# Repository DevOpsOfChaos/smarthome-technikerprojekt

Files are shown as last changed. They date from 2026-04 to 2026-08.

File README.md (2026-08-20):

# smarthome-technikerprojekt

Smart-Home-Grundsystem – Technikerarbeit 2026

## Projektübersicht

Eigenständig entwickeltes, lokal betriebenes Smart-Home-Grundsystem mit selbst aufgebauten Mikrocontrollergeräten, ESP-NOW-Funkkommunikation und Node-RED-Dashboard.

- **Keine Cloud** – alles läuft lokal
- **Keine Herstellerbindung** – ESP32-C3, eigene Platinen, eigene Firmware
- **Vollständig nachvollziehbar** – von der Platine bis zur Bedienoberfläche

## Architektur

```
Geräte (ESP32-C3) ──ESP-NOW──▶ Master ──MQTT──▶ Server (Raspberry Pi)
                                                 ├── Mosquitto (Broker)
                                                 ├── Node-RED (Logik + Dashboard)
                                                 └── SQLite (Persistenz)
```

## Gerätetypen

| Typ | Instanzen | Funktion |
|-----|---|---|
| **net_erl** | Hall-Light, Kitchen | Relais, Umweltsensorik, Bewegung |
| **net_zrl** | Rollladen | 2-Relais-Steuerung, Kalibrierung |
| **net_sen** | Außensensor | BME280, VEML7700, Regensensor |
| **bat_sen** | Regen, Fenster | Batteriebetrieb, Deep-Sleep |

## Repository-Struktur

| Verzeichnis | Inhalt |
|---|---|
| `firmware/` | **Hauptbestandteil** – PlatformIO-Projekt mit Basistypen und konkreten Geräteinstanzen |
| `hardware/` | KiCAD-Schaltpläne, Platinenlayouts, 3D-Modelle |
| `server/` | Docker-Compose-Stack (Mosquitto, Node-RED, SQLite) |
| `docs/` | Technische Dokumentation und Referenz |
| `tests/` | Testskripte und Checklisten |
| `PROTOKOLL/` | Entwicklungs- und Testprotokolle (Nachweise) |
| `esphome/` | ESPHome-Alternativlinie (nicht Bestandteil der Technikerarbeit) |

## Zwei Firmware-Linien

### Eigene Firmware (Hauptlinie)
Die eigene C++-Firmware unter `firmware/` ist der Kern des Technikerprojekts. Sie nutzt:
- **Basistyp-Architektur** – wiederverwendbare Runtime-Klassen (`NetErlRuntime`, `NetSenRuntime`, etc.)
- **ESP-NOW** – direkte Funkkommunikation zwischen Geräten und Master
- **Master-Bridge** – Übersetzung zwischen ESP-NOW und MQTT
- **Vollständige Kontrolle** – Timing, Provisionierung, Fehlerbehandlung in eigenem Code

### ESPHome-Alternative
Unter `esphome/` liegt eine alternative MQTT-Linie für Nutzer, die ESPHome oder Home Assistant bevorzugen. Diese Geräte sprechen direkt MQTT mit demselben Serververtrag. Die ESPHome-Linie ist nicht Bestandteil der Technikerarbeit, sondern eine praktische Erweiterung für Anwender.

## Quick Start

### Server starten
```bash
cd server
docker compose up -d
```
Dashboard: http://localhost:1880/ui

### Firmware bauen
```bash
cd firmware
pio run -e net_erl_hall_light -t upload
```

## Technologien

- **MCU:** ESP32-C3 (RISC-V)
- **Kommunikation:** ESP-NOW (lokal), MQTT (Server)
- **Server:** Node-RED, Mosquitto, SQLite, Docker
- **Firmware:** PlatformIO, Arduino-Framework
- **Hardware:** KiCAD, Eigenentwurf

## Lizenz

All rights reserved. Dieses Repository ist Teil einer schulischen Prüfungsleistung.  
Nach Abschluss der Prüfung behält sich der Autor einen Wechsel auf eine freizügigere Lizenz vor.

## Autor

Manuel Ries – Heinrich-Hertz-Schule Karlsruhe – Technikerarbeit 2026

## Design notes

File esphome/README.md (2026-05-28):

# Alternative MQTT-Linie

Diese Linie ist fuer direkt angebundene MQTT-Geraete vorbereitet. Die Geraete sprechen direkt MQTT mit dem Serververtrag. Es gibt hier keinen ESP-NOW-Master und keine MQTT-Bridge.

Die harte Regel: Topics und Payload-Felder bleiben kompatibel zur bisherigen Firmware, damit Node-RED nur den MQTT-Vertrag sieht.

## Import in Home Assistant

Kopiere den kompletten Ordner in die passende Home-Assistant-Konfiguration, damit die relativen `packages/`-Includes funktionieren.

Danach kannst du die Dateien aus `devices/` importieren oder als neue YAML anlegen. Die benoetigten Secret-Werte liegen in Home Assistant in der zentralen Secret-Datei:

```yaml
wifi_ssid: <dein-wlan-name>
wifi_password: <dein-wlan-passwort>
mqtt_broker: <broker-host-oder-ip>
mqtt_username: <mqtt-benutzer>
mqtt_password: <mqtt-passwort>
ota_password: <starkes-ota-passwort>
```

Wenn dein MQTT-Broker keine Zugangsdaten nutzt, muessen die `username`/`password`-Zeilen in den Device-YAMLs entfernt oder passend ersetzt werden.

Wichtig zur Ordnerstruktur: Die Device-YAMLs nutzen `!include ../packages/...`. Wenn die Geraetedateien unter `/config/esphome/devices/` liegen, muessen die Packages unter `/config/esphome/packages/` liegen. Wenn die gleichen Geraetedateien zusaetzlich direkt unter `/config/esphome/` liegen, wie es das ESPHome-Dashboard oft anzeigt, zeigen die Includes stattdessen auf `/config/packages/`. In diesem Fall muessen die `smarthome_*`-Packages und `setup_portal.h` auch nach `/config/packages/` kopiert werden.

Die ESPHome-YAMLs aktivieren OTA zentral ueber `packages/smarthome_contract_base.yaml`. Deshalb muss die zuerst per Kabel geflashte Factory-Firmware bereits mit demselben `ota_password` gebaut worden sein, sonst kann ein spaeteres Wireless-Update nicht sauber authentifizieren.

Fuer Diagnosezwecke ist in allen ESPHome-Geraeten `logger.level: DEBUG` aktiv. Zusaetzlich stellt `packages/smarthome_contract_base.yaml` die native ESPHome-API mit `reboot_timeout: 0s` und die `debug`-Komponente bereit, damit die Logs im ESPHome-Dashboard von Home Assistant per Netzwerk sichtbar sind. Der MQTT-Vertrag bleibt trotzdem die produktive Server-Schnittstelle; die API ist nur fuer ESPHome-Dashboard, Logs und Diagnose gedacht.

Wichtig bei manuellen Dateien:

- `firmware.factory.bin` ist nur fuer den ersten Flash per Kabel ab Adresse `0x0`.
- `firmware.ota.bin` ist fuer Wireless-Updates.

Eine Factory-Datei per OTA hochzuladen ist kein normales Update. Sie enthaelt Bootloader, Partitionstabelle und App-Image zusammen und ist fuer den Flash-Offset `0x0` gebaut. Fuer OTA muss das reine App-Image verwendet werden.

## Lokale Pruefung

Die YAMLs koennen lokal ohne echte Zugangsdaten geprueft werden. Das Skript legt dafuer eine Arbeitskopie mit Dummy-Secrets an und nutzt einen isolierten PlatformIO-Cache unter einem kurzen lokalen Pfad wie `D:\.sh-esphome\`. Der kurze Pfad ist unter Windows wichtig, weil ESPHome/PlatformIO sonst beim Compile an zu langen Befehlszeilen scheitern kann.

Nur Konfiguration validieren:

```powershell
.\scripts\check_esphome.ps1
```

Ein einzelnes Geraet validieren:

```powershell
.\scripts\check_esphome.ps1 -Device net_erl_hall_module_led_ring
```

Ein einzelnes Geraet kompilieren:

```powershell
.\scripts\check_esphome.ps1 -Device net_erl_hall_module_led_ring -Compile
```

Live-Abgleich gegen die Node-RED-Datenbank auf Home Assistant:

```powershell
.\scripts\check_ha_device_contract.ps1
```

Der Check kopiert nur die SQLite-Datenbank per SSH/SCP in ein temporaeres lokales Verzeichnis und vergleicht sie mit den Device-IDs aus `esphome/devices/`. Er meldet fehlende Geraete, unvollstaendige Metadaten, Offline-/Stale-Zustaende und alte oder falsche IDs, die noch im Server liegen.

Wenn PlatformIO-Tools lokal inkonsistent sind, kann der isolierte lokale Cache hart neu aufgebaut werden:

```powershell
.\scripts\check_esphome.ps1 -CleanPlatformioCache -Compile
```

Der erste Compile kann lange dauern, weil ESPHome und PlatformIO Abhaengigkeiten herunterladen. Echte WLAN- oder MQTT-Secrets gehoeren nicht ins Repo.

Die ESP32-C3-YAMLs pinnen bewusst `toolchain: platformio` und `framework.type: arduino`. ESPHome 2026.5.0 unterstuetzt zusaetzlich einen nativen ESP-IDF-Buildpfad, dieser ist fuer diese produktive MQTT-Linie aber nicht der Zielpfad.

## ESPHome-Toolchain-Reparatur

Wenn der Build in der ESPHome-Umgebung mit fehlendem `tool-cmake`, `idf_tools.py installation failed` oder unvollstaendigen `riscv32-esp-elf`-Tools scheitert, ist zuerst die Toolchain-Installation zu reparieren, nicht die Device-YAML.

Vor dem Loeschen Speicherplatz pruefen:

```sh
df -h
df -i
du -sh /data/cache/platformio 2>/dev/null
du -sh /root/.platformio 2>/dev/null
```

Gezielter Cleanup im Addon-Container:

```sh
rm -rf /data/cache/platformio/packages/tool-cmake
rm -rf /data/cache/platformio/packages/tool-ninja
rm -rf /data/cache/platformio/packages/toolchain-riscv32-esp
rm -rf /data/cache/platformio/packages/framework-espidf
rm -rf /data/cache/platformio/cache

rm -rf /root/.platformio/tools/tool-cmake
rm -rf /root/.platformio/tools/tool-ninja
rm -rf /root/.platformio/tools/riscv32-esp-elf-gdb
rm -rf /root/.platformio/tools/toolchain-riscv32-esp-elf
```

Danach die ESPHome-Umgebung neu starten, im Device Builder die Build-Dateien des betroffenen Geraets bereinigen und erneut kompilieren. Wenn der Fehler bleibt, den kompletten PlatformIO-Cache sichern/neu aufbauen:

```sh
mv /data/cache/platformio /data/cache/platformio.broken.$(date +%Y%m%d-%H%M%S)
```

## Produktive Ersatz-YAMLs

| Datei | MQTT-Device-ID | Zweck |
|---|---:|---|
| `devices/net_erl_hall_module.yaml` | `NET-ERL-010` | Hall-Modul mit Relais, BME280, VEML7700 und PIR |
| `devices/net_erl_hall_module_led_ring.yaml` | `NET-ERL-020` | Hall-Modul LED-Ring mit Relais, Sensorik, Button und LED-Ring |
| `devices/net_sen_weather_station.yaml` | `NET-SEN-020` | Wetterstation mit BME280, VEML7700 und Regen-Digitalpin |
| `devices/net_zrl_shutter_module.yaml` | `NET-ZRL-020` | Rollladenmodul mit zwei Relais, lokalen Tastern, LEDs und Kalibrierung |
| `devices/bat_sen_window_contact.yaml` | `bat_sen_010` | Batterie-Fensterkontakt |
| `devices/bat_sen_rain_sensor.yaml` | `bat_sen_020` | Batterie-Regensensor |

Entscheidend fuer Node-RED ist der MQTT-Vertrag: Topic-Pfad und Payload-Felder.

## MQTT-Vertrag

Alle Geraete senden direkt:

- `smarthome/device/<device_id>/meta` retained
- `smarthome/device/<device_id>/availability` retained
- `smarthome/device/<device_id>/state` retained
- `smarthome/device/<device_id>/ack` nicht retained

Aktoren hoeren auf:

- `smarthome/device/<device_id>/command`

Commands brauchen `request_id`. ACKs geben dieselbe `request_id` zurueck.

## Wichtige Abgrenzung

Diese Linie nutzt:

- kein ESP-NOW
- keinen Master
- keine `master_compat`-Bridge
- keine internen Arbeitsmittel

Home Assistant baut und flasht die Geraete. Node-RED sieht nur MQTT.

## Offene Hardware-Validierung

Die YAMLs sind vertraglich und pinseitig vorbereitet. Vor produktivem Einsatz musst du trotzdem je Board testen:

- Relaisrichtung und Active-Level
- Rollo-Auf/Ab-Verriegelung und Endlagen
- Taster-Pegel beim NET-ZRL
- Batterie-ADC-Kalibrierung
- Regen-ADC-Schwellwerte
- Sensoradressen bei BME/VEML/ENS160

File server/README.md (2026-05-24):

# Server

Bereichs-README fuer `server/`.
Dieser Stand bleibt bewusst klein und kontrolliert.

Nicht diese Datei:

- Gesamtarchitektur und Entscheidungen: `../docs/README.md`, `../docs/DECISIONS.md`
- belegter Gesamtstatus: `../docs/14_test_und_nachweisstand.md`

## Rolle der Serverbasis

Der Server liefert die kleine serverseitige Grundlage plus einen engen Dashboard-Schnitt:

- Mosquitto
- Node-RED mit kleinem FlowFuse-Dashboard
- SQLite als Snapshot-Persistenz

## Scope

- MQTT-Ingest fuer die engen aktuellen Themen
- Topic-Routing in Device- und Masterpfad
- gemeinsames Laufzeitobjekt pro Geraet
- separater Masterzustand
- minimale SQLite-Persistenz fuer `devices`, `device_state_latest`, `master_status`, `automations` und `automation_conditions`
- eine zentrale Geraeteuebersicht
- eine versteckte Detailseite pro Geraet
- eine Master-Statusseite (nur Anzeige, keine Steuerung)
- eine Automatisierungsseite (CRUD: erstellen, anzeigen, bearbeiten, loeschen)
- Aktorsteuerung im engen aktuellen Rahmen

## Bewusst nicht Teil dieser Stufe

- Zeitreihen
- Diagramme
- Wetter
- volle Logs- oder MQTT-Konsole
- Commands als breite Komfortwelt
- Freie JavaScript-Automatisierungen oder Blockly-Editor
- Verschachtelte Bedingungsbaeume (nur AND-Verknuepfung, 6 Operatoren)
- SIM-spezifischer Ausbau
- grosse Konfigurationswelt

## Bereichsdoku

- `../docs/public/server/01_server_v1_ueberblick.md`
- `../docs/public/server/02_phase1_mqtt_ingest_geraeteobjekt.md`
- `../docs/public/server/03_phase1_dateirollen.md`
- `flows/README.md`
- `db/README.md`
- `nodered/README.md`

## Start

Im Ordner `server/`:

1. optional `Copy-Item .env.example .env`
2. lokale Werte in `.env` setzen
3. `docker compose up --build -d`
4. `docker compose ps`

Der echte Startpfad liegt aktuell direkt in `docker-compose.yml`:
- Node-RED startet aus dem offiziellen `nodered/node-red:3.1`-Image.
- Node-RED nutzt `MQTT_HOST` und `MQTT_PORT` aus `.env`; ohne `.env` ist der Compose-Broker `mosquitto` der Default.
- SQLite-Schema, kleine Bestandsschema-Migrationen, `flows.json` und die generierten Settings werden beim Containerstart inline vorbereitet.
- `nodered/settings.js` bleibt die Basisdatei, die Laufzeit erweitert sie beim Start um den benoetigten `functionGlobalContext`.

Wenn ein dauerhaft laufender Mosquitto im Netz genutzt wird, muss `server/.env` denselben Broker setzen, den auch die ESPHome-Secrets verwenden:

```env
MQTT_HOST=<broker-ip-oder-hostname>
MQTT_PORT=1883
```

Der wichtigste Fehlerfall ist ein Broker-Split: ESPHome publiziert an einen Netz-Broker, Node-RED hoert aber auf dem Compose-Broker, oder umgekehrt. Dann sind die YAMLs formal korrekt, aber im Dashboard kommt nichts an.

## Enger Vertragstest

Aus dem Repo-Root:

```powershell
.\tests\server\server_contract_smoke.ps1
```

Wenn der Stack bereits laeuft:

```powershell
.\tests\server\server_contract_smoke.ps1 -SkipStart
```

Der Test prueft den aktuellen Server-Vertrag fuer numerische `caps`, `button_flags`, ACK-bezogene Felder im aktuellen Snapshot und SQL-/Migrationsfehler beim Start.
Er nutzt `mosquitto_pub` im Compose-Service `mosquitto`; auf dem Host muss dieses Tool dafuer nicht lokal installiert sein.
Der Test ist ein enger Smoke-Test des Serververtrags, kein vollstaendiger End-to-End-Systemtest.

## Offizielle Serverdateien

- `docker-compose.yml`
- `.env.example`
- `sqlite/00_schema_phase1.sql`
- `nodered/settings.js`
- `nodered/flows/active/*.json`
- `nodered/lib/*.js`

## Lokal, nicht versioniert

- `.env`
- `config/.env`
- `config/mosquitto/config/` inklusive lokaler Auth-Dateien
- lokale Compose-Overrides

## Ehrliche Grenze

Wenn spaeter Zusatzfunktionen dazukommen sollen, muessen sie auf diesem kleinen Snapshot-, Anzeige- und Steuerkern aufbauen.
Der aktuelle Stand ist absichtlich nicht die Komfortebene.

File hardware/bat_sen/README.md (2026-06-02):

# BAT-SEN — Batteriebetriebener Sensor-Knoten (Basetype)

> `device_class: bat_sen` | `SH_CLASS_BAT_SEN (0x04)`

## Übersicht

BAT-SEN ist der Basetype für **batteriebetriebene Sensor-Knoten** mit Deep-Sleep. Optimiert für minimale Ruhestromaufnahme.

## KiCAD-Quellen

👉 **[kicad/](kicad/)** — Vollständiges KiCAD-Projekt

| Datei | Beschreibung |
|---|---|
| `bat_sen.kicad_pro` | Projektdatei |
| `bat_sen.kicad_sch` | Root-Schaltplan (hierarchisch) |
| `Leistungskreis.kicad_sch` | Sub-Sheet: Power-Gating, Batterie |
| `Steuerstromkreis.kicad_sch` | Sub-Sheet: ESP32 + I²C |
| `bat_sen.kicad_pcb` | PCB-Layout (2-Lagen) |
| `Pinbelegung/Pinbelegung.txt` | GPIO-Belegung |
| `Code/SamplecodeBasis.txt` | ESP-NOW Deep-Sleep Beispiel |
| `production/` | BOM, Position, Netlist |

### SVG-Schaltpläne

- [schematics/bat_sen.svg](schematics/bat_sen.svg) — Root
- [schematics/bat_sen-Leistungskreis.svg](schematics/bat_sen-Leistungskreis.svg) — Power-Gating
- [schematics/bat_sen-Steuerstromkreis.svg](schematics/bat_sen-Steuerstromkreis.svg) — ESP32

## Stromspar-Design

- **Power-Gating:** P-MOSFET (IRF9530, SOT-23) schaltet Sensoren im Deep-Sleep ab
- **Zener-Diode:** BZX55C3V3 (DO-35) — Überspannungsschutz
- **Spannungsteiler:** R2+R5 (100K+100K) an GPIO4 — Batterieüberwachung
- **Deep-Sleep:** ~0.5–0.8 mA Board-Gesamtstrom
- **Wake-Up:** Timer (RTC) oder externer Interrupt

## Pinbelegung (Basetype)

| GPIO | Funktion | Bemerkung |
|---|---|---|
| GPIO0 | I²C SDA | Optional |
| GPIO1 | I²C SCL | Optional |
| GPIO2 | Setup-Button | Lokaler Setup-/Bring-up-Taster |
| GPIO4 | V-Mess (ADC) | Batteriespannung via Spannungsteiler |
| GPIO3–10 | frei | Pinheader |
| GPIO20/21 | UART | Debug |

## Batterie-Profile

| Profil | Typ | Spannung | Kapazität |
|---|-----|---|---|
| `BAT_PROFILE_CR2032` | CR2032 | 3.0V | ~225 mAh |
| `BAT_PROFILE_2X_AA` | 2× AA | 3.0V | ~2500 mAh |
| `BAT_PROFILE_2X_AAA` | 2× AAA | 3.0V | ~1000 mAh |

## Geräte (Devices)

| Gerät | ID | Sensoren | Batterie |
|---|-----|---|---|
| 👉 [bat_sen_01](devices/bat_sen_01_window_contact/) | Fensterkontakt | Reed-Schalter | 2x AAA in Serie |
| 👉 [bat_sen_02](devices/bat_sen_02_rain_sensor/) | Regensensor | ADC-Regensensor | 2× AA |

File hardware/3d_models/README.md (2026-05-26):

# 3D-Modelle

STEP-Dateien der Platinen und Gehäuse für das Smart-Home-Grundsystem.

## Übersicht

| Datei | Gerät | Beschreibung |
|---|---|---|
| *(wird nach Import ergänzt)* | | |

Die Modelle können mit FreeCAD (kostenlos) oder Fusion 360 geöffnet werden.

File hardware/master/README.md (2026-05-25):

# Master-Bridge (Basetype)

> ESP-NOW ↔ MQTT Bridge | `device_class: master` | `SH_CLASS_MASTER (0xFE)`

## Übersicht

Der Master ist die zentrale Bridge zwischen dem ESP-NOW-Mesh-Netzwerk und dem MQTT-Server (Node-RED auf Raspberry Pi).

> **Kein eigenes PCB-Design.** Der Master verwendet das ESP32-C3 SuperMini Plus V2.0 direkt — ohne Trägerplatine.

## Hardware

| Eigenschaft | Wert |
|---|---|
| Board | TENSTAR ESP32-C3 SuperMini Plus V2.0 |
| Mikrocontroller | Espressif ESP32-C3 (RISC-V, 160 MHz) |
| Flash / SRAM | 4 MB / 400 KB |
| Versorgung | 5V DC via USB-C |
| Betriebsmodus | Dauerbetrieb (kein Sleep) |
| WLAN | 2.4 GHz, verbunden mit lokalem Netzwerk |
| MQTT-Broker | mosquitto auf Raspberry Pi |

## Aufbau

```
┌─────────────────────────────────┐
│  ESP32-C3 SuperMini Plus V2.0   │
│                                 │
│  ┌───────────────┐              │
│  │   USB-C       │── 5V Power   │
│  ├───────────────┤              │
│  │   ESP32-C3    │              │
│  │   RISC-V MCU  │              │
│  ├───────────────┤              │
│  │   PCB-Antenne │              │
│  │   + U.FL      │              │
│  ├───────────────┤              │
│  │   WS2812 LED  │── GPIO8      │
│  │   (Status)    │              │
│  └───────────────┘              │
│                                 │
│  Keine externe Beschaltung      │
│  Keine Trägerplatine            │
│  Keine Sensoren                 │
└─────────────────────────────────┘
```

## Pin-Nutzung

| GPIO | Funktion | Bemerkung |
|---|---|---|
| GPIO8 | WS2812 RGB-LED | Statusanzeige (onboard) |
| GPIO20 | UART RX | Debug (intern) |
| GPIO21 | UART TX | Debug (intern) |

> Alle anderen GPIOs sind unbelegt. Der Master hat keine Sensoren, keine Relais, keine Taster.

## ESP-NOW ↔ MQTT Datenfluss

```
  BAT-SEN ──┐
  NET-SEN ──┼── ESP-NOW ──►  Master  ── MQTT ──►  Node-RED (RPi)
  NET-ERL ──┤               (dieses              │
  NET-ZRL ──┘                Gerät)              ├─ SQLite
                                                  └─ Dashboard
```

## Firmware

- **Verzeichnis:** `firmware/src/basetypes/master_firmware/`
- **main.cpp:** ~2700 Zeilen
- **Plattform:** PlatformIO, `espressif32`, Arduino-Framework

### Kernfunktionen
- ESP-NOW Peer-Management (dynamische Registry)
- MQTT-Ingest-Pipeline (smarthome/device/+/state)
- JSON-Serialisierung aller Gerätezustände
- Hello/Heartbeat-Tracking
- Diagnose-Endpunkte

## Geräte-ID

- **Primär:** `MASTER-001`
- **Sekundär (Fallback):** `MASTER-002`

## Unterschiede zu anderen Basetypes

| Eigenschaft | Master | net_erl / net_zrl | net_sen / bat_sen |
|---|---|---|---|
| Eigenes PCB | ❌ | ✅ (modular) | ✅ (einteilig) |
| KiCAD-Projekt | ❌ | ✅ | ✅ |
| Sensoren | ❌ | optional (I²C) | ✅ |
| Aktoren | ❌ | ✅ (Relais) | ❌ |
| Sleep | ❌ | ❌ | bat_sen: ✅ |
| WLAN | ✅ (dauerhaft) | ❌ (nur ESP-NOW) | ❌ (nur ESP-NOW) |
| MQTT | ✅ | ❌ | ❌ |

## Plattform-Referenz

👉 [../shared/esp32-c3-supermini.md](../shared/esp32-c3-supermini.md) — Technische Daten des ESP32-C3 SuperMini Plus

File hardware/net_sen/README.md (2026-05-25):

# NET-SEN — Netzbetriebener Sensor-Knoten (Basetype)

> `device_class: net_sen` | `SH_CLASS_NET_SEN (0x03)`

## Übersicht

NET-SEN ist der Basetype für **dauerhaft netzbetriebene Sensor-Knoten**. Kein Sleep — immer online.

## KiCAD-Quellen

👉 **[kicad/](kicad/)** — Vollständiges KiCAD-Projekt

| Datei | Beschreibung |
|---|---|
| `net_sen.kicad_pro` | Projektdatei |
| `net_sen.kicad_sch` | Root-Schaltplan (hierarchisch) |
| `Leistungskreis.kicad_sch` | Sub-Sheet: 230V-Netzteil |
| `Steuerstromkreis.kicad_sch` | Sub-Sheet: ESP32 + I²C |
| `net_sen.kicad_pcb` | PCB-Layout (2-Lagen) |
| `Bilder/` | Layout-Ansichten (7 PNGs) |
| `production/` | BOM, Position, Netlist |

### SVG-Schaltpläne

- [schematics/net_sen.svg](schematics/net_sen.svg) — Root
- [schematics/net_sen-Leistungskreis.svg](schematics/net_sen-Leistungskreis.svg) — Netzteil
- [schematics/net_sen-Steuerstromkreis.svg](schematics/net_sen-Steuerstromkreis.svg) — ESP32

## Platinen-Design

Einteiliger Aufbau (nicht modular):

- **HLK-PM03:** 230V AC → 3.3V DC
- **Feinsicherung:** 5×20mm
- **I²C:** GPIO0/1 mit 4K7 Pullups (Lötbrücken)
- **230V-Eingang:** Phoenix MKDS 1.5/3

## Pinbelegung (Basetype)

| GPIO | Funktion |
|---|---|
| GPIO0 | I²C SDA |
| GPIO1 | I²C SCL |
| GPIO2–10 | frei (Pinheader) |
| GPIO20/21 | UART |

## Versionen

1. **Standard Version** (aktiv) — im Ordner [kicad/](kicad/)
2. **Version mit TCA9548APWR** — Mit I²C-Multiplexer (separater KiCAD-Ordner)

## Geräte (Devices)

| Gerät | ID | Sensoren |
|---|-----|---|
| 👉 [NET-SEN-002](devices/NET-SEN-002_weather_station/) | Wetterstation | BME280, VEML7700, Regensensor |

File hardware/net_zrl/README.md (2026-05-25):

# NET-ZRL — 2-Relais-Knoten / Rolladen (Basetype)

> `device_class: net_zrl` | `SH_CLASS_NET_ZRL (0x02)`

## Übersicht

NET-ZRL ist der Basetype für **netzbetriebene 2-Relais-Knoten** mit Rolladen-/Cover-Steuerung. Sicherheitsschaltung durch serielle Relais-Verdrahtung.

## KiCAD-Quellen

| Platine | Pfad | Typ |
|---|---|-----|
| 🔑 Modularer Steuerkreis | [../shared/modularer_steuerkreis/](../shared/modularer_steuerkreis/) | **Identisch mit net_erl!** |
| ⚡ Leistungskreis (230V) | [leistungskreis/](leistungskreis/) | NET-ZRL-spezifisch (2 Relais) |

### Leistungskreis (2-Relais)

👉 **[leistungskreis_2relais.md](leistungskreis_2relais.md)** — Vollständige Doku mit BOM

→ KiCAD: `Leistungskreis_korrektur.{kicad_pro,sch,pcb}` im Ordner [leistungskreis/](leistungskreis/)

→ SVG-Schaltplan: [schematics/leistungskreis.svg](schematics/leistungskreis.svg)

→ **Wichtig:** N-Kanal MOSFETs (IRLZ34N), 2× Optokoppler, Serien-Sicherheitsschaltung

### Steuerkreis

👉 **[../shared/modularer_steuerkreis.md](../shared/modularer_steuerkreis.md)** — **Derselbe** wie bei net_erl!

→ KiCAD: [../shared/modularer_steuerkreis/](../shared/modularer_steuerkreis/)

→ SVG: [../shared/schematics/steuerkreis.svg](../shared/schematics/steuerkreis.svg)

## Pinbelegung (Basetype)

| GPIO | Funktion | Bemerkung |
|---|---|---|
| GPIO0 | I²C SDA | Optional |
| GPIO1 | I²C SCL | Optional |
| GPIO5 | Trigger_PIN2 | Relais 2 / Runter (via PC817) |
| GPIO10 | Trigger_PIN1 | Relais 1 / Hoch (via PC817) |
| GPIO20 | RX | UART Debug |
| GPIO21 | TX | UART Debug |

## Geräte (Devices)

| Gerät | ID | Besonderheiten |
|---|-----|---|
| 👉 [NET-ZRL-002](devices/NET-ZRL-002_shutter_module/) | Rolladensteuerung | 2 Relais, 3 Taster, Kalibrierung |

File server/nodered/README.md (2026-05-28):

# Node-RED

Dieser Ordner enthaelt die kleine Node-RED-Laufzeit fuer den engen Server-/Dashboard-Pfad.

- `flows/active/` enthaelt die produktiven Flow-Fragmente
- `lib/` enthaelt kleine Hilfsmodule fuer Routing, Handler und SQL-Bausteine
- `settings.js` ist die Basis fuer die Node-RED-Settings
- der echte Startpfad liegt aktuell in `../docker-compose.yml`: dort werden SQLite, Bestandsschema-Migrationen, `flows.json` und die erweiterten Settings beim Containerstart inline erzeugt

Aktiv enthalten:
- MQTT-Ingest
- Geräte- und Master-Store
- kleines FlowFuse-Dashboard mit Übersicht und Detailseite
- Automatisierungsseite mit SQLite-Persistenz und minütlichem Runner

Bewusst nicht Teil dieser Stufe:
- Wetterpfad
- Diagramme
- Command-Komfort
- grosse Generatorlogik

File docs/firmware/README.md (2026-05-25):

# SmartHome Technikerprojekt — Firmware-Dokumentation

Dieses Verzeichnis enthält die vollständige technische Dokumentation aller 6 ESP32-C3-basierten SmartHome-Geräte, des ESP-NOW Binärprotokolls, der MQTT-Verträge und der Device-Typen/Capabilities.

## Dokumentationsstruktur

| Datei | Beschreibung | Größe |
|---|---|---|
| `01_espnow_protokoll_referenz.md` | ESP-NOW Binary Protocol: Header, Payloads, CRC, Event-System | 28 KB |
| `02_devicetypes_capabilities.md` | Device-Klassen, Power-Typen, Control-Modes, Profile, Capability-Bitmask | 7.5 KB |
| `03_mqtt_contract_referenz.md` | MQTT Topics, JSON-Schemata, ACK-Mechanismus, Cover-Contract | 14.5 KB |
| `devices/NET-ERL-001_hall_module.md` | Flurmodul (PIR+BME280+VEML7700+Relais) | 16.5 KB |
| `devices/NET-ERL-002_hall_module_led_ring.md` | Erweit. Flurmodul (Radar+BME680+ENS160+NeoPixel+Relais) | 19.4 KB |
| `devices/NET-ZRL-002_shutter_module.md` | Rollladenmodul (2 Relais, 3 Taster, Kalibrierung, Positionsschätzung) | ~600 Zeilen |
| `devices/NET-SEN-002_weather_station.md` | Wettersensor (BME280+VEML7700+digitaler Regen) | 12 KB |
| `devices/bat_sen_01_window_contact.md` | Batterie-Fensterkontakt (Reed, CR2032, GPIO-Wake) | 9.7 KB |
| `devices/bat_sen_02_rain_sensor.md` | Batterie-Regensensor (ADC, Hysterese, Timer-Wake) | 12.7 KB |

## Device Comparison Matrix

| Merkmal | NET-ERL-001 | NET-ERL-002 | NET-ZRL-002 | NET-SEN-002 | bat_sen_01 | bat_sen_02 |
|---|---|---|---|---|---|---|
| Klasse | NET_ERL (0x01) | NET_ERL (0x01) | NET_ZRL (0x02) | NET_SEN (0x03) | BAT_SEN (0x04) | BAT_SEN (0x04) |
| Strom | Mains | Mains | Mains | Mains | CR2032 | 2x AA |
| Leistung | relais_light | relais_light | cover | none | none | none |
| Profil | hall_light | hall_module_led_ring | cover_basic | none | none | none |
| Reporting | hybrid | hybrid | hybrid | hybrid | sleep_event | sleep_event |
| Sensoren | BME280, VEML7700, PIR | BME680, VEML7700, ENS160, LD2410 | — | BME280, VEML7700, Rain | Reed (GPIO) | ADC Rain |
| Aktoren | 1 Relais | 1 Relais + NeoPixel | 2 Relais (Cover) | — | — | — |
| Taster | — | 1 (GPIO6, akt-low) | 3 (GPIO20/4/3) | — | — | — |
| Status-LEDs | — | — | 2 (Auf=GPIO7, Ab=GPIO6, akt-high) | — | — | — |
| ESP-NOW Payload | 31B (Config) | 45B (Gas+Config) | 25B (Config) | 24–36B (ext) | 24B | 24B |
| Wake | n/a | n/a | n/a | n/a | GPIO+Timer | Timer (900s) |
| Setup-Portal | Ja | Ja | Ja | Ja | Ja | Ja |

## Design Principles

- **Base type architecture** — `NetErlRuntime`, `NetSenRuntime`, `BatSenRuntime`
- **Device-specific hooks pattern** — Hooks for `on_config`, `on_sensor`, `on_control`
- **ESP-NOW retry mechanism** — 2 retries, 50 ms interval
- **Sensor recovery** — damped error logging, automatic re-init
- **Late-Lux principle** — auto-light waits for stable lux after PIR trigger
- **Kalibrierung mit Rollback** — persistent config with rollback on write failure

## Quick Links

- ESP-NOW Protokoll: [01_espnow_protokoll_referenz.md](01_espnow_protokoll_referenz.md)
- Device-Typen: [02_devicetypes_capabilities.md](02_devicetypes_capabilities.md)
- MQTT Vertrag: [03_mqtt_contract_referenz.md](03_mqtt_contract_referenz.md)
- Alle Devices: [devices/](devices/)

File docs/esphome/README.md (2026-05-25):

# ESPHome-Geräte – Dokumentation

## Übersicht

Die ESPHome-Linie ist eine alternative Firmware-Implementierung für Smarthome-Geräte.
Im Gegensatz zur Firmware-Linie (ESP-NOW → Master → MQTT) kommunizieren ESPHome-Geräte
**direkt per MQTT** mit dem Server – ohne ESP-NOW-Master als Zwischeninstanz.

## Architektur

```
┌──────────────┐   MQTT direkt   ┌──────────┐
│ ESPHome-Gerät│◄──────────────►│  Server  │
│  (ESP32-C3)  │   JSON         │(Node-RED)│
└──────────────┘                 └──────────┘
```

**Kein Master, kein ESP-NOW.** Jedes Gerät ist ein eigenständiger MQTT-Client
mit vollständiger Topic-Verwaltung (Birth/Last-Will, Meta, State, Events, Commands).

## Geräte-Übersicht

| Gerät | ESPHome-ID | Typ | Sensoren | Besonderheiten |
|---|---|-----|---|---|
| [NET-ERL-010](devices/NET-ERL-010_hall_module.md) | `NET-ERL-010` | Netz | BME280, VEML7700, PIR | 1 Relais, Motion-Event |
| [NET-ERL-020](devices/NET-ERL-020_hall_module_led_ring.md) | `NET-ERL-020` | Netz | BME680, VEML7700, ENS160, LD2410 | 1 Relais, LED-Ring, Auto-Light |
| [NET-SEN-020](devices/NET-SEN-020_weather_station.md) | `NET-SEN-020` | Netz | BME280, VEML7700 | Regensensor (GPIO) |
| [NET-ZRL-020](devices/NET-ZRL-020_shutter_module.md) | `NET-ZRL-020` | Netz | — | 2 Relais, Cover-Kalibrierung |
| [bat_sen_010](devices/bat_sen_010_window_contact.md) | `bat_sen_010` | Batterie | Reed-Kontakt | Deep-Sleep (15 min), Fenster-Event |
| [bat_sen_020](devices/bat_sen_020_rain_sensor.md) | `bat_sen_020` | Batterie | Regensensor (ADC) | Deep-Sleep (15 min), Regen-Event |

## Gemeinsame Konzepte

### MQTT-Vertrag
Alle ESPHome-Geräte implementieren denselben MQTT-Vertrag wie die Firmware-Linie.
Siehe [Firmware MQTT-Contract](../firmware/03_mqtt_contract_referenz.md) für Details.

Die ESPHome-Linie verwendet eigene Geräte-IDs (3-stelliger Suffix, z.B. `NET-ERL-020`).
MQTT-Topics sind case-sensitiv – ESPHome-IDs nutzen Kleinbuchstaben mit Underscore
für Batteriegeräte (`bat_sen_010`).

### Events
Alle Geräte publizieren Ereignisse auf `smarthome/device/{id}/event`:
- Bewegung, Fenster, Regen, Taster, Relais-Schaltung
- 18 Event-Typen mit Trigger-Quelle und Parametern

### Sensor-Offset
Temperatur und Feuchte können über YAML-Substitutions (`temp_offset_01c`,
`hum_offset_01pct`) kalibriert werden. Offsets in Zehntelgrad/-prozent.

### Setup-Modus
Jedes Gerät kann durch langes Drücken des Setup-Tasters (5 s) in den
Setup-Modus versetzt werden. Der Setup-Modus startet einen WiFi-Access-Point
(SSID = Geräte-ID) mit Webinterface zur Konfiguration von Master-MAC und
Geräteparametern.

### Code-Struktur
Jedes ESPHome-Gerät besteht aus:
- **Device-YAML** (`esphome/devices/{name}.yaml`): Gerätespezifische Konfiguration
- **Shared Packages** (`esphome/packages/`): Wiederverwendbare Bausteine
  - `smarthome_contract_base.yaml`: MQTT-Meta, Availability, Provisioning-UI
  - `smarthome_command_ack.yaml`: Kommando-ACK-System
  - `smarthome_device_event.yaml`: Event-Publishing
  - `smarthome_cover_contract.yaml`: Rollladen-Logik (nur NET-ZRL)
  - `smarthome_command_dispatch.h`: C++ Shared-Funktionen (MAC-Validierung)

## Unterschiede zur Firmware-Linie

| Aspekt | ESPHome | Firmware |
|---|---|---|
| Kommunikation | MQTT direkt | ESP-NOW → Master → MQTT |
| Konfiguration | YAML-Substitutions | C++ DeviceConfig.h |
| Sensor-Filter | 16× Oversampling + IIR | EMA-Filter (α=0,2) |
| Events | Alle 18 Typen | 15 Typen (nur ESP-NOW) |
| Deep-Sleep | ESPHome `deep_sleep` | Manuelle `esp_deep_sleep_start()` |
| Cover | `smarthome_cover_contract.yaml` | Inline C++ State-Machine |

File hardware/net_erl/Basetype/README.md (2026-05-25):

# NET-ERL — 1-Relais-Knoten (Basetype)

> `device_class: net_erl` | `SH_CLASS_NET_ERL (0x01)`

## Übersicht

NET-ERL ist der Basetype für **netzbetriebene 1-Relais-Knoten**. Einsatz: Lampen, Steckdosen, Flurlicht-Steuerung.

## KiCAD-Quellen

| Platine | Pfad | Typ |
|---|---|-----|
| 🔑 Modularer Steuerkreis | [../shared/modularer_steuerkreis/](../shared/modularer_steuerkreis/) | Gemeinsam mit net_zrl |
| ⚡ Leistungskreis (230V) | [leistungskreis/](leistungskreis/) | NET-ERL-spezifisch |
| 🔬 Simulation | [simulation/](simulation/) | LTSpice |

### Leistungskreis

👉 **[leistungskreis_1relais.md](leistungskreis_1relais.md)** — Vollständige Doku mit BOM und Schaltungsdesign

→ KiCAD: `Leistungskreis_1Relai_korrektur.{kicad_pro,sch,pcb}` im Ordner [leistungskreis/](leistungskreis/)

→ SVG-Schaltplan: [schematics/leistungskreis.svg](schematics/leistungskreis.svg)

### Steuerkreis

Der Steuerkreis ist **identisch** mit dem von net_zrl:

👉 **[../shared/modularer_steuerkreis.md](../shared/modularer_steuerkreis.md)** — Vollständige Doku

→ KiCAD: [../shared/modularer_steuerkreis/](../shared/modularer_steuerkreis/)

→ SVG: [../shared/schematics/steuerkreis.svg](../shared/schematics/steuerkreis.svg)

## Pinbelegung (Basetype)

| GPIO | Funktion | Bemerkung |
|---|---|---|
| GPIO0 | I²C SDA | Sensoren (optional) |
| GPIO1 | I²C SCL | Sensoren (optional) |
| GPIO5 | Trigger_PIN2 | NC bei 1-Relais |
| GPIO10 | Trigger_PIN1 | Relais (via PC817) |
| GPIO20 | RX | UART Debug |
| GPIO21 | TX | UART Debug |

## Geräte (Devices)

| Gerät | ID | Sensoren |
|---|-----|---|
| 👉 [NET-ERL-001](devices/NET-ERL-001_hall_module/) | Flurmodul Basis | BME280, VEML7700, PIR |
| 👉 [NET-ERL-002](devices/NET-ERL-002_hall_module_led_ring/) | Flurmodul LED-Ring | BME680, VEML7700, ENS160, LD2410, NeoPixel |

→ Jedes Gerät hat eigene GPIO-Belegung und Sensor-Konfiguration. Siehe jeweiligen Device-Ordner.

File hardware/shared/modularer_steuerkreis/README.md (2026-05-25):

# Modularer Steuerkreis — KiCAD-Projekt

> Gemeinsame Steuerplatine für ALLE Relais-Knoten (`net_erl` und `net_zrl`)

## Dateien

| Datei | Beschreibung |
|---|---|
| `steuerkreis.kicad_pro` | KiCAD 9.0 Projektdatei |
| `steuerkreis.kicad_sch` | Schaltplan (flat schematic) |
| `steuerkreis.kicad_pcb` | PCB-Layout (2-Lagen, 1.6mm) |
| `mod_Steuerkreis_ESP32.kicad_prl` | PCB-Regeln |
| `steuerkreis.csv` | Bauteilliste |
| `steuerkreis.step` | 3D-Modell (STEP-Export) |
| `Pinbelegung/Pinbelegung.txt` | GPIO-Belegung |
| `production/` | Fertigungsdaten (BOM, Position, Netlist) |

## Verwendung

Dieser Steuerkreis wird mit zwei verschiedenen Leistungskreisen kombiniert:

- **[net_erl](../../net_erl/leistungskreis/)** — 1-Relais-Leistungskreis
- **[net_zrl](../../net_zrl/leistungskreis/)** — 2-Relais-Leistungskreis

Die Verbindung erfolgt über ein 5-poliges JST-PH-Kabel.

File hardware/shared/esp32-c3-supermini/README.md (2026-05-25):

# ESP32-C3 SuperMini THT-Adapter — KiCAD-Dateien

> Through-Hole-Adapterplatine für das TENSTAR ESP32-C3 SuperMini Plus V2.0

## Dateien

| Datei | Beschreibung |
|---|---|
| `ESP32-C3_SUPERMINI_TH.kicad_sym` | KiCAD-Schaltsymbol |
| `MODULE_ESP32-C3_SUPERMINI_TH.kicad_mod` | KiCAD-Footprint (THT) |
| `ESP32-C3_SUPERMINI_TH.step` | 3D-Modell |
| `how-to-import.htm` | Import-Anleitung |

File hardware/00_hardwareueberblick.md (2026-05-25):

# Hardware-Übersicht

> Stand: Mai 2026 | Plattform: ESP32-C3 (RISC-V) | Entwicklung: KiCAD 9.0

## Architektur

Alle Geräte basieren auf dem **TENSTAR ESP32-C3 SuperMini Plus V2.0** (ESP32-C3, RISC-V 32-Bit, 160 MHz, 4 MB Flash, 400 KB SRAM, WLAN b/g/n, BLE 5.0). Der Mikrocontroller wird über eineThrough-Hole-Adapterplatine (`ESP32-C3_SUPERMINI_TH`) auf die Trägerplatinen gesteckt.

Die Kommunikation erfolgt über **ESP-NOW** (Node → Master) und **MQTT** (Master → Server).

## Geräteklassen

| Klasse | Typ | Platinen-Design | Versorgung | Anzahl |
|---|-----|---|---|---|
| `net_erl` | 1-Relais-Knoten | Relais_1fach (modular) | 230V (HLK-5M05) | 2 Geräte |
| `net_zrl` | 2-Relais-Knoten (Rolladen) | Relais_2fach (modular) | 230V (HLK-5M05) | 1 Gerät |
| `net_sen` | Netz-Sensor | Sensor_Netzbetrieb | 230V (HLK-PM03) | 1 Gerät |
| `bat_sen` | Batterie-Sensor | Sensor_Batteriebetrieb | Akku/Batterie | 2 Geräte |
| `master` | ESP-NOW↔MQTT Bridge | — | 230V | 1 Gerät |

## Modularer Platinenaufbau (Relais-Knoten)

Alle Relais-Knoten (`net_erl`, `net_zrl`) verwenden einen **zweiteiligen, modularen Aufbau**:

1. **Modularer Steuerkreis** (`mod_Steuerkreis_ESP32`) — **identisch für alle Relais-Varianten**
   - ESP32-C3 SuperMini auf THT-Adapter
   - I²C-Pullups (4K7, über Lötbrücken schaltbar)
   - GPIO-Pinheader für Sensoren
   - 5 Testpunkte für Debugging
   - 2× M3-Befestigungslöcher

2. **Leistungskreis** — **variiert je nach Relais-Typ**
   - `net_erl`: 1× Relais (HF46F), 1× P-Kanal MOSFET (FQP27P06), 1× Optokoppler (PC817)
   - `net_zrl`: 2× Relais (HF46F), 2× N-Kanal MOSFET (IRLZ34N), 2× Optokoppler (PC817)
   - Beide: Hi-Link ACDC-Wandler (230V→5V), Feinsicherung (5×20mm), 230V-Klemmen

Die beiden Platinen werden über ein 5-poliges JST-PH-Kabel verbunden (5V, GND, GPIO10, GPIO5, 3V3).

## Pinbelegungs-Matrix (alle Geräteklassen)

| GPIO | BAT-SEN | NET-SEN | NET-ERL | NET-ZRL | Funktion |
|---|---|---|---|---|---|
| 0 | I²C SDA | I²C SDA | I²C SDA | I²C SDA | I²C-Daten |
| 1 | I²C SCL | I²C SCL | I²C SCL | I²C SCL | I²C-Takt |
| 2 | V-Mess (Batterie) | frei | NC | NC | Batterie-ADC |
| 3 | frei | frei | NC | NC | — |
| 4 | frei | frei | LED-Ring (NET-ERL-002) | NC | WS2812-Datenpin beim LED-Ring-Modul |
| 5 | frei | frei | Trigger_PIN2 | Trigger_PIN2 (Runter) | Relais 2 |
| 6 | frei | frei | frei | frei | — |
| 7 | frei | frei | frei | frei | — |
| 8 | frei | frei | frei | frei | (Onboard-LED) |
| 9 | frei | frei | NC | NC | — |
| 10 | frei | frei | Trigger_PIN1 | Trigger_PIN1 (Hoch) | Relais 1 |
| 20 | RX | RX | RX | RX | UART RX |
| 21 | TX | TX | TX | TX | UART TX |

## Stromversorgungs-Designs

| Typ | Eingang | Wandler | Ausgang | Besonderheit |
|-----|---|---|---|---|
| BAT-SEN | Akku (3.0–4.2V) | — (P-MOSFET Gate, Zener-Schutz) | 3.3V (LDO on ESP) | Deep-Sleep optimiert |
| NET-SEN | 230V AC | HLK-PM03 | 3.3V DC | Feinsicherung |
| NET-ERL (Leistung) | 230V AC | HLK-5M05 | 5V DC | Versorgt Relais-Spule + ESP |
| NET-ZRL (Leistung) | 230V AC | HLK-5M05 | 5V DC | Versorgt 2× Relais-Spule + ESP |

## Zentrale Designmuster

1. **I²C-Lötbrücken (JP1/JP2):** Auf allen Platinen können die 4K7-Pullups für I²C per Lötbrücke ein-/ausgeschaltet werden
2. **Optokoppler-Isolation (PC817):** Galvanische Trennung zwischen ESP-GPIO und Relais-MOSFET-Treibern
3. **Freilaufdioden (1N4007):** Schutz vor induktiven Spannungsspitzen der Relaisspulen
4. **Testpunkte (TP1-TP5):** Auf dem modularen Steuerkreis für Debugging
5. **Sensor-Pinheader:** Alle Platinen brechen GPIOs, GND und VCC auf Stiftleisten für externe Sensoren aus

## Verzeichnisstruktur

```
hardware/
├── 00_hardwareueberblick.md              ← diese Datei
│
├── shared/                               ← Gemeinsame Designs
│   ├── esp32-c3-supermini.md             ← ESP32-C3 Plattform-Referenz
│   ├── modularer_steuerkreis.md          ← Steuerkreis-Doku (BOM, Pins)
│   ├── komponenten.md                    ← Bauteil-Katalog
│   ├── esp32-c3-supermini/               ← KiCAD: THT-Adapter
│   ├── modularer_steuerkreis/            ← 🔑 KiCAD: Steuerkreis (für ALLE Relais)
│   └── schematics/                       ← SVG-Schaltpläne
│
├── master/                               ← Master-Bridge
│   └── README.md
│
├── net_erl/                              ← Basetype: 1-Relais
│   ├── README.md                         ← Übersicht + Pinbelegung
│   ├── leistungskreis_1relais.md         ← Leistungskreis-Doku
│   ├── leistungskreis/                   ← KiCAD: Leistungskreis
│   ├── simulation/                       ← LTSpice
│   ├── schematics/                       ← SVG-Schaltpläne
│   └── devices/                          ← Konkrete Geräte
│       ├── NET-ERL-001_hall_module/
│       └── NET-ERL-002_hall_module_led_ring/
│
├── net_zrl/                              ← Basetype: 2-Relais/Rolladen
│   ├── README.md
│   ├── leistungskreis_2relais.md
│   ├── leistungskreis/                   ← KiCAD: Leistungskreis (2-Relais)
│   ├── schematics/
│   └── devices/
│       └── NET-ZRL-002_shutter_module/
│
├── net_sen/                              ← Basetype: Netz-Sensor
│   ├── README.md
│   ├── kicad/                            ← KiCAD: Sensor_Netzbetrieb
│   ├── schematics/
│   └── devices/
│       └── NET-SEN-002_weather_station/
│
└── bat_sen/                              ← Basetype: Batterie-Sensor
    ├── README.md
    ├── kicad/                            ← KiCAD: Sensor_Batteriebetrieb
    ├── schematics/
    └── devices/
        ├── bat_sen_01_window_contact/
        └── bat_sen_02_rain_sensor/
```

> **Legende:** `← KiCAD:` = originale KiCAD-Projektdateien (`.kicad_pro`, `.kicad_sch`, `.kicad_pcb`, BOM, STEP)

## KiCAD-Quellen (Direktlinks)

| Basetype | Steuerkreis | Leistungskreis/Board |
|---|---|---|
| **net_erl** | [shared/modularer_steuerkreis/](shared/modularer_steuerkreis/) | [net_erl/leistungskreis/](net_erl/leistungskreis/) |
| **net_zrl** | [shared/modularer_steuerkreis/](shared/modularer_steuerkreis/) ← derselbe | [net_zrl/leistungskreis/](net_zrl/leistungskreis/) |
| **net_sen** | — (einteilig) | [net_sen/kicad/](net_sen/kicad/) |
| **bat_sen** | — (einteilig) | [bat_sen/kicad/](bat_sen/kicad/) |
| **master** | — (kein eigenes PCB) | — |

## Verwendete Komponenten (Übersicht)

| Komponente | Typ | Einsatz |
|---|-----|---|
| ESP32-C3 SuperMini Plus V2.0 | Mikrocontroller | Alle Geräte |
| ESP32-C3_SUPERMINI_TH | THT-Adapter | Alle Geräte |
| HLK-5M05 | ACDC-Wandler 230V→5V | NET-ERL, NET-ZRL |
| HLK-PM03 | ACDC-Wandler 230V→3.3V | NET-SEN |
| Hongfa HF46F/5-HS1 | Relais 5V/10A | NET-ERL (1×), NET-ZRL (2×) |
| PC817 | Optokoppler | NET-ERL (1×), NET-ZRL (2×) |
| FQP27P06 | P-Kanal MOSFET TO-220 | NET-ERL |
| IRLZ34N | N-Kanal MOSFET TO-220 | NET-ZRL |
| 1N4007 | Freilaufdiode | Alle Relais-Platinen |
| BME280 | Temp/Feuchte/Druck (I²C 0x76) | NET-ERL-001, NET-SEN-002 |
| BME680 | Temp/Feuchte/Druck/Gas (I²C 0x76) | NET-ERL-002 |
| VEML7700 | Lux-Sensor (I²C 0x10) | NET-ERL-001/002, NET-SEN-002 |
| ENS160 | MOX-Gas-Sensor (I²C 0x52) | NET-ERL-002 |
| LD2410 | Radar-Präsenz (UART) | NET-ERL-002 |
| NeoPixel Ring (12 LED) | WS2812 | NET-ERL-002 |
| BZX55C3V3 | Zener-Diode 3.3V | BAT-SEN |
| IRF9530 | P-Kanal MOSFET SOT-23 | BAT-SEN |

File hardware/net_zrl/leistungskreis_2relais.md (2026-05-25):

# Leistungskreis — 2-Relais (NET-ZRL)

> 230V-Seite für 2-Relais-Knoten | KiCAD: `Leistungskreis_korrektur`

## Übersicht

Der Leistungskreis ist die 230V-führende Platine des NET-ZRL-Systems. Sie enthält das Netzteil, zwei Relais in Sicherheitsschaltung und die Ansteuerungselektronik.

## KiCAD-Projekt

- **Projekt:** `leistungskreis.kicad_pro`
- **Schematic:** `leistungskreis.kicad_sch`
- **PCB:** `leistungskreis.kicad_pcb`
- **Lagen:** 2 (F.Cu + B.Cu), 1.6 mm

## Stückliste (BOM)

| Designator | Bauteil | Footprint | Wert |
|---|---|---|---|
| PS1 | Hi-Link HLK-5M05 | HLK-5Mxx | 230V AC → 5V DC |
| F1 | Feinsicherung | 5×20mm | — |
| K1, K2 | Hongfa HF46F/5-HS1 | RELAY_HF46F | 2× Relais, 5V/10A |
| Q1, Q2 | IRLZ34N | TO-220 Vertikal | N-Kanal MOSFET |
| U1, U2 | PC817 | SOP-4 (SMD) | 2× Optokoppler |
| D1, D2 | 1N4007 | SOD-123 (SMD) | 2× Freilaufdioden |
| C1 | 100µF | Elko 6.3×5.8mm | Glättung |
| C2 | 100nF | 0805 | Entkopplung |
| R1, R3 | 330Ω | 0805 | Gate-Widerstände |
| R2, R4 | 10K | 0805 | Gate-Pulldowns |
| J3 | JST PH 5-pol | B5B-PH-K | Verbindung zum Steuerkreis |
| J8 | Phoenix MKDS 3-pol | TerminalBlock | 230V-Eingang (L, N, PE) |
| J1 | Phoenix MKDS 2-pol | TerminalBlock | Motor-Ausgang |
| J5 | Phoenix MKDS 2-pol | TerminalBlock | PE-Anschluss |

## Anschlüsse

| Klemme | Typ | Belegung |
|---|-----|---|
| J8 | Phoenix MKDS 1.5/3 | L, N (230V AC Eingang) |
| J5 | Phoenix MKDS 1.5/2 | PE (Schutzerde) |
| J1 | Phoenix MKDS 1.5/2 | Motor-Ausgang (geschaltet) |
| J3 | JST PH 5-pol | 5V, GND, GPIO10, GPIO5, 3V3 (zum Steuerkreis) |

## Schaltungsdesign

### Signalfluss

```
ESP GPIO10 ──► PC817 (U1) ──► IRLZ34N (Q1) ──► HF46F (K1) ──► Motor Hoch
                    │              │                  │
              galvanische       N-Kanal           1N4007 (D1)
              Trennung          MOSFET         Freilaufdiode

ESP GPIO5  ──► PC817 (U2) ──► IRLZ34N (Q2) ──► HF46F (K2) ──► Motor Runter
                    │              │                  │
              galvanische       N-Kanal           1N4007 (D2)
              Trennung          MOSFET         Freilaufdiode
```

### Funktionsweise

1. **GPIO10 = HIGH:** U1 leitet → Q1-Gate auf 5V → Q1 schaltet durch → K1-Spule bestromt → Motor fährt HOCH
2. **GPIO5 = HIGH:** U2 leitet → Q2-Gate auf 5V → Q2 schaltet durch → K2-Spule bestromt → Motor fährt RUNTER
3. **Beide GPIOs = LOW:** Beide MOSFETs sperren → Motor steht
4. **Sicherheit:** Relaiskontakte in Serie — unmöglich, dass beide gleichzeitig schließen

### Unterschiede zum 1-Relais-Leistungskreis

| Eigenschaft | NET-ERL (1-Relais) | NET-ZRL (2-Relais) |
|---|---|---|
| Relais-Anzahl | 1× HF46F | 2× HF46F |
| MOSFET-Typ | FQP27P06 (P-Kanal) | IRLZ34N (N-Kanal) |
| MOSFET-Anzahl | 1× | 2× |
| Optokoppler | 1× PC817 (DIP-4) | 2× PC817 (SOP-4 SMD) |
| Freilaufdioden | 1× 1N4007 (DO-41) | 2× 1N4007 (SOD-123) |
| Gate-Widerstand | 330Ω + 100K Pulldown | 2× 330Ω + 2× 10K Pulldown |
| Relais-Verdrahtung | Einfach (Schließer) | Serie (Sicherheit) |
| Ausgang | 1× Schaltkontakt | 1× Motor (Hoch/Runter) |

## Abmessungen

- Platinengröße: ca. 80 × 55 mm (2-Lagen, 1.6 mm FR4)
- Montage: Verschraubt im Gehäuse

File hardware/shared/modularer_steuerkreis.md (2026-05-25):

# Modularer Steuerkreis (`mod_Steuerkreis_ESP32`)

> Gemeinsame Steuerplatine für **alle** Relais-Knoten (`net_erl` und `net_zrl`)

## KiCAD-Quellen

Die vollständigen KiCAD-Projektdateien liegen unter:

👉 **[shared/modularer_steuerkreis/](modularer_steuerkreis/)** — `.kicad_pro`, `.kicad_sch`, `.kicad_pcb`, BOM, STEP, Fertigungsdaten

## Übersicht

Der modulare Steuerkreis ist die **identische** Trägerplatine für den ESP32-C3 in allen Relais-basierten Geräten. Er wird über ein 5-poliges JST-PH-Kabel mit dem jeweiligen Leistungskreis verbunden.

## Stückliste (BOM)

| Designator | Bauteil | Footprint | Anzahl | Wert |
|---|---|---|---|---|
| J1 | 5-Pin Verbindung zum Leistungskreis | SolderWire 0.25mm² | 1 | Wire_5 |
| J3 | GPIO-Breakout 1 | PinHeader 1×05 | 1 | Co_GPIOx1 |
| J6 | Versorgungs-Breakout | PinHeader 1×06 | 1 | Conn_Vx1 |
| J7 | GPIO-Breakout 3 | PinHeader 1×03 | 1 | Co_GPIOx3 |
| JP1, JP2 | I²C-Pullup Lötbrücken | SolderJumper-2 | 2 | Bridge_I2C |
| MH, MH_2 | Befestigungslöcher | MountingHole M3 | 2 | — |
| R3, R4 | I²C-Pullup-Widerstände | 0805 | 2 | 4K7 |
| TP1–TP5 | Testpunkte | TestPoint 1.0mm | 5 | — |
| U3 | ESP32-C3 Modul | MODULE_ESP32-C3_SUPERMINI_TH | 1 | ESP32-C3 |

## Pinbelegung (Steuerkreis → Leistungskreis)

Das 5-polige JST-PH-Kabel (J1) führt:

| Pin | Signal | Ziel im Leistungskreis |
|-----|---|---|
| 1 | 5V | Versorgung vom HLK-5M05 |
| 2 | GND | Masse |
| 3 | GPIO10 (Trigger_PIN1) | Relais-1 Optokoppler |
| 4 | GPIO5 (Trigger_PIN2) | Relais-2 Optokoppler (nur net_zrl) |
| 5 | 3V3 | Optionale 3.3V-Referenz |

## Pinbelegung (GPIO-Breakouts)

| Pin | J3 (Co_GPIOx1) | J7 (Co_GPIOx3) | J6 (Conn_Vx1) |
|-----|---|---|---|
| 1 | GPIO0 (I²C SDA) | GPIO6 | 5V |
| 2 | GPIO1 (I²C SCL) | GPIO7 | 3V3 |
| 3 | GPIO2 | GPIO8 | GND |
| 4 | GPIO3 | — | GPIO4 |
| 5 | GPIO4 | — | GPIO9 |
| 6 | — | — | GPIO10 |

## SVG-Schaltplan

👉 **[schematics/steuerkreis.svg](schematics/steuerkreis.svg)**

## Kompatibilität

| Eigenschaft | net_erl | net_zrl |
|---|---|---|
| Steuerkreis-Platine | ✅ Identisch | ✅ Identisch |
| KiCAD-Quellen | [shared/modularer_steuerkreis/](modularer_steuerkreis/) | ← dieselben |
| Versorgung (5V vom Leistungskreis) | ✅ HLK-5M05 | ✅ HLK-5M05 |
| Trigger_PIN1 (GPIO10) | ✅ Relais 1 | ✅ Relais 1 (Hoch) |
| Trigger_PIN2 (GPIO5) | NC | ✅ Relais 2 (Runter) |

## Designmerkmale

- **Galvanische Trennung:** Der Steuerkreis hat KEINE direkte Verbindung zum 230V-Netz. Die Isolation erfolgt über die Optokoppler (PC817) im Leistungskreis.
- **Testpunkte:** TP1–TP5 ermöglichen Debugging ohne die Platine zu modifizieren
- **M3-Montage:** Zwei Befestigungslöcher für Gehäuseeinbau

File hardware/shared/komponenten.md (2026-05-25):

# Gemeinsame Komponenten-Referenz

> Datenblätter und technische Details der projektweit verwendeten Bauteile

## Zugehörige KiCAD-Quellen

| Komponente | KiCAD-Dateien |
|---|---|
| ESP32-C3 THT-Adapter | [esp32-c3-supermini/](esp32-c3-supermini/) |
| Modularer Steuerkreis | [modularer_steuerkreis/](modularer_steuerkreis/) |
| 1-Relais Leistungskreis | [../net_erl/leistungskreis/](../net_erl/leistungskreis/) |
| 2-Relais Leistungskreis | [../net_zrl/leistungskreis/](../net_zrl/leistungskreis/) |
| Sensor Netzbetrieb | [../net_sen/kicad/](../net_sen/kicad/) |
| Sensor Batteriebetrieb | [../bat_sen/kicad/](../bat_sen/kicad/) |

---

## Mikrocontroller & Adapter

### ESP32-C3 SuperMini Plus V2.0
- **Hersteller:** TENSTAR (Espressif ESP32-C3)
- **Datenblatt:** `esp32-c3_datasheet_en.pdf`, `esp32-c3_technical_reference_manual_en.pdf`
- Siehe [esp32-c3-supermini.md](esp32-c3-supermini.md) für Details

## Netzteile (ACDC-Wandler)

### HLK-5M05
- **Hersteller:** Hi-Link
- **Typ:** AC/DC-Wandler, 230V AC → 5V DC
- **Leistung:** 5W
- **Einsatz:** NET-ERL, NET-ZRL (Leistungskreis)
- **Datenblatt:** `1811141611_Hi-Link-HLK-5M05_C209904.pdf`

### HLK-PM03
- **Hersteller:** Hi-Link
- **Typ:** AC/DC-Wandler, 230V AC → 3.3V DC
- **Leistung:** 3W
- **Einsatz:** NET-SEN (Sensor_Netzbetrieb)
- **Datenblatt:** `2204251615_Hi-Link-HLK-PM03_C3029395.pdf`

## Relais

### Hongfa HF46F/5-HS1
- **Hersteller:** Hongfa
- **Typ:** Subminiatur-Leistungsrelais
- **Spulenspannung:** 5V DC
- **Kontaktbelastbarkeit:** 10A / 250V AC
- **Kontaktart:** 1× Schließer (1 Form A)
- **Abmessungen:** 20.5 × 10.2 × 15.3 mm
- **Einsatz:** NET-ERL (1×), NET-ZRL (2×)
- **Datenblatt:** `1811021711_Hongfa-HF46F-005-HS1T_C303944.pdf`

## Optokoppler

### PC817
- **Hersteller:** Sharp / diverse
- **Typ:** 1-Kanal Optokoppler, DIP-4 / SOP-4
- **Isolationsspannung:** 5000V RMS
- **Einsatz:** Galvanische Trennung ESP-GPIO → Relais-MOSFET
- **NET-ERL:** 1× (DIP-4)
- **NET-ZRL:** 2× (SOP-4 SMD)

## MOSFETs

### FQP27P06 (P-Kanal)
- **Typ:** P-Channel MOSFET, TO-220
- **Vds:** -60V, **Id:** -27A
- **Rds(on):** 70 mΩ
- **Einsatz:** NET-ERL Leistungskreis (Relais-Treiber)

### IRLZ34N (N-Kanal)
- **Typ:** N-Channel MOSFET, TO-220
- **Vds:** 55V, **Id:** 30A
- **Rds(on):** 35 mΩ
- **Einsatz:** NET-ZRL Leistungskreis (Relais-Treiber)

### IRF9530 (P-Kanal)
- **Typ:** P-Channel MOSFET, SOT-23 (SMD)
- **Einsatz:** BAT-SEN (Power-Gating für Deep-Sleep)

## Dioden

### 1N4007
- **Typ:** Standard-Gleichrichterdiode, 1000V/1A
- **Einsatz:** Freilaufdiode über Relaisspulen (Schutz vor induktiven Spannungsspitzen)
- **Gehäuse:** NET-ERL: DO-41 (bedrahtet), NET-ZRL: SOD-123 (SMD)

### BZX55C3V3
- **Typ:** Zener-Diode 3.3V, DO-35
- **Einsatz:** BAT-SEN (Überspannungsschutz)

## Sensoren

### BME280
- **Hersteller:** Bosch Sensortec
- **Typ:** Temperatur/Feuchte/Druck, I²C
- **Adresse:** 0x76 (SDO=GND) / 0x77 (SDO=VCC)
- **Einsatz:** NET-ERL-001, NET-SEN-002

### BME680
- **Hersteller:** Bosch Sensortec
- **Typ:** Temperatur/Feuchte/Druck/Gas (VOC), I²C
- **Adresse:** 0x76 (SDO=GND) / 0x77 (SDO=VCC)
- **Einsatz:** NET-ERL-002
- **Datenblatt:** `bst-bme680-ds001.pdf`

### VEML7700
- **Hersteller:** Vishay
- **Typ:** Lux-Sensor (0–120k Lux), I²C
- **Adresse:** 0x10
- **Einsatz:** NET-ERL-001/002, NET-SEN-002
- **Datenblatt:** `veml7700.pdf`

### ENS160
- **Hersteller:** ScioSense
- **Typ:** MOX-Gassensor (eCO₂, TVOC, AQI), I²C
- **Adresse:** 0x52 (SDO=GND) / 0x53 (SDO=VCC)
- **Einsatz:** NET-ERL-002
- **Datenblatt:** `ENS160-Datasheet.pdf`, `adafruit-ens160-mox-gas-sensor.pdf`

### AHT21
- **Hersteller:** ASAIR
- **Typ:** Temperatur/Feuchte, I²C
- **Adresse:** 0x38
- **Einsatz:** Optional auf allen I²C-fähigen Platinen
- **Datenblatt:** `Data Sheet AHT21.pdf`

### LD2410
- **Hersteller:** Hi-Link
- **Typ:** 24GHz Millimeterwellen-Radar (Präsenz/Bewegung)
- **Schnittstelle:** UART (GPIO6=RX, GPIO7=TX)
- **Einsatz:** NET-ERL-002
- **Reichweite:** 0.75–6m, konfigurierbar

### HC-SR501
- **Typ:** PIR-Bewegungssensor
- **Schnittstelle:** Digital (GPIO3)
- **Einsatz:** NET-ERL-001
- **Datenblatt:** `HC SR501 PIR Sensor Datasheet.pdf`

## Passive Bauteile (projektweit)

| Bauteil | Wert | Gehäuse | Einsatz |
|---|---|---|---|
| R3, R4 | 4K7 | 0805 | I²C-Pullups (alle Platinen) |
| R1 | 330Ω | 0805 | MOSFET-Gate-Widerstand (NET-ZRL) |
| R2, R4 | 10K | 0805 | Gate-Pulldown (NET-ZRL) |
| R1 (BAT) | 10K | 0603 | Spannungsteiler (BAT-SEN) |
| R2, R5 (BAT) | 100K | 0603 | Spannungsteiler (BAT-SEN) |
| C1 | 100µF | Elko 6.3×5.8mm | Glättung (alle Netz-Platinen) |
| C2 | 100nF | 0805 | Entkopplung (alle Netz-Platinen) |
| C1 (BAT) | 100µF | 0603 | Glättung (BAT-SEN) |
| F1 | Feinsicherung | 5×20mm | 230V-Eingang |

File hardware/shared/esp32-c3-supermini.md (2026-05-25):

# ESP32-C3 SuperMini Plus V2.0 — Plattform-Referenz

> Alle Geräte dieses Projekts verwenden das TENSTAR ESP32-C3 SuperMini Plus V2.0

## Technische Daten

| Eigenschaft | Wert |
|---|---|
| Mikrocontroller | Espressif ESP32-C3 (RISC-V, 32-Bit) |
| CPU-Takt | bis 160 MHz |
| Flash | 4 MB |
| SRAM | 400 KB |
| WLAN | 802.11 b/g/n (2.4 GHz) |
| Bluetooth | BLE 5.0 |
| USB | Native USB-CDC + JTAG |
| ADC | 12 Bit, bis 6 Kanäle nutzbar |
| PWM | auf nahezu allen GPIOs |
| Betriebsspannung | 5 V (USB/VIN) |
| Logikspannung | 3.3 V |
| Onboard-LDO | ME6211 / XC6206 / AMS1117-Clone |
| Max. Ausgangsstrom (3.3V) | ~500 mA |

## Stromaufnahme

| Modus | Strom |
|---|---|
| WiFi TX Peak | ~300 mA |
| Idle (WiFi connected) | 70–80 mA |
| Light Sleep | ~5 mA |
| Deep Sleep (Chip only) | ~40 µA |
| Deep Sleep (Board gesamt) | ~0.5–0.8 mA |

## Onboard-Peripherie

| Komponente | Pin/Detail |
|---|---|
| Power-LED | Rot (fest verdrahtet) |
| User-LED | Blau (GPIO8) |
| RGB-LED | WS2812 (GPIO8) |
| Reset-Taster | EN |
| Boot-Taster | GPIO9 |
| Antenne | PCB-Antenne + U.FL-Anschluss |

> **Hinweis:** Blaue LED und RGB-LED teilen sich GPIO8. Beide können nicht gleichzeitig genutzt werden.

## THT-Adapter (`ESP32-C3_SUPERMINI_TH`)

Für den Einsatz auf den Projekt-Platinen wird das SuperMini-Board auf eine **Through-Hole-Adapterplatine** gesteckt:

- KiCAD-Symbol: `ESP32-C3_SUPERMINI_TH.kicad_sym`
- Footprint: `MODULE_ESP32-C3_SUPERMINI_TH.kicad_mod`
- 3D-Modell: `ESP32-C3_SUPERMINI_TH.step`
- Ermöglicht einfaches Einstecken/Austauschen auf Stiftleisten (2× 10-Pin)

## Verfügbare GPIOs auf dem Adapter

| Pin | Funktion | Analog | Besonderheit |
|-----|---|---|---|
| GPIO0 | I²C SDA / frei | ✓ | ADC1_CH0 |
| GPIO1 | I²C SCL / frei | ✓ | ADC1_CH1 |
| GPIO2 | frei | ✓ | ADC1_CH2 |
| GPIO3 | frei | ✓ | ADC1_CH3 |
| GPIO4 | frei | ✓ | ADC1_CH4 |
| GPIO5 | frei | ✓ | ADC2_CH0 |
| GPIO6 | frei | ✗ | — |
| GPIO7 | frei | ✗ | — |
| GPIO8 | frei (LED) | ✗ | Onboard WS2812 |
| GPIO9 | BOOT-Taster | ✗ | Nicht als I/O nutzbar |
| GPIO10 | frei | ✗ | — |
| GPIO20 | RX / frei | ✗ | UART |
| GPIO21 | TX / frei | ✗ | UART |

> **Strapping-Pins:** GPIO2, GPIO8, GPIO9 haben Boot-Verhalten. GPIO9 ist im Normalbetrieb nicht nutzbar.

## Schnittstellen

- **UART:** 2× (RX/TX auf GPIO20/21)
- **I²C:** 1× (SDA/SCL auf GPIO0/1)
- **SPI:** Verfügbar auf GPIO4-7
- **ADC:** 12-Bit, bis 6 Kanäle (GPIO0-5)
- **PWM:** Auf nahezu allen GPIOs
- **USB-CDC:** Native USB-Serial für Programmierung & Debug
- **USB-JTAG:** On-Chip-Debugger

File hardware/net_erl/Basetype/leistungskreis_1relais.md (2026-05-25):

# Leistungskreis — 1-Relais (NET-ERL)

> 230V-Seite für 1-Relais-Knoten | KiCAD: `Leistungskreis_1Relai_korrektur`

## Übersicht

Der Leistungskreis ist die **230V-führende** Platine des NET-ERL-Systems. Sie enthält das Netzteil, das Relais und die Ansteuerungselektronik mit galvanischer Trennung.

## KiCAD-Projekt

- **Projekt:** `leistungskreis.kicad_pro`
- **Schematic:** `leistungskreis.kicad_sch`
- **PCB:** `leistungskreis.kicad_pcb`
- **Lagen:** 2 (F.Cu + B.Cu), 1.6 mm
- **3D-Export:** `leistungskreis.step`

## Stückliste (BOM)

| Designator | Bauteil | Footprint | Wert |
|---|---|---|---|
| PS1 | Hi-Link HLK-5M05 | HLK-5Mxx | 230V AC → 5V DC |
| F1 | Feinsicherung | 5×20mm | — |
| K2 | Hongfa HF46F/5-HS1 | RELAY_HF46F | 1× Relais, 5V/10A |
| Q1 | FQP27P06 | TO-220 Vertikal | P-Kanal MOSFET |
| U2 | PC817 | DIP-4 | Optokoppler |
| D1 | 1N4007 | DO-41 | Freilaufdiode |
| C1 | 100µF | Elko 6.3×5.8mm | Glättung |
| C2 | 100nF | 0805 | Entkopplung |
| R1 | 330Ω | 0805 | Gate-Widerstand |
| R2 | 100K | 0805 | Gate-Pulldown |
| J1 | JST PH 5-pol | B5B-PH-K | Verbindung zum Steuerkreis |
| J5 | Phoenix MKDS 3-pol | TerminalBlock | — |
| J8 | Phoenix MKDS 3-pol | TerminalBlock | 230V-Eingang |

## Anschlüsse

| Klemme | Typ | Belegung |
|---|-----|---|
| J8 | Phoenix MKDS 1.5/3 | L, N, PE (230V AC Eingang) |
| J5 | Phoenix MKDS 1.5/3 | Schaltkontakt (Relais-Ausgang) |
| J1 | JST PH 5-pol | 5V, GND, GPIO10, GPIO5, 3V3 (zum Steuerkreis) |

## Schaltungsdesign

### Signalfluss

```
ESP GPIO10 ──► PC817 Optokoppler ──► FQP27P06 Gate ──► HF46F Spule ──► Relaiskontakt
                    │                      │                    │
              galvanische              P-Kanal              1N4007
              Trennung                 MOSFET            Freilaufdiode
```

### Funktionsweise

1. **GPIO10 = HIGH:** Optokoppler PC817 leitet → Gate des P-MOSFET wird auf GND gezogen → MOSFET schaltet durch → Relais-Spule bestromt → Kontakt schließt
2. **GPIO10 = LOW:** Optokoppler sperrt → Gate wird über R2 (100K) auf 5V gezogen → MOSFET sperrt → Relais fällt ab
3. **Freilaufdiode D1 (1N4007):** Schützt den MOSFET vor der induktiven Spannungsspitze beim Abschalten der Relaisspule

### Besonderheiten

- **P-Kanal MOSFET (FQP27P06):** High-Side-Schaltung — das Relais liegt zwischen MOSFET-Drain und GND
- **Optokoppler (PC817):** 5000V RMS Isolation zwischen ESP-Seite (3.3V Logik) und 230V-Seite
- **Feinsicherung F1:** Schutz vor Überlast auf der 230V-Seite
- **HLK-5M05:** Liefert 5V/1A — versorgt sowohl die Relaisspule (~100mA) als auch den ESP32-C3 (~80-300mA)

## Abmessungen

- Platinengröße: ca. 70 × 50 mm (2-Lagen, 1.6 mm FR4)
- Montage: Verschraubt im Gehäuse

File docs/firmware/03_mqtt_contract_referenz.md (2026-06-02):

# MQTT-Contract-Referenz

> **Hinweis:** Dieses Dokument beschreibt den MQTT-Vertrag der **Firmware-Linie** (ESP-NOW → Master → MQTT).
> Die hier verwendeten Geräte-IDs (z.B. `NET-ERL-001`, `NET-ZRL-001`) sind Firmware-IDs.
> Für die ESPHome-Linie (MQTT direkt, IDs wie `NET-ERL-010`, `NET-ERL-020`) siehe [ESPHome-Dokumentation](../esphome/README.md).

**Stand:** Firmware v1 · **Basis:** ESPHome Packages (`smarthome_contract_base.yaml`, `smarthome_command_ack.yaml`, `smarthome_cover_contract.yaml`)

---

## Inhaltsverzeichnis

1. [Überblick](#1-überblick)
2. [Topic-Struktur](#2-topic-struktur)
3. [Base-Contract – Meta & Verfügbarkeit](#3-base-contract--meta--verfügbarkeit)
4. [ACK-Contract – Befehlsbestätigung](#4-ack-contract--befehlsbestätigung)
5. [Cover-Contract – Zustand & Steuerung](#5-cover-contract--zustand--steuerung)
6. [Globale ESPHome-Internals](#6-globale-esphome-internals)
7. [Nachrichtenfluss-Diagramme](#7-nachrichtenfluss-diagramme)
8. [Events & Trigger](#8-events--trigger)

---

## 1. Überblick

Zwei alternative Implementierungen: **ESPHome** (MQTT direkt) und **Firmware** (ESP-NOW → Master → MQTT). Die MQTT-Contracts sind ESPHome-Package-Vorlagen (`.yaml`), die auf dem **Master** (ESP32 Gateway) laufen und folgende Funktionen bereitstellen:

| Contract | Datei | Zweck |
|---|---|---|
| **Base** | `smarthome_contract_base.yaml` | Meta-Info, Verfügbarkeit, Setup-Portal, OTA |
| **ACK** | `smarthome_command_ack.yaml` | Bestätigung von ESP-NOW-Befehlen als MQTT-JSON |
| **Cover** | `smarthome_cover_contract.yaml` | Cover-Zustand (STATE) und Steuerbefehle (CMD) |

### 1.1 Datenfluss

```
┌─────────┐  ESP-NOW   ┌──────────┐  MQTT        ┌─────────────┐
│ Knoten  │◄──────────►│  Master  │◄────────────►│  Server     │
│ (Node)  │  binär     │ (ESP32)  │  JSON         │ (HomeAssist)│
└─────────┘            └──────────┘              └─────────────┘
```

---

## 2. Topic-Struktur

Alle Topics folgen dem Schema:

```
smarthome/device/{device_id}/{topic_suffix}
```

| Platzhalter | Beschreibung |
|---|---|
| `{device_id}` | Geräte-ID (z.B. `NET-ZRL-001`) – wird durch ESPHome-Template ersetzt |

### 2.1 Topic-Übersicht

| Suffix | QoS | Retain | Richtung | Contract |
|---|---|---|---|---|
| `meta` | 0 | ✅ Ja | Knoten → Server | Base |
| `availability` | 0 | ✅ Ja | Knoten → Server | Base |
| `ack` | 0 | ❌ Nein | Knoten → Server | ACK |
| `state` | 0 | ✅ Ja | Knoten → Server | Cover |
| `command` | 0 | ❌ Nein | Server → Knoten | Cover |
| `hello` | 0 | ❌ Nein | Knoten → Server | Base |
| `heartbeat` | 0 | ❌ Nein | Knoten → Server | Base |
| `event` | 0 | ❌ Nein | Knoten → Server | Cover |

---

## 3. Base-Contract – Meta & Verfügbarkeit

### 3.1 `smarthome/device/{device_id}/meta` (Retain)

Wird beim Booten und bei jeder HELLO-Nachricht aktualisiert. Enthält die vollständige Gerätebeschreibung.

```json
{
  "device_id": "NET-ZRL-001",
  "device_name": "Rollladen Wohnzimmer",
  "device_class": "net_erl",
  "power_type": 0,
  "fw_version": 1.0,
  "caps": 10243,
  "mac_address": "AA:BB:CC:DD:EE:FF",
  "meta_schema_version": 1,
  "control_mode": 5,
  "config_profile": 3,
  "reporting_mode": 1,
  "sensor_mask": [0, 0, 0, 0, 0, 0, 0, 0, 0, 0, 0],
  "input_mask": [0, 0, 0, 0, 0, 0]
}
```

| Feld | Typ | Beschreibung |
|---|---|---|
| `device_id` | string | Eindeutige Geräte-ID (z.B. `NET-ZRL-001`) |
| `device_name` | string (32) | Anzeigename aus der Gerätekonfiguration |
| `device_class` | string | Device-Class (§1 DeviceTypes). Werte: `"net_erl"`, `"net_zrl"`, `"net_sen"`, `"bat_sen"`, `"master"` |
| `power_type` | int | `0` = MAINS, `1` = BATTERY |
| `fw_version` | float | Firmware-Version (major.minor) |
| `caps` | int | 16-Bit-Capability-Bitmask (§6 DeviceTypes) |
| `mac_address` | string | MAC-Adresse als `XX:XX:XX:XX:XX:XX` |
| `meta_schema_version` | int | Meta-Schema-Version (aktuell 1) |
| `control_mode` | int | Control-Mode (§3 DeviceTypes) |
| `config_profile` | int | Config-Profil (§4 DeviceTypes) |
| `reporting_mode` | int | Reporting-Mode (§5 DeviceTypes) |
| `sensor_mask` | array[11] | 11-Byte-Sensor-Bitmaske als Integer-Array |
| `input_mask` | array[6] | 6-Byte-Input-Bitmaske als Integer-Array |

### 3.2 `smarthome/device/{device_id}/availability` (Retain)

Wird bei jeder HELLO/HEARTBEAT-Nachricht aktualisiert. Zeigt an, ob das Gerät erreichbar ist.

```json
{
  "device_id": "NET-ZRL-001",
  "availability": "online",
  "online": true,
  "power_type": 0
}
```

| Feld | Typ | Beschreibung |
|---|---|---|
| `device_id` | string | Geräte-ID |
| `availability` | string | `"online"` oder `"offline"` |
| `online` | bool | `true` = online, `false` = offline |
| `power_type` | int | `0` = MAINS, `1` = BATTERY |

**Offline-Erkennung:**
- **MAINS-Geräte:** Wenn kein STATE/HELLO innerhalb des `report_interval_s * 3` eingeht → `"offline"`
- **BATTERY-Geräte:** Wenn kein HEARTBEAT innerhalb des `wake_interval_s * 4` eingeht → `"offline"`

---

## 4. ACK-Contract – Befehlsbestätigung

### 4.1 `smarthome/device/{device_id}/ack` (nicht Retain)

Wird nach jedem ESP-NOW-ACK (oder ACK-Timeout) gesendet. Erlaubt dem Server die Nachverfolgung von Befehlen.

```json
{
  "device_id": "NET-ZRL-001",
  "request_id": 42,
  "channel": "command",
  "status": "OK",
  "status_code": 0,
  "ack_msg_type": 5,
  "ack_seq": 128,
  "source": "espnow"
}
```

| Feld | Typ | Beschreibung |
|---|---|---|
| `device_id` | string | Geräte-ID |
| `request_id` | int | Vom Server mitgesendete Request-ID (für Zuordnung) |
| `channel` | string | Kanal (immer `"command"`) |
| `status` | string | Textuelle Status-Beschreibung (`"OK"`, `"ERROR"`, `"TIMEOUT"`) |
| `status_code` | int | Numerischer Status-Code (0 = OK, siehe Fehlercodes unten) |
| `ack_msg_type` | int | Message-Typ des quittierten Pakets (`5` = CMD) |
| `ack_seq` | int | Sequenznummer (0–255, zyklisch) |
| `source` | string | Quelle (`"espnow"`, `"timeout"`, `"internal"`) |

### 4.2 Status-Codes

| Code | Bedeutung | Beschreibung |
|---|---|---|
| `0` | OK | Befehl erfolgreich verarbeitet |
| `1` | ERROR | Allgemeiner Fehler |
| `2` | REJECTED | Befehl abgelehnt (z.B. unbekannte Device-ID) |
| `3` | REJECTED_FULL | Befehl abgelehnt – ESP-NOW-Warteschlange voll |
| `-1` | TIMEOUT | Kein ACK innerhalb des Timeouts empfangen |
| `-2` | UNSUPPORTED | Befehl wird von diesem Gerät nicht unterstützt |

### 4.3 ack_seq Mechanik

- `ack_seq` wird pro Gerät hochgezählt (0 → 1 → … → 255 → 0)
- Erlaubt Duplikatserkennung auf Empfängerseite
- Wird im ESP-NOW-AckPayload übertragen und hier gespiegelt

---

## 5. Cover-Contract – Zustand & Steuerung

### 5.1 `smarthome/device/{device_id}/state` (Retain)

Wird bei jeder STATE-NAChricht eines NET-ZRL im COVER-Mode gesendet.

```json
{
  "device_id": "NET-ZRL-001",
  "relay_1": false,
  "relay_2": false,
  "cover_mode": true,
  "cover_state": "stopped",
  "cover_position": 75,
  "cover_calibrated": true,
  "fault": 0
}
```

| Feld | Typ | Beschreibung |
|---|---|---|
| `device_id` | string | Geräte-ID |
| `relay_1` | bool | Relais 1 Zustand (true = an) |
| `relay_2` | bool | Relais 2 Zustand (true = an) |
| `cover_mode` | bool | Cover aktiv (true = Cover-Modus) |
| `cover_state` | string | `"opening"`, `"closing"`, `"stopped"` |
| `cover_position` | int \| null | Position 0–100, `null` wenn nicht kalibriert |
| `cover_calibrated` | bool | Kalibrierungsstatus |
| `fault` | int | Fehlercode (0 = kein Fehler) |

**cover_position Wertebereich:**

| Wert | Bedeutung |
|---|---|
| `0` | Vollständig geschlossen / unten |
| `100` | Vollständig geöffnet / oben |
| `null` | Nicht kalibriert (Position unbekannt) |
| `1–99` | Zwischenposition |

### 5.2 `smarthome/device/{device_id}/command` (nicht Retain)

Eingehende Befehle vom Server zur Steuerung des Covers.

#### Allgemeines Format

```json
{
  "request_id": 42,
  "device_id": "NET-ZRL-001",
  "command": "set_position",
  "position": 50
}
```

| Feld | Typ | Beschreibung |
|---|---|---|
| `request_id` | int | Optionale ID für ACK-Zuordnung |
| `device_id` | string | Ziel-Geräte-ID |
| `command` | string | Befehl (siehe Tabelle) |
| `*` | * | Befehls-spezifische Parameter |

#### Unterstützte Befehle

| Befehl | Parameter | Beschreibung |
|---|---|---|
| `get_state` | — | Sofortigen STATE anfordern |
| `set_config` | `{param_id, value}` | Konfigurationsparameter setzen |
| `calibrate` | — | Cover-Kalibrierung starten |
| `clear_calibration` | — | Kalibrierung zurücksetzen |
| `open` | — | Cover vollständig öffnen (Position 100) |
| `close` | — | Cover vollständig schließen (Position 0) |
| `stop` | — | Bewegung sofort stoppen |
| `set_position` | `position: 0–100` oder `value: 0–100` | Auf bestimmte Position fahren |

#### Beispiele

```json
// Cover öffnen
{ "request_id": 1, "device_id": "NET-ZRL-001", "command": "open" }

// Auf Position 50 fahren
{ "request_id": 2, "device_id": "NET-ZRL-001", "command": "set_position", "position": 50 }
{ "request_id": 2, "device_id": "NET-ZRL-001", "command": "set_position", "value": 50 }

// Kalibrierung starten
{ "request_id": 3, "device_id": "NET-ZRL-001", "command": "calibrate" }
```

### 5.3 Fehlercodes (Cover-Contract)

| Code | Bedeutung | Beschreibung |
|---|---|---|
| `-20` | `missing_request_id` | Request-ID fehlt im Befehl |
| `-21` | `invalid_payload` | Payload ungültig oder fehlerhaft |
| `-6` | `calib_in_progress` | Kalibrierung läuft bereits / Gerät bereits kalibriert |
| `-6` | `already_calibrated` | (gleicher Code wie calib_in_progress) |
| `-5` | `not_calibrated` | Cover nicht kalibriert – Position kann nicht angefahren werden |
| `-2` | `unsupported` | Befehl von diesem Gerät nicht unterstützt |

### 5.4 Kalibrierungs-Zustandsmaschine

```
Phase 0: Idle        ──calibrate──►  Phase 1: MovingUp
   ▲                                      │
   │                                      │ (oben angekommen)
   │                                      ▼
   │                              Phase 2: WaitForDown
   │                                      │
   │                                      │ (automatisch)
   │                                      ▼
   │                              Phase 3: MeasuringDown
   │                                      │
   │                                      │ (unten angekommen)
   │                                      ▼
   │                              Phase 4: WaitForSave
   │                                      │
   │                                      │ (save)
   │                                      ▼
   └─── save complete ────►       Phase 5: Complete
```

| Phase | Wert | Beschreibung |
|---|---|---|
| `Idle` | 0 | Ausgangszustand, keine Kalibrierung aktiv |
| `MovingUp` | 1 | Rollladen fährt hoch (oberen Endpunkt suchen) |
| `WaitForDown` | 2 | Oben angekommen, warte auf automatischen Start der Abfahrt |
| `MeasuringDown` | 3 | Rollladen fährt runter (Zeitmessung, unteren Endpunkt suchen) |
| `WaitForSave` | 4 | Unten angekommen, warte auf Speicherung |
| `Complete` | 5 | Kalibrierung abgeschlossen, `cover_calibrated = true` |

**Wichtig:** Zwischenpositionen (`set_position` mit 1–99) sind nur nach erfolgreicher Kalibrierung möglich. Vor der Kalibrierung sind nur `open` (100) und `close` (0) erlaubt.

### 5.5 `smarthome/device/{device_id}/state` – NET-ERL State Payload

Wird bei jeder STATE-Nachricht eines NET-ERL gesendet. Der Payload enthält den vollen Umfang des `ExtendedRelayComfortGasConfigStateReportPayload` (45 Bytes).

```json
{
  "device_id": "NET-ERL-001",
  "relay_1": false,
  "motion": false,
  "temperature": 21.5,
  "humidity": 48.2,
  "lux": 250,
  "auto_flags": 0,
  "fault": 0,
  "report_interval_s": 10,
  "auto_on_lux_threshold": 250
}
```

| Feld | Typ | Beschreibung |
|---|---|---|
| `device_id` | string | Geräte-ID |
| `relay_1` | bool | Relais-Zustand (true = ein) |
| `motion` | bool | Präsenz erkannt (true = ja) |
| `temperature` | float | Temperatur in °C (`temp_01c / 10`) |
| `humidity` | float | Relative Luftfeuchte in % (`hum_01pct / 10`) |
| `lux` | uint16 | Beleuchtungsstärke in Lux |
| `auto_flags` | uint8 | Auto-Light-Bitmaske (siehe Tabelle unten) |
| `fault` | uint8 | Fehlercode (0 = kein Fehler) |
| `report_interval_s` | uint16 | Aktuelles Report-Intervall in Sekunden |
| `auto_on_lux_threshold` | uint16 | Aktuelle Einschaltschwelle in Lux |

### auto_flags Bitmaske

| Bit | Wert | Flag | Beschreibung |
|-----|---|---|---|
| 0 | 0x01 | AUTO_REQUEST_ON | Auto-Light-Einschaltvorgang läuft |
| 1 | 0x02 | AUTO_RELAY_OWNED | Relais wird von Automation gesteuert |
| 2 | 0x04 | BLOCKED_BY_SERVER | Server hat Auto-Light deaktiviert |
| 3 | 0x08 | BLOCKED_BY_LUX | Helligkeit zu hoch für Auto-Light |
| 4 | 0x10 | BLOCKED_BY_MISSING_LUX | Lux-Wert fehlt für Entscheidung |
| 5 | 0x20 | PRESENCE_SOURCE_AVAILABLE | Bewegungssensor vorhanden (PIR/LD2410) |
| 6 | 0x40 | LIGHT_VALUE_AVAILABLE | Luxsensor vorhanden (VEML7700) |
| 7 | 0x80 | LIGHT_GUARD_ENABLED | Auto-Light-Funktion aktiviert |

### 5.6 `smarthome/device/{device_id}/state` – NET-SEN State Payload (Wetterstation)

Wird bei jeder STATE-Nachricht eines NET-SEN gesendet.

```json
{
  "device_id": "NET-SEN-020",
  "temp_01c": 195,
  "hum_01pct": 620,
  "lux": 15000,
  "pressure_pa": 101325,
  "gas_ohm": null,
  "aqi": null,
  "tvoc_ppb": null,
  "eco2_ppm": null,
  "motion": false,
  "rain": false,
  "fault": false
}
```

| Feld | Typ | Beschreibung |
|---|---|---|
| `device_id` | string | Geräte-ID |
| `temp_01c` | int16 | Temperatur in Zehntelgrad (°C × 10) |
| `hum_01pct` | uint16 | Relative Luftfeuchte in Zehntelprozent (% × 10) |
| `lux` | uint16 | Beleuchtungsstärke in Lux |
| `pressure_pa` | uint32 | Luftdruck in Pascal |
| `gas_ohm` | uint32 \| null | Gas-Sensor-Widerstand in Ohm (optional) |
| `aqi` | uint16 \| null | Luftqualitätsindex (optional) |
| `tvoc_ppb` | uint16 \| null | TVOC-Konzentration in ppb (optional) |
| `eco2_ppm` | uint16 \| null | eCO2-Konzentration in ppm (optional) |
| `motion` | bool | Präsenz erkannt |
| `rain` | bool \| null | Regenstatus, aus `rain_detected`-Events retained in den State übernommen |
| `fault` | bool | Fehlerstatus (true = Fehler) |

### 5.7 `smarthome/device/{device_id}/state` – BAT-SEN State Payload (Fensterkontakt)

Wird bei jeder STATE-Nachricht eines BAT-SEN im Fensterkontakt-Modus gesendet.

```json
{
  "device_id": "bat_sen_010",
  "battery_pct": 85,
  "battery_mv": 2900,
  "window_open": 0,
  "rain_raw": null,
  "button_flags": 0,
  "report_interval_s": 43200,
  "fault": false
}
```

| Feld | Typ | Beschreibung |
|---|---|---|
| `device_id` | string | Geräte-ID |
| `battery_pct` | uint8 | Akkustand in Prozent |
| `battery_mv` | uint16 | Akkuspannung in Millivolt |
| `window_open` | uint8 | Fensterstatus (0 = geschlossen, >0 = geöffnet) |
| `rain_raw` | uint16 \| null | Regen-Rohwert (null wenn kein Regensensor) |
| `button_flags` | uint8 | Taster-Bitmaske |
| `report_interval_s` | uint16 | Meldeintervall in Sekunden |
| `fault` | bool | Fehlerstatus (true = Fehler) |

### 5.8 `smarthome/device/{device_id}/state` – BAT-SEN State Payload (Regensensor)

Wird bei jeder STATE-Nachricht eines BAT-SEN im Regensensor-Modus gesendet.

```json
{
  "device_id": "bat_sen_020",
  "battery_pct": 72,
  "battery_mv": 2600,
  "window_open": null,
  "rain_raw": 1845,
  "button_flags": 0,
  "report_interval_s": 900,
  "fault": false
}
```

| Feld | Typ | Beschreibung |
|---|---|---|
| `device_id` | string | Geräte-ID |
| `battery_pct` | uint8 | Akkustand in Prozent |
| `battery_mv` | uint16 | Akkuspannung in Millivolt |
| `window_open` | uint8 \| null | Fensterstatus (null wenn kein Fensterkontakt) |
| `rain_raw` | uint16 | Regen-Rohwert (0 = kein Regen) |
| `button_flags` | uint8 | Taster-Bitmaske |
| `report_interval_s` | uint16 | Meldeintervall in Sekunden |
| `fault` | bool | Fehlerstatus (true = Fehler) |

### 5.9 Sensor-Offset (Temperatur/Feuchte)

Jedes Gerät unterstützt einen konfigurierbaren Offset zur Kompensation
von Einbaufehlern (z.B. Sensor zu nah am Netzteil):

| Gerät | temp_offset_01c | hum_offset_01pct |
|---|:---:|:---:|
| NET-ERL-001 | 0 | 0 |
| NET-ERL-002 | 0 | 0 |
| NET-SEN-002 | 0 | 0 |

Offsets werden in Geräte-Nativeinheiten angegeben (Zehntelgrad, Zehntelprozent).
Negativer Wert = Korrektur nach unten. Positiver = Korrektur nach oben.
Beispiel: BME280 nahe Netzteil misst 30 °C bei 22 °C → temp_offset_01c = -80 (-8,0 °C).

Der Offset wird NACH der Sensor-Mittelung (EMA-Filter) angewendet.

### 5.10 Sensor-Mittelung (EMA-Filter)

Zur Rauschunterdrückung wird ein exponentiell gleitender Mittelwert (EMA)
auf Temperatur- und Feuchtewerte angewendet:

- α = 0,2 (20 % neuer Messwert, 80 % bisheriger Mittelwert)
- Aktiv in: NET-ERL-001 (BME280), NET-SEN-002 (BME280)
- ESPHome-Geräte: nutzen 16× Oversampling + IIR-Filter des BME280

---

## 6. Globale ESPHome-Internals

Folgende globale Variablen und Funktionen werden von den Contracts auf dem Master verwendet:

### 6.1 Globale Variablen

| Variable | Typ | Beschreibung |
|---|---|---|
| `contract_online` | `bool` | Master ist online und bereit |
| `contract_fault` | `bool` | Allgemeiner Fehlerstatus des Masters |
| `contract_last_status_code` | `int` | Letzter Status-Code |
| `contract_last_status_text` | `string` | Letzter Status-Text |
| `contract_last_request_id` | `int` | Letzte verarbeitete Request-ID |
| `stored_master_mac` | `string` | MAC-Adresse des Master-Gateways |
| `setup_portal_active` | `bool` | Setup-Portal ist aktiv (Captive Portal für Erstkonfiguration) |

### 6.2 Interne Funktionen

| Funktion | Beschreibung |
|---|---|
| **Setup-Portal** | Captive-Portal für WLAN-Konfiguration bei Erstinbetriebnahme |
| **OTA** | Over-the-Air-Update-Mechanismus (ESPHome standard) |
| **HELLO-Timeout** | Überwachung der Geräte-Erreichbarkeit, schaltet auf `"offline"` bei Ausbleiben von Nachrichten |

---

## 7. Nachrichtenfluss-Diagramme

### 7.1 Gerät anmelden (Boot)

```
Knoten              Master                MQTT-Server
  │                   │                      │
  │───HELLO──────────►│                      │
  │                   │──meta (retain)──────►│
  │                   │──availability ──────►│
  │◄──HELLO_ACK──────│                      │
  │                   │                      │
  │◄──CFG (optional)─│                      │
  │◄──CMD (optional)─│                      │
  │                   │                      │
```

### 7.2 Periodischer STATE (Cover)

```
Knoten              Master                MQTT-Server
  │                   │                      │
  │───STATE──────────►│                      │
  │                   │──state (retain)─────►│
  │◄──ACK────────────│                      │
  │                   │                      │
```

### 7.3 Befehl vom Server

```
Knoten              Master              MQTT-Server
  │                   │                      │
  │                   │◄──command───────────│
  │                   │                      │
  │◄──CMD────────────│                      │
  │                   │                      │
  │───ACK───────────►│                      │
  │                   │──ack───────────────►│
  │                   │                      │
  │───STATE─────────►│                      │
  │                   │──state (retain)─────►│
  │                   │                      │
```

### 7.4 Ereignisgesteuerter STATE

```
Knoten              Master                MQTT-Server
  │                   │                      │
  │───EVENT─────────►│                      │
  │                   │──state (retain)─────►│
  │◄──ACK────────────│                      │
  │                   │                      │
```

---

## 8. Events & Trigger

Events werden von Geräten über ESP-NOW gesendet (`msg_type = 0x04`) und vom Master in STATE-MQTT-Nachrichten übersetzt. Die Event-Typen dokumentieren, welche Zustandsänderungen ein Gerät melden kann.

### 8.1 Events

| Event | Wert | Beschreibung |
|---|---|---|
| `BUTTON_PRESS` | `0x01` | Taster gedrückt |
| `MOTION_DETECTED` | `0x02` | Bewegung erkannt |
| `WINDOW_OPENED` | `0x03` | Fenster geöffnet |
| `WINDOW_CLOSED` | `0x04` | Fenster geschlossen |
| `RAIN_DETECTED` | `0x05` | Regen erkannt |
| `RELAY_CHANGED` | `0x06` | Relais-Status geändert |
| `LIGHT_AUTO_ON` | `0x07` | Licht automatisch eingeschaltet |
| `LIGHT_AUTO_OFF` | `0x08` | Licht automatisch ausgeschaltet |
| `COVER_UP` | `0x09` | Cover fährt hoch |
| `COVER_DOWN` | `0x0A` | Cover fährt runter |
| `COVER_STOP` | `0x0B` | Cover gestoppt |
| `COVER_CALIB_START` | `0x0C` | Cover-Kalibrierung gestartet |
| `COVER_CALIB_DONE` | `0x0D` | Cover-Kalibrierung abgeschlossen |
| `NODE_BOOT` | `0x0E` | Gerät hochgefahren (nach Reset) |
| `SENSOR_FAULT` | `0x0F` | Sensorfehler aufgetreten |
| `COMM_FAULT` | `0x10` | Kommunikationsfehler |
| `BUTTON_RELEASE` | `0x11` | Taster losgelassen |
| `BUTTON_LONG_PRESS` | `0x12` | Taster lange gedrückt |

### 8.2 Trigger

| Trigger | Wert | Beschreibung |
|---|---|---|
| `MANUAL_BUTTON` | `0x01` | Manuell über Taster |
| `MASTER_CMD` | `0x02` | Vom Master gesendet |
| `AUTO` | `0x03` | Automatik (Regelung) |
| `AUTO_OFF_TIMER` | `0x04` | Automatische Abschaltung (Timer) |
| `CONFIG` | `0x05` | Konfigurationsänderung |

### 8.3 MQTT-Abbildung

Events werden nicht als eigenes MQTT-Topic publiziert, sondern lösen ein STATE-Update aus (§7.4). Das `event_type`- und `trigger`-Feld aus dem ESP-NOW `EventReportPayload` wird dabei in die entsprechende Zustandsänderung übersetzt (z.B. `cover_state`, `motion`, `relay_1`).

---

> **Änderungshistorie**  
> v1 – Initiale MQTT-Contract-Definition, Firmware Release 1.

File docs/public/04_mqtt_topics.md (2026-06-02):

# MQTT Topics & Payloads

## Übersicht

| Topic | Richtung | Retain | Beschreibung |
|---|---|:---:|---|
| `smarthome/master/{master_id}/status` | Master → Broker | ✅ | Master-Status (WLAN, MQTT, Nodes) |
| `smarthome/master/{master_id}/event` | Master → Broker | ❌ | Master-Ereignisse (boot, mqtt_connected, …) |
| `smarthome/device/{device_id}/meta` | Gerät → Broker | ✅ | Metadaten (Caps, Profile, Version) |
| `smarthome/device/{device_id}/availability` | Gerät → Broker | ✅ | Online/Offline-Status |
| `smarthome/device/{device_id}/state` | Gerät → Broker | ✅ | Live-Zustand (Sensoren, Relais, Cover) |
| `smarthome/device/{device_id}/event` | Gerät → Broker | ❌ | Ereignisse (Button, Bewegung, Fenster, …) |
| `smarthome/device/{device_id}/ack` | Master → Broker | ❌ | Kommando-Bestätigung |
| `smarthome/device/{device_id}/command` | Broker → Gerät | — | Kommandos vom Server |

---

## Geräte-IDs – Zwei getrennte Linien

Das Projekt betreibt zwei alternative Firmware-Linien mit **unterschiedlichen Geräte-IDs**:

| Gerätetyp | ESPHome-Linie (MQTT direkt) | Firmware-Linie (ESP-NOW → Master) |
|---|---|---|
| Flurmodul | `NET-ERL-010` | `NET-ERL-001` |
| Flurmodul LED-Ring | `NET-ERL-020` | `NET-ERL-002` |
| Wetterstation | `NET-SEN-020` | `NET-SEN-002` |
| Rollladen | `NET-ZRL-020` | `NET-ZRL-002` |
| Fensterkontakt | `bat_sen_010` | `bat_sen_01` |
| Regensensor | `bat_sen_020` | `bat_sen_02` |

**Wichtig:** MQTT-Topics sind case-sensitiv!
Die beiden Linien unterscheiden sich im **Suffix** (Ziffernfolge), nicht in der Schreibweise:
- ESPHome verwendet durchgehend **dreistellige** Suffixe (`010`, `020`).
- Firmware verwendet **zweistellige** Suffixe bei `bat_sen` (`01`, `02`) und
  **dreistellige** bei NET-Geräten (`001`, `002`).
- `bat_sen`-Geräte sind in **beiden** Linien klein mit Underscore geschrieben.
- NET-Geräte sind in **beiden** Linien groß mit Bindestrich geschrieben.

Alle folgenden Payload-Beispiele verwenden die **ESPHome-IDs**,
da diese Doku den MQTT-Vertrag der ESPHome-Linie beschreibt.

---

## Meta-Payload

```json
{
  "device_id": "NET-ERL-010",
  "device_name": "NET-ERL Hall Module",
  "device_class": "net_erl",
  "power_type": "mains",
  "fw_version": 1,
  "caps": 93,
  "mac_address": "AA:BB:CC:DD:EE:FF",
  "meta_schema_version": 1,
  "control_mode": "relay_light",
  "config_profile": "hall_light",
  "reporting_mode": "hybrid",
  "sensor_mask": "THLMXXXXXX",
  "input_mask": "XXXXX"
}
```

| Feld | Typ | Beschreibung |
|---|-----|---|
| `device_id` | string | Eindeutige Geräte-ID |
| `device_name` | string | Anzeigename |
| `device_class` | string | Geräteklasse: `net_erl`, `net_sen`, `net_zrl`, `bat_sen` |
| `power_type` | string | Stromversorgung: `mains` oder `battery` |
| `fw_version` | int | Firmware-Version (integer) |
| `caps` | int | Fähigkeiten-Bitmaske |
| `mac_address` | string | MAC-Adresse (Format `AA:BB:CC:DD:EE:FF`, kann Leerstring sein) |
| `meta_schema_version` | int | Schema-Version des Meta-Payloads |
| `control_mode` | string | Steuermodus (z.B. `relay_light`, `cover`, `none`) |
| `config_profile` | string | Konfigurationsprofil (z.B. `hall_light`, `cover_basic`) |
| `reporting_mode` | string | Meldeverhalten (z.B. `hybrid`, `sleep_event`) |
| `sensor_mask` | string | 10-stellige Sensormaske |
| `input_mask` | string | 5-stellige Eingabemaske |

### Caps-Bitmaske

| Bit | Konstante | Wert | Bedeutung |
|-----|---|-----:|---|
| 0 | SH_CAP_RELAY | 1 | Relais 1 |
| 1 | SH_CAP_RELAY2 | 2 | Relais 2 |
| 2 | SH_CAP_TEMP | 4 | Temperatursensor |
| 3 | SH_CAP_HUM | 8 | Feuchtesensor |
| 4 | SH_CAP_LUX | 16 | Helligkeitssensor (VEML7700) |
| 5 | SH_CAP_AQI | 32 | Luftqualität (ENS160) |
| 6 | SH_CAP_MOTION | 64 | Bewegungssensor (PIR/LD2410) |
| 7 | SH_CAP_WINDOW | 128 | Fensterkontakt |
| 8 | SH_CAP_RAIN | 256 | Regensensor |
| 9 | SH_CAP_BATTERY | 512 | Batteriebetrieb |
| 10 | SH_CAP_BUTTON | 1024 | Lokaler Taster |
| 11 | SH_CAP_MULTIBUTTON | 2048 | Mehrfachtaster |
| 12 | SH_CAP_LED_RING | 4096 | NeoPixel LED-Ring |
| 13 | SH_CAP_COVER | 8192 | Rollladensteuerung |
| 14 | SH_CAP_GAS | 16384 | Gassensor (BME680) |
| 15 | SH_CAP_PRESSURE | 32768 | Drucksensor (BME280/BME680) |

### Caps pro Gerät

| Gerät | Caps | Bitmaske |
|---|-----:|---|
| `NET-ERL-010` (Flur) | 93 | RELAY(1)+TEMP(4)+HUM(8)+LUX(16)+MOTION(64) |
| `NET-ERL-020` (LED Ring) | 54397 | RELAY(1)+TEMP(4)+HUM(8)+LUX(16)+AQI(32)+MOTION(64)+BUTTON(1024)+LED_RING(4096)+GAS(16384)+PRESSURE(32768) |
| `NET-SEN-020` (Wetter) | 33052 | TEMP(4)+HUM(8)+LUX(16)+RAIN(256)+PRESSURE(32768) |
| `NET-ZRL-020` (Rollladen) | 10243 | RELAY(1)+RELAY2(2)+MULTIBUTTON(2048)+COVER(8192) |
| `bat_sen_010` (Fenster) | 640 | BATTERY(512)+WINDOW(128) |
| `bat_sen_020` (Regen) | 768 | BATTERY(512)+RAIN(256) |

---

## Sensor-Maske

10-stellige Maske (eine Stelle pro Sensorposition). Mögliche Zeichen:
- **T** = Temperatur
- **H** = Feuchte
- **L** = Helligkeit (Lux)
- **P** = Luftdruck
- **G** = Gas
- **A** = Luftqualität (AQI)
- **M** = Bewegung
- **W** = Fenster
- **R** = Regen
- **X** = nicht belegt

---

## State-Payload (nach Geräteklasse)

### NET-ERL (Relais + Sensor)

```json
{
  "device_id": "NET-ERL-010",
  "relay_1": true,
  "temp_01c": 225,
  "hum_01pct": 480,
  "lux": 320,
  "pressure_pa": null,
  "gas_ohm": null,
  "aqi": null,
  "tvoc_ppb": null,
  "eco2_ppm": null,
  "motion": false,
  "fault": false,
  "auto_flags": 0,
  "report_interval_s": 60,
  "auto_on_lux_threshold": null
}
```

**`auto_flags` Bitmaske:**
| Bit | Flag |
|-----|---|
| 0x01 | AUTO_REQUEST_ON - Auto-Light angefordert |
| 0x02 | AUTO_RELAY_OWNED - Relais von Automation gesteuert |
| 0x04 | BLOCKED_BY_SERVER - Server hat Auto-Light deaktiviert |
| 0x08 | BLOCKED_BY_LUX - Zu hell für Auto-Light |
| 0x10 | BLOCKED_BY_MISSING_LUX - Lux-Wert fehlt für Auto-Entscheidung |
| 0x20 | PRESENCE_SOURCE_AVAILABLE - Bewegungssensor vorhanden |
| 0x40 | LIGHT_VALUE_AVAILABLE - Luxsensor vorhanden |
| 0x80 | LIGHT_GUARD_ENABLED - Auto-Light aktiv |

### NET-ZRL (Rollladen)

```json
{
  "device_id": "NET-ZRL-020",
  "relay_1": false,
  "relay_2": false,
  "cover_mode": true,
  "cover_state": "stopped",
  "cover_position": 75,
  "cover_calibrated": true,
  "fault": false
}
```

**`cover_state` Werte:**
- `"open"` - ganz oben (position=100)
- `"closed"` - ganz unten (position=0)
- `"opening"` - fährt hoch
- `"closing"` - fährt runter
- `"stopped"` - steht

### NET-SEN (Sensor)

```json
{
  "device_id": "NET-SEN-020",
  "temp_01c": 195,
  "hum_01pct": 620,
  "lux": 15000,
  "pressure_pa": null,
  "gas_ohm": null,
  "aqi": null,
  "tvoc_ppb": null,
  "eco2_ppm": null,
  "motion": false,
  "rain": false,
  "fault": false
}
```

### bat_sen (Batterie)

```json
{
  "device_id": "bat_sen_010",
  "battery_pct": 85,
  "battery_mv": 2900,
  "window_open": 0,
  "rain_raw": null,
  "button_flags": 0,
  "report_interval_s": 43200,
  "fault": false
}
```

**`window_open`:** `0` = geschlossen, `1` = offen, `null` = nicht zutreffend (z.B. Regensensor).

**`report_interval_s`:** Meldeintervall des Batteriegeräts. Der Server nutzt diesen Wert für die Anzeige von schlafenden BAT-SEN-Geräten.

**Null-Werte:** Felder die für das jeweilige Gerät nicht zutreffen sind `null` (z.B. `rain_raw` beim Fensterkontakt, `window_open` beim Regensensor).

---

## Event-Payload

```json
{
  "device_id": "NET-ERL-010",
  "event": "motion_detected",
  "event_type": 2,
  "trigger": 3,
  "param1": 1,
  "param2": 0
}
```

### Event-Typen

| event_type | event | Beschreibung |
|---:|---|---|
| 1 | `button_press` | Taster gedrückt |
| 2 | `motion_detected` | Bewegung erkannt |
| 3 | `window_opened` | Fenster geöffnet |
| 4 | `window_closed` | Fenster geschlossen |
| 5 | `rain_detected` | Regen erkannt |
| 6 | `relay_changed` | Relais geschaltet |
| 7 | `light_auto_on` | Auto-Light ein |
| 8 | `light_auto_off` | Auto-Light aus |
| 9 | `cover_up` | Rollladen hoch |
| 10 | `cover_down` | Rollladen runter |
| 11 | `cover_stop` | Rollladen Stop |
| 12 | `cover_calib_start` | Rollladen-Kalibrierung gestartet |
| 13 | `cover_calib_done` | Rollladen-Kalibrierung abgeschlossen |
| 14 | `node_boot` | Gerät gestartet |
| 15 | `sensor_fault` | Sensorfehler |
| 16 | `comm_fault` | Kommunikationsfehler |
| 17 | `button_release` | Taster losgelassen |
| 18 | `button_long_press` | Taster lang gedrückt (Setup) |

### Trigger

| trigger | Bedeutung |
|---:|---|
| 1 | `manual_button` - lokaler Taster |
| 2 | `master_cmd` - Kommando vom Master/Server |
| 3 | `auto` - automatisch (Bewegung, Fenster, Regen) |
| 4 | `auto_off_timer` - Timeout (Auto-Light aus) |

---

## Command-Payload (Broker → Gerät)

Topic: `smarthome/device/{device_id}/command`

### get_state
```json
{
  "command": "get_state",
  "request_id": "req-123"
}
```
→ Löst State-Report aus. ACK: `{"status":"sent","status_code":0}`

### set_relay
```json
{
  "command": "set_relay",
  "request_id": "req-124",
  "relay_1": true
}
```
→ Schaltet Relais. ACK: `{"status":"ok","status_code":0}`

### Cover-Kommandos
```json
{"command": "open", "request_id": "req-125"}
{"command": "close", "request_id": "req-126"}
{"command": "stop", "request_id": "req-127"}
{"command": "set_position", "request_id": "req-128", "position": 75}
```

### set_config
```json
{
  "command": "set_config",
  "request_id": "req-129",
  "values": {"report_interval_s": 30}
}
```

**Hinweis:** ESPHome-Geräte akzeptieren in `set_config` derzeit nur `master_mac`.
Weitere Konfigurationswerte (`report_interval_s`, `auto_on_lux_threshold` etc.)
werden nur über den Firmware-Master-Pfad (ESP-NOW) unterstützt.

## ACK-Payload (Master → Broker)

```json
{
  "device_id": "NET-ERL-010",
  "request_id": "req-123",
  "channel": "command",
  "status": "ok",
  "status_code": 0,
  "source": "node_ack"
}
```

**`status` Werte:**

| status | Bedeutung | Master Firmware | ESPHome | master_compat |
|---|---|:-:|:-:|:-:|
| `ok` | Erfolg | 0 | 0 | 0 |
| `sent` | Gesendet (get_state) | 0 | 0 | 0 |
| `busy` | Gerät hat noch offenen Auftrag | -2 | -2 | -2 |
| `timeout` | Keine ACK-Antwort erhalten | 3 | — | 3 |
| `unsupported` | Kommando nicht unterstützt | **-3** | **-2** | **-2** |
| `invalid_payload` | Ungültiger Payload (JSON-Fehler, fehlende Felder) | -21 | -21 | -21 |
| `send_failed` | ESP-NOW-Versand fehlgeschlagen | -4 | — | -4 |
| `not_calibrated` | Rollladen nicht kalibriert | -5 | -5 | -5 |
| `unknown_device` | Gerät nicht registriert | -6 | -6 | -6 |
| `registry_full` | Registry voll (max. 16 Nodes) | -7 | — | — |
| `no_route` | MAC-Adresse unbekannt | -8 | — | — |
| `meta_required` | HELLO-Metadaten fehlen | -9 | — | — |
| `missing_request_id` | request_id fehlt im Payload | — | -20 | -20 |

> **Hinweis zu abweichenden Codes:** Die drei Linien verwenden teils
> unterschiedliche Codes für dieselbe Bedeutung.
> - `unsupported`: Master Firmware `-3`, ESPHome/master_compat `-2`
> - `invalid_payload`: alle Linien verwenden `-21`
> - `—` = Code wird von dieser Linie nicht verwendet.

## Availability-Payload

```json
{
  "device_id": "NET-ERL-010",
  "availability": "online",
  "online": true,
  "power_type": "mains"
}
```
- `online: true` → Gerät ist per MQTT erreichbar
- `online: false` → Gerät per Last-Will als offline gemeldet
- `power_type` ist `mains` oder `battery`, sobald `HELLO`-Meta vorliegt; bei provisorischen Master-Einträgen ohne `HELLO` ist der Wert `unknown`.

---

## Sensor-Offsets

Jedes Gerät unterstützt Temperatur- und Feuchte-Offsets zur Kompensation von Einbaufehlern:

| Gerät | temp_offset_01c | hum_offset_01pct |
|---|---:|---:|
| `NET-ERL-010` (Flur) | 0 | 0 |
| `NET-ERL-020` (LED Ring) | 0 | 0 |
| `NET-SEN-020` (Wetter) | 0 | 0 |

Offsets werden in Geräte-Nativeinheiten angegeben (Zehntelgrad, Zehntelprozent).
Negativer Wert = Korrektur nach unten. Positiver Wert = Korrektur nach oben.

Beispiel: BME280 nahe Netzteil misst 30 °C bei 22 °C Raumtemperatur → `temp_offset_01c = -80` (-8,0 °C).

---

## Topic-Struktur (Zusammenfassung)

```
smarthome/
├── master/{master_id}/
│   ├── status          (retained, Master-Status)
│   └── event           (transient, Master-Ereignisse)
└── device/{device_id}/
    ├── meta            (retained, Metadaten)
    ├── availability    (retained, Online/Offline)
    ├── state           (retained, Live-Zustand)
    ├── event           (transient, Ereignisse)
    ├── ack             (transient, Kommando-Bestätigung)
    └── command         (Eingang, Kommandos vom Server)
```

---

*Stand: 2026-05-24 – nach Angleichung Firmware/ESPHome*

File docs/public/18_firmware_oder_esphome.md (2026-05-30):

# Eigene Firmware oder ESPHome?

## Kurzfassung

Dieses Projekt bietet zwei Wege, um ESP32-Geräte an den Server anzubinden.

Die **eigene Firmware** ist die Architektur-Hauptlinie des Technikerprojekts. Sie nutzt ESP-NOW zwischen Gerät und Master. Der Master übersetzt zwischen ESP-NOW und MQTT. Das ist technisch kontrollierter, besser erklärbar und näher an der eigentlichen Projektarchitektur.

Die **ESPHome-Alternative** ist für Nutzer gedacht, die lieber mit ESPHome, Home Assistant und YAML arbeiten. Diese Geräte sprechen direkt MQTT mit dem Server. Der Master wird dabei nicht genutzt. Der Vorteil ist ein schnellerer Einstieg und eine bekannte Werkzeugkette.

Beide Linien sollen denselben Serververtrag bedienen. Der Server interessiert sich vor allem dafür, dass die MQTT-Topics und Payload-Felder stimmen.

## Gemeinsamer Serververtrag

Der Server erwartet pro Gerät klar strukturierte MQTT-Nachrichten:

- `smarthome/device/<device_id>/meta`
- `smarthome/device/<device_id>/availability`
- `smarthome/device/<device_id>/state`
- `smarthome/device/<device_id>/event`
- `smarthome/device/<device_id>/ack`
- `smarthome/device/<device_id>/command`

Für die Anzeige ist `state` die Hauptwahrheit. `meta` beschreibt das Gerät, `availability` zeigt die Erreichbarkeit, `ack` bestätigt Befehle und `event` ergänzt Zustandsänderungen.

## Weg 1: Eigene Firmware

Die eigene Firmware liegt unter `firmware/`.

Sie ist sinnvoll, wenn du:
- den ESP-NOW-Funkpfad selbst kontrollieren willst
- den Master als klare Brücke zwischen Geräteebene und Server erklären möchtest
- Verhalten, Timing, Provisionierung und Fehlerbehandlung selbst in C++ steuern willst
- die Technikerarbeit stärker als eigenes eingebettetes System zeigen willst
- Gerätefunktionen bewusst in Basistyp und konkrete Geräteschicht trennen möchtest

Aktuelle Basistypen und Geräte:

| Bereich | Zweck |
|---|---|
| `master_firmware` | Brücke zwischen ESP-NOW und MQTT |
| `net_erl` | netzbetriebener Relais-/Lichttyp |
| `net_zrl` | netzbetriebener Rollladentyp mit zwei Relais |
| `net_sen` | netzbetriebener Sensortyp |
| `bat_sen` | batteriebetriebener Sensortyp mit Sleep-Konzept |
| `net_erl_hall_module` | Hall-Modul mit Relais, BME280, VEML7700 und PIR |
| `net_erl_hall_module_led_ring` | Hall-Modul mit Relais, Sensorik, Button und LED-Ring |
| `net_sen_weather_station` | Wetterstation mit BME280, VEML7700 und Regen-Digitalpfad |
| `net_zrl_shutter_module` | Rollladenmodul mit zwei Relais, lokalen Tastern und Kalibrierung |
| `bat_sen_window_contact` | Batterie-Fensterkontakt |
| `bat_sen_rain_sensor` | Batterie-Regensensor |

Der Preis dieser Linie: mehr eigener Code, mehr Verantwortung beim Testen und mehr Aufwand pro Gerät. Die Stärke liegt genau darin, dass das Verhalten wirklich im eigenen System liegt und nicht in einer fertigen ESPHome-Abstraktion verschwindet.

## Weg 2: ESPHome-Alternative

Die ESPHome-Alternative liegt unter `esphome/`.

Sie ist sinnvoll, wenn du:
- ESPHome oder Home Assistant bereits nutzt
- Geräte schnell über YAML bauen und flashen willst
- direktes WLAN/MQTT statt ESP-NOW akzeptierst
- den Master nicht brauchst
- den Serververtrag des Projekts trotzdem verwenden möchtest

Vorbereitete ESPHome-Geräte:

| Datei | MQTT-Device-ID | Zweck |
|---|---:|---|
| `devices/net_erl_hall_module.yaml` | `NET-ERL-010` | Hall-Modul mit Relais, BME280, VEML7700 und PIR |
| `devices/net_erl_hall_module_led_ring.yaml` | `NET-ERL-020` | Hall-Modul mit Relais, Sensorik, Button und LED-Ring |
| `devices/net_sen_weather_station.yaml` | `NET-SEN-020` | Wetterstation mit BME280, VEML7700 und Regen-Digitalpin |
| `devices/net_zrl_shutter_module.yaml` | `NET-ZRL-020` | Rollladenmodul mit zwei Relais, lokalen Tastern, LEDs und Kalibrierung |
| `devices/bat_sen_window_contact.yaml` | `bat_sen_010` | Batterie-Fensterkontakt |
| `devices/bat_sen_rain_sensor.yaml` | `bat_sen_020` | Batterie-Regensensor |

Der Preis dieser Linie: kein ESP-NOW, kein Masterpfad, weniger eigene Kontrolle über die unteren Abläufe. Dafür ist der Einstieg pragmatischer und für ESPHome-Nutzer deutlich näher an ihrer gewohnten Entwicklungsumgebung.

## Entscheidungshilfe

| Frage | Eher eigene Firmware | Eher ESPHome |
|---|---|---|
| Soll ESP-NOW Teil des Projekts bleiben? | Ja | Nein |
| Soll der Master als klare Brücke gezeigt werden? | Ja | Nein |
| Ist schnelle YAML-Konfiguration wichtiger als eigener Gerätecode? | Nein | Ja |
| Soll Home Assistant/ESPHome die Build- und Flash-Werkzeuge liefern? | Nicht zentral | Ja |
| Ist maximale Kontrolle über Timing, Provisionierung und ACK-Logik wichtig? | Ja | Teilweise |
| Soll der Server möglichst denselben Vertrag sehen? | Ja | Ja |

## Praktische Empfehlung

Für die Technikerarbeit ist die eigene Firmware-Linie die stärkere Hauptargumentation: Sie zeigt Architektur, Embedded-Logik, Funkstrecke, Masterrolle, Serververtrag und Nachweisführung aus einem Guss.

Für Nutzer, die das System praktisch nachbauen oder in eine vorhandene ESPHome-Umgebung einordnen möchten, ist die ESPHome-Linie der leichtere Einstieg. Sie sollte aber nicht als Beweis für die ESP-NOW-/Master-Architektur verkauft werden. Das wäre fachlich unsauber.

## Was vor produktivem Einsatz zu prüfen ist

Unabhängig von der Linie müssen reale Geräte geprüft werden:

- Pinbelegung pro Board
- Relaisrichtung und Active-Level
- Verriegelung bei Rollladen-Auf/Ab
- Endlagen und Kalibrierung
- Sensoradressen und Messwerte
- Batterie-ADC und Schwellwerte
- MQTT-Topics und Payload-Felder
- Dashboard-Anzeige und ACK-Verhalten

Das Projekt ist bewusst so dokumentiert, dass Fortschritt belegt werden kann. Behauptete Gerätepfade ohne Testnachweis sind kein belastbarer Stand.

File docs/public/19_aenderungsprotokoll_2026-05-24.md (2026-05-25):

# Aenderungsprotokoll 2026-05-24

Dieses Protokoll dokumentiert die technischen Anpassungen am Server-, ESPHome- und Firmware-Pfad.

## MQTT-Broker und Node-RED

- Node-RED nutzt den MQTT-Broker nicht mehr hart codiert, sondern `MQTT_HOST` und `MQTT_PORT`.
- Der lokale Compose-Broker bleibt als Standard fuer Standalone-Betrieb und Tests erhalten.
- Fuer Installationen mit dauerhaftem Mosquitto im Netz muss `MQTT_HOST` auf diesen Broker zeigen.
- Die oeffentliche Dokumentation beschreibt nur den Netz-Broker und nennt keine internen Serverdetails.

## MQTT-Steuerbefehle

- Node-RED publiziert Steuerbefehle jetzt als JSON-Text, nicht als JavaScript-Objekt.
- Das betrifft manuelle Relaisbefehle, manuelle Rolladenbefehle und faellige Rolladen-Automatikbefehle.
- Der gemeinsame MQTT-Vertrag bleibt:
  - Topic `smarthome/device/<device_id>/command`
  - Feld `request_id`
  - Feld `command`
  - fuer Relais `relay_1`
  - fuer Rolladen `position` bei `set_position`

## ESPHome OTA

- OTA ist zentral im ESPHome-Basis-Package aktiviert.
- Die produktive Secret-Datei braucht dafuer `ota_password`.
- Die zuerst per Kabel geflashte Factory-Firmware muss bereits mit diesem OTA-Block gebaut sein.
- Batteriebetriebene ESPHome-Geraete markieren ihren kurzen Bootlauf als erfolgreich, damit Deep Sleep nicht als fehlgeschlagener Boot gewertet wird.

## ESP32-C3 Strapping-Pins

- Der Rolladen-Up-Taster wurde von `GPIO2` auf `GPIO20` gelegt.
- Hintergrund: `GPIO2` ist beim ESP32-C3 ein Strapping-Pin und kann beim Reset den Bootmodus beeinflussen.
- Geaendert wurden beide Codegruppen:
  - ESPHome: `devices/net_zrl_shutter_module.yaml`
  - eigene Firmware: `net_zrl_shutter_module` und der `net_zrl`-Fallback
- `GPIO0` und `GPIO1` bleiben fuer I2C reserviert.
- `GPIO8` wurde beim LED-Ring-Modul als Datenpin verworfen, weil es ein ESP32-C3-Strapping-Pin ist. Der LED-Ring liegt stattdessen auf `GPIO4`.

## Geprueft

- Alle ESPHome-YAMLs validieren erfolgreich.
- Ein repraesentatives ESPHome-Geraet kompiliert erfolgreich mit OTA.
- Das erzeugte OTA-Image passt in den OTA-Slot.
- Node-RED-Flow-JSON ist syntaktisch gueltig.
- Die Node-RED-Function-Nodes fuer Steuerung und Rolladen-Automatik sind syntaktisch gueltig.
- Der MQTT-Befehlsvertrag passt zur ESPHome-Linie und zur Master-/Firmware-Linie.

## Offene Hardware-Pruefung

- Nach dem naechsten OTA-Test sollte die serielle Konsole beim ersten Neustart mitlaufen.
- Wenn weiterhin ein Bootloop auftritt, sind die ersten Bootmeldungen nach Reset entscheidend.
- Besonders zu pruefen sind Pegel auf ESP32-C3-Strapping-Pins waehrend Reset und Boot.

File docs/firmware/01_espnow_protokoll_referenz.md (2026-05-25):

# ESP-NOW SmartHome Protokoll-Referenz

**Stand:** Firmware v1 · **Protokoll-Version:** 1 · **Magic Byte:** `0xA5`

---

## Inhaltsverzeichnis

1. [Überblick](#1-überblick)
2. [Paketaufbau (Layer 2)](#2-paketaufbau-layer-2)
3. [Header-Flags](#3-header-flags)
4. [Message-Typen](#4-message-typen)
5. [Payload-Strukturen](#5-payload-strukturen)
6. [Events & Trigger](#6-events--trigger)
7. [Command-Typen](#7-command-typen)
8. [Config-Parameter](#8-config-parameter)
9. [Cover-Commands](#9-cover-commands)
10. [Relay-Comfort-Flags](#10-relay-comfort-flags)
11. [ACK-Status-Codes](#11-ack-status-codes)
12. [Fehlercodes](#12-fehlercodes)
13. [Hilfsfunktionen](#13-hilfsfunktionen)
14. [Globale Konstanten](#14-globale-konstanten)

---

## 1. Überblick

Das SmartHome-Protokoll nutzt **ESP-NOW** als Transportlayer. Es ist ein binäres, verbindungsloses Protokoll mit optionaler ACK-Anforderung und CRC16-Sicherung.

| Eigenschaft | Wert |
|---|---|
| Magic Byte | `0xA5` |
| Protokoll-Version | `1` |
| Max. ESP-NOW Nutzlast | 250 Bytes |
| Header-Größe | 10 Bytes |
| Max. Payload-Größe | 240 Bytes |
| CRC | CRC16-CCITT (Poly `0x1021`) |
| Byte-Order | Little-Endian |

---

## 2. Paketaufbau (Layer 2)

Jedes ESP-NOW-Paket besteht aus einem **festen 10-Byte-Header** gefolgt von einem **variablen Payload** (0–240 Bytes).

### 2.1 MsgHeader (10 Bytes)

```
Offset  Größe  Feld            Beschreibung
──────────────────────────────────────────────────────
 0       1     magic           Magic Byte 0xA5
 1       1     proto_ver       Protokoll-Version (1)
  2       1     msg_type        Message-Typ (0x01–0x07, 0x09)
 3       1     seq             Sequenznummer (0–255)
 4       1     flags           Bit-Flags (siehe §3)
 5       1     _reserved       Reserviert (0)
 6       2     payload_len     Länge des Payload (Little-Endian)
 8       2     crc16           CRC16 über Header + Payload
──────────────────────────────────────────────────────
Total:   10 Bytes
```

```c
typedef struct __attribute__((packed)) {
    uint8_t  magic;
    uint8_t  proto_ver;
    uint8_t  msg_type;
    uint8_t  seq;
    uint8_t  flags;
    uint8_t  _reserved;
    uint16_t payload_len;
    uint16_t crc16;
} MsgHeader;
```

### 2.2 Sequenznummern-System

Jedes Gerät führt einen eigenen 8-Bit-Sequenzzähler (`naechste_seq`, 0–255).
Bei jedem neuen ESP-NOW-Paket wird die aktuelle Sequenznummer verwendet und
der Zähler inkrementiert. Bei 255 erfolgt ein Überlauf zurück auf 0.

**Verwendung:**
- **ACK-Zuordnung**: Der Empfänger (Master) korreliert eingehende ACKs über
  die Sequenznummer mit dem ausstehenden Befehl (Pending-Slot).
- **Retry**: Bei Wiederholungen wird dieselbe Sequenznummer verwendet, damit
  der Empfänger Duplikate erkennen kann.
- **Duplikaterkennung**: Der Master ignoriert Pakete mit bereits bekannter
  Sequenznummer (kein Replay).

**Implementierung (sendePaketMitRetry):**
1. Aktuelle Sequenznummer sichern (`savedSeq = naechste_seq`)
2. Erstversand: sendPacket() → inkrementiert `naechste_seq` intern
3. Bei Misserfolg: `naechste_seq = savedSeq` (gleiche Seq für Retry)
4. Maximal NET_ERL_ESPNOW_RETRY_COUNT Wiederholungen

### 2.3 CRC16-Berechnung

Der CRC wird **über Header (ohne crc16-Feld) + Payload** gebildet:

```
CRC-Daten = magic[0] + proto_ver[1] + msg_type[2] + seq[3] + flags[4] + _reserved[5]
          + payload_len[6-7] + payload[0..payload_len-1]
```

**Algorithmus:** CRC16-CCITT mit Polynom `0x1021`, Startwert `0xFFFF`.

---

## 3. Header-Flags

| Flag | Wert | Beschreibung |
|---|---|---|
| `SH_FLAG_ACK_REQUEST` | `0x01` | Empfänger muss mit ACK antworten |
| `SH_FLAG_RETRANSMIT` | `0x02` | Paket ist eine Wiederholung |
| `SH_FLAG_ENCRYPTED` | `0x04` | Payload ist verschlüsselt |

Mehrere Flags können per OR kombiniert werden.

---
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

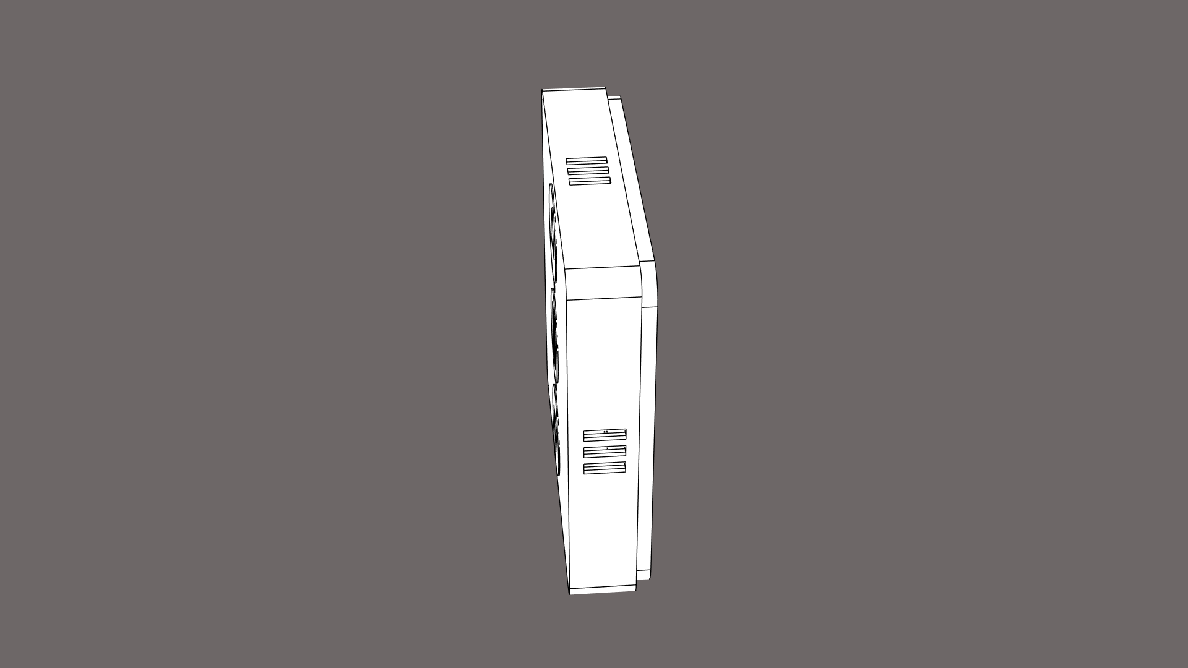
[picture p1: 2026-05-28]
hardware/3d_models/net_zrl/pictures/gif_product/frame_076.png

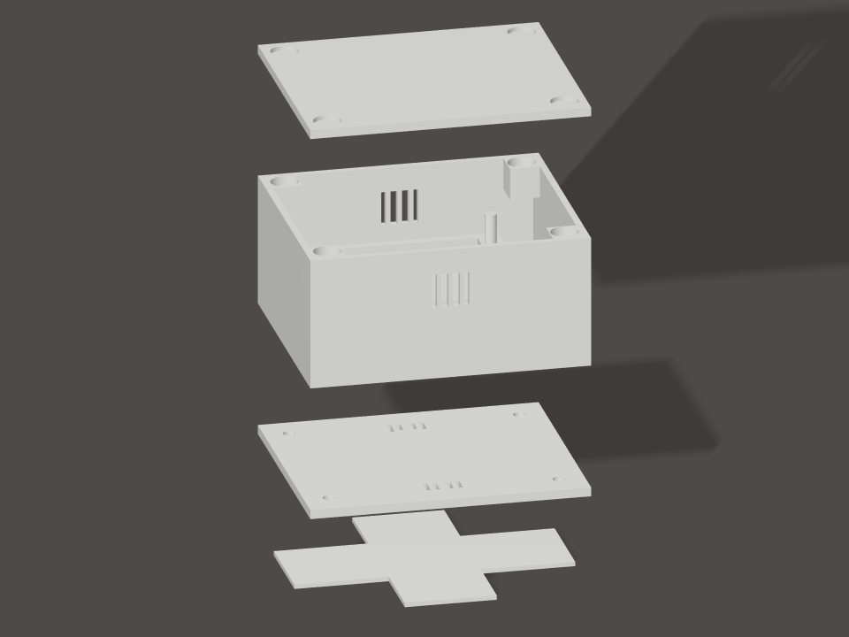
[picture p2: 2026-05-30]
hardware/3d_models/bat_sen/pictures/_frames/gif1/f0022.png

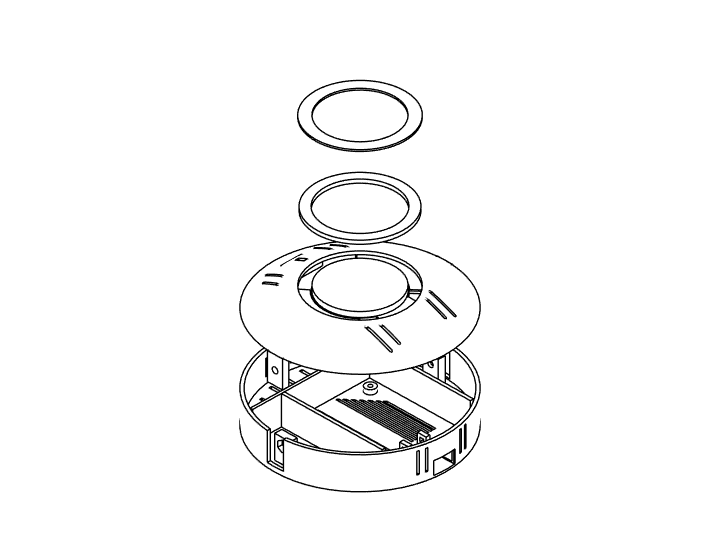
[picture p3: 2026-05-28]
hardware/3d_models/net_erl/pictures/with_led_ring/gif/3/explode_005.png

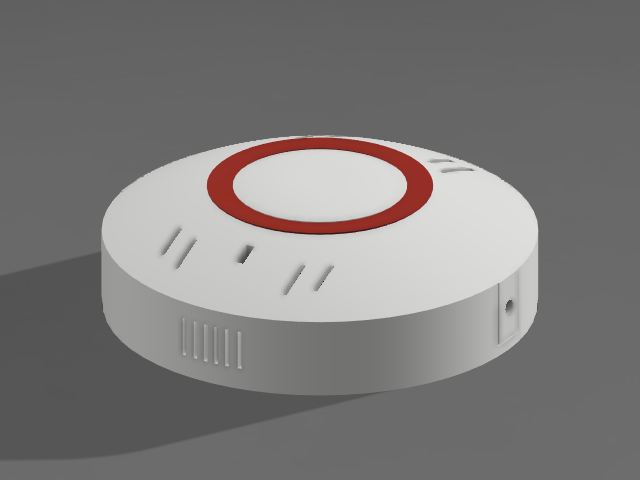
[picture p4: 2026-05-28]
hardware/3d_models/net_erl/pictures/with_led_ring/gif/1/frame_035.png

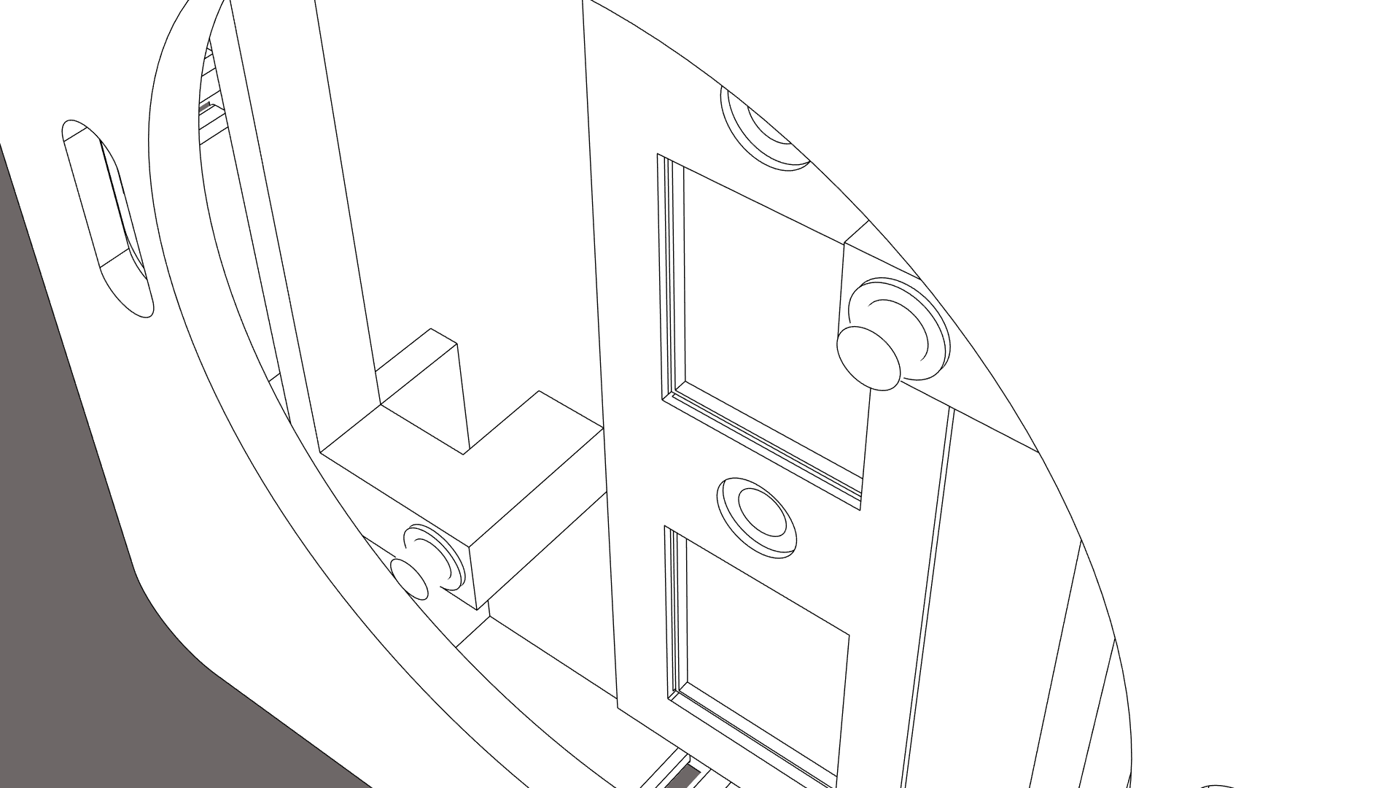
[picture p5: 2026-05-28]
hardware/3d_models/net_zrl/pictures/gif_360/frame_042.png

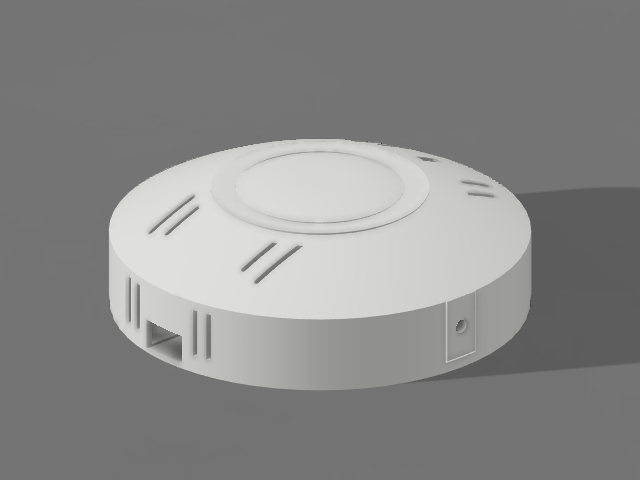
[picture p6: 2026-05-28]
hardware/3d_models/net_erl/pictures/with_led_ring/gif/1/frame_008.png

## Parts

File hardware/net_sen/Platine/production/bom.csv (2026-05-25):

Designator | Footprint | Quantity | Value | LCSC Part #
C1 | CP_Elec_6.3x5.8 | 1 | 100uF
C2 | 0805 | 1 | 100nF
ESP32-C3_SUPERMINI_TH | MODULE_ESP32-C3_SUPERMINI_TH | 1 | ESP32-C3_SUPERMINI_TH
F1 | Fuseholder_Clip-5x20mm_Bel_FC-203-22_Lateral_P17.80x5.00mm_D1.17mm_Horizontal | 1 | Fuse
J1 | PinHeader_1x06_P2.54mm_Vertical | 1 | Co_x6_GND
J2 | PinHeader_1x06_P2.54mm_Vertical | 1 | Co_x6_3V3
J3 | PinHeader_1x05_P2.54mm_Vertical | 1 | Co_GPIOx1
J4 | PinHeader_1x05_P2.54mm_Vertical | 1 | Co_GPIOx2
J5 | TerminalBlock_Phoenix_MKDS-1,5-3_1x03_P5.00mm_Horizontal | 1 | Input_x3
J6 | PinHeader_1x01_P2.54mm_Vertical | 1 | Co_x1_5V0
J7 | PinHeader_1x03_P2.54mm_Vertical | 1 | Co_GPIOx3
JP1, JP2 | SolderJumper-2_P1.3mm_Open_Pad1.0x1.5mm | 2 | Bridge_I2C
PS1 | Converter_ACDC_Hi-Link_HLK-PMxx | 1 | HLK-PM03
R3, R4 | 0805 | 2 | 4K7

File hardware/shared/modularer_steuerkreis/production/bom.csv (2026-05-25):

Designator | Footprint | Quantity | Value | LCSC Part #
J1 | SolderWire-0.25sqmm_1x05_P4.2mm_D0.65mm_OD1.7mm | 1 | Wire_5
J3 | PinHeader_1x05_P2.54mm_Vertical | 1 | Co_GPIOx1
J6 | PinHeader_1x06_P2.54mm_Vertical | 1 | Conn_Vx1
J7 | PinHeader_1x03_P2.54mm_Vertical | 1 | Co_GPIOx3
JP1, JP2 | SolderJumper-2_P1.3mm_Open_Pad1.0x1.5mm | 2 | Bridge_I2C
MH_2, MH | Mounting_Hole_M3 | 2 | Mounting_Hole_M3
R3, R4 | 0805 | 2 | 4K7
TP1, TP2, TP3, TP4, TP5 | TestPoint_Pad_D1.0mm | 5 | TestPoint
U3 | MODULE_ESP32-C3_SUPERMINI_TH | 1 | ESP32-C3_SUPERMINI_TH

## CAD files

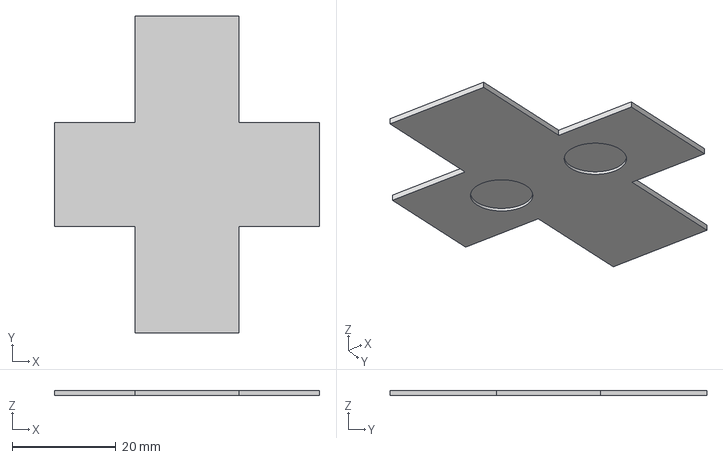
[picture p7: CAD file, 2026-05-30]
hardware/3d_models/bat_sen/V2/Wandhalterung_V2.3mf
51.0 x 61.0 x 1.00 mm

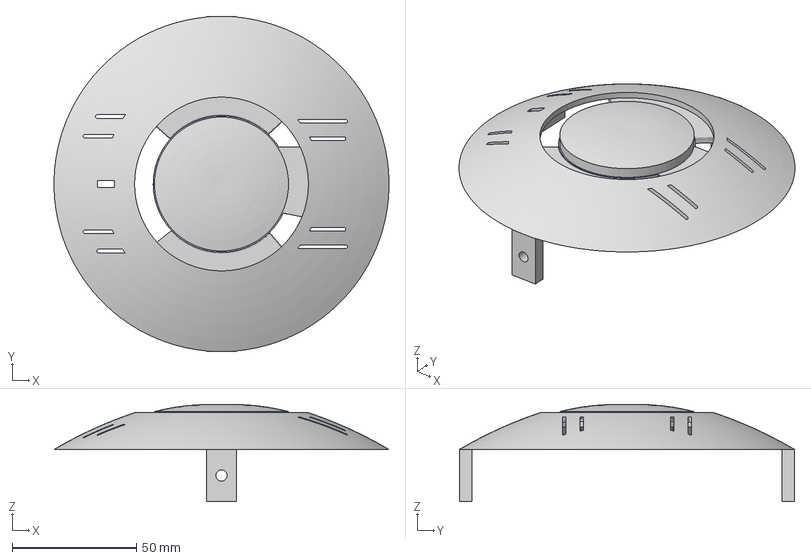
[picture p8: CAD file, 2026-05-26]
hardware/3d_models/net_erl/Deckel_LED_Ring.3mf
134.9 x 135.0 x 39.1 mm

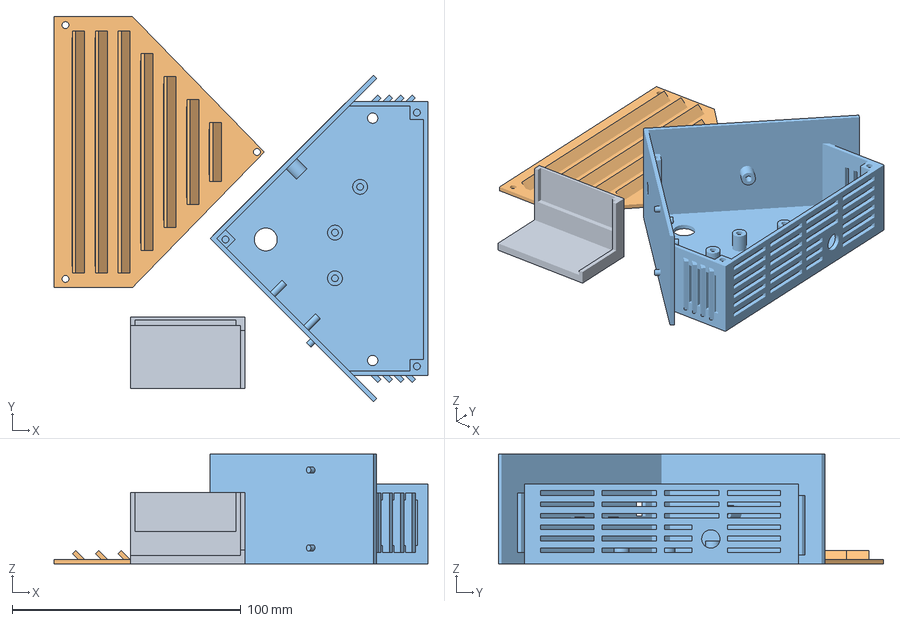
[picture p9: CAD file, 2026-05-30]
hardware/3d_models/net_sen/Arduino+Weather+Center.3mf
163.6 x 168.5 x 48.0 mm
Arduino Weather Center Roof Guard.stl
Arduino Weather Center Front.stl
Arduino Weather Center Main Unit.stl

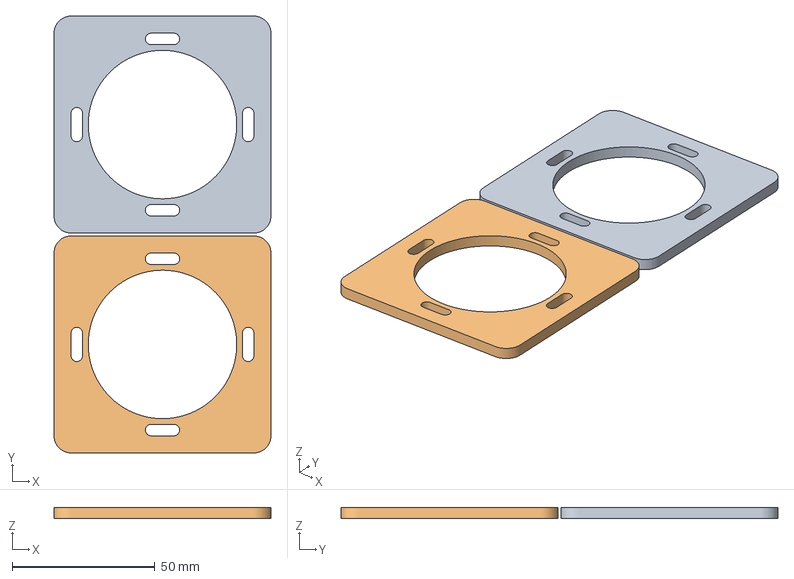
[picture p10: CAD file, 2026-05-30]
hardware/3d_models/net_zrl/Abstandshalter.3mf
76.0 x 153.0 x 4.00 mm
Abstandshalter x 2

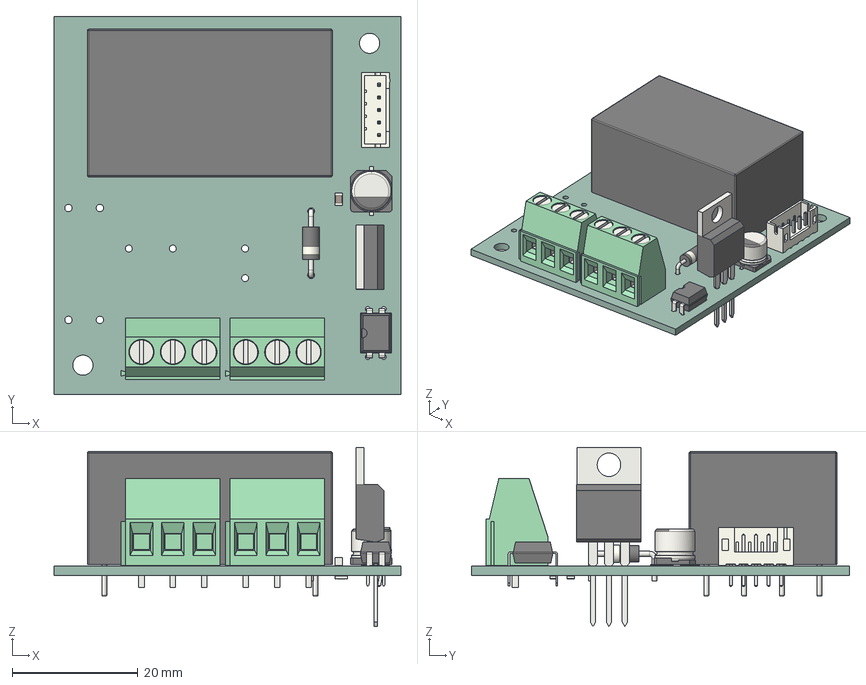
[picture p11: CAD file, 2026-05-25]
hardware/net_erl/Basetype/leistungskreis/leistungskreis.step
55.2 x 60.2 x 28.5 mm
JST_PH_B5B-PH-K_1x05_P2.00mm_Vertical
TO-220-3_Vertical
TerminalBlock_Phoenix_MKDS-1,5-3_1x03_P5.00mm_Horizontal x 2
C_0805_2012Metric
DIP-4_W7.62mm
D_DO-41_SOD81_P10.16mm_Horizontal
CP_Elec_6.3x5.8
Converter_ACDC_Hi-Link_HLK-5Mxx
R_0805_2012Metric x 2
Leistungskreis_1Relai_korrektur_PCB

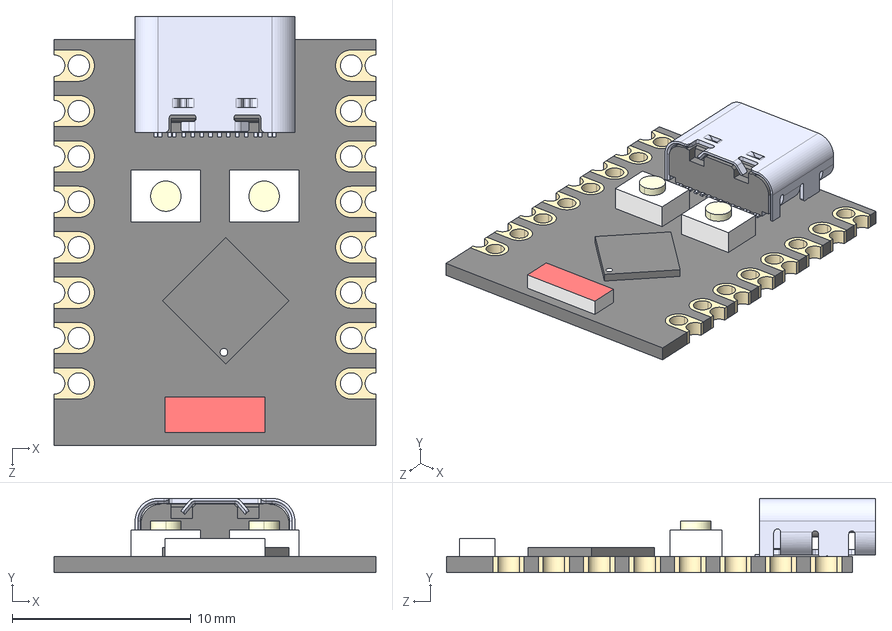
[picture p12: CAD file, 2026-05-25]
hardware/shared/esp32-c3-supermini/ESP32-C3_SUPERMINI_TH.step
18.0 x 4.16 x 24.0 mm
Board c3mini
USB C
components (other)^ESP32-C3 SuperMini

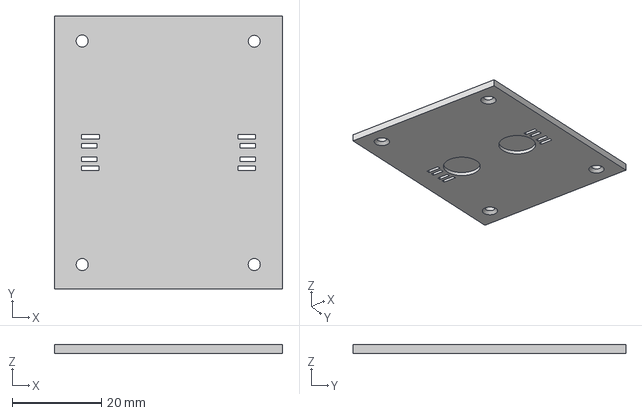
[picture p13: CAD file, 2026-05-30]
hardware/3d_models/bat_sen/V2/Abdeckung_unten_V2.3mf
51.0 x 61.0 x 2.00 mm

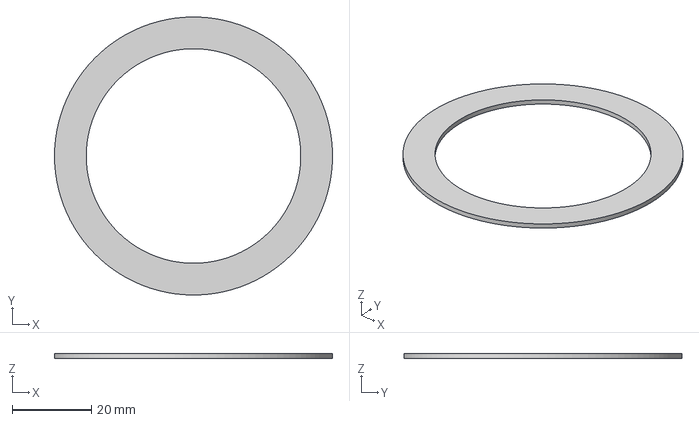
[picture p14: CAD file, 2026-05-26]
hardware/3d_models/net_erl/Diffusor_PTEG.3mf
70.0 x 70.0 x 1.20 mm

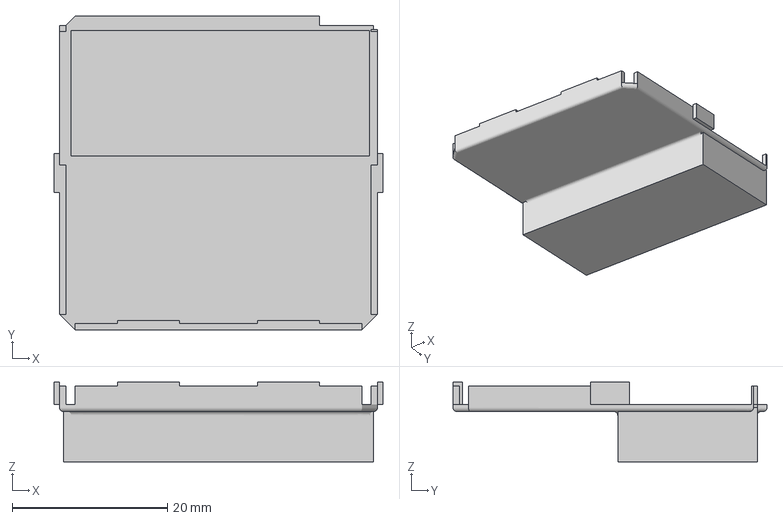
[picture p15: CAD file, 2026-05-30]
hardware/3d_models/net_zrl/PCB_Protection.3mf
42.4 x 40.5 x 10.3 mm

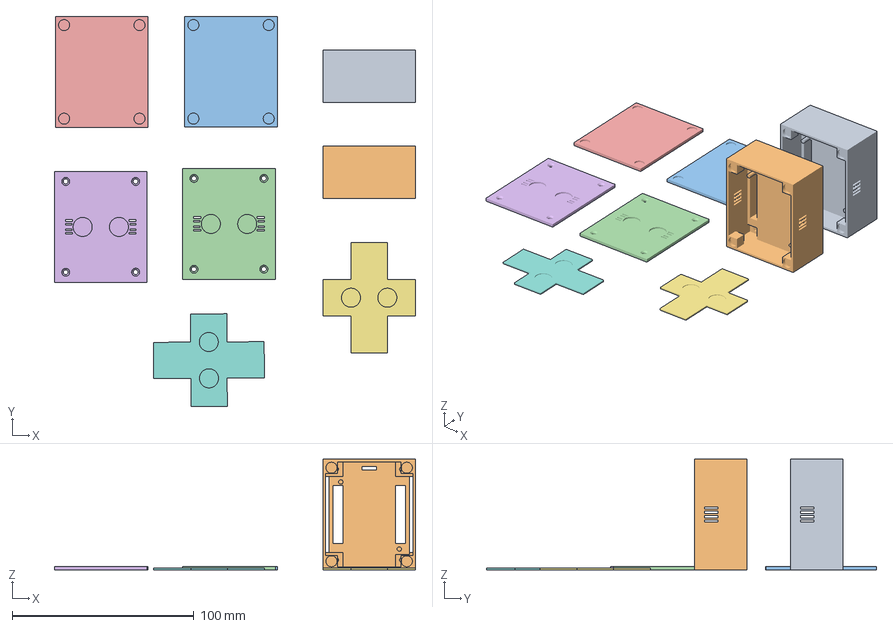
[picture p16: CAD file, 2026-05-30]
hardware/3d_models/bat_sen/V2/Abdeckung_oben_V2.3mf
198.7 x 214.8 x 61.0 mm
Hauptkörper x 2
Abdeckung_oben x 2
Abdeckung_unten x 2
Wandhalterung x 2

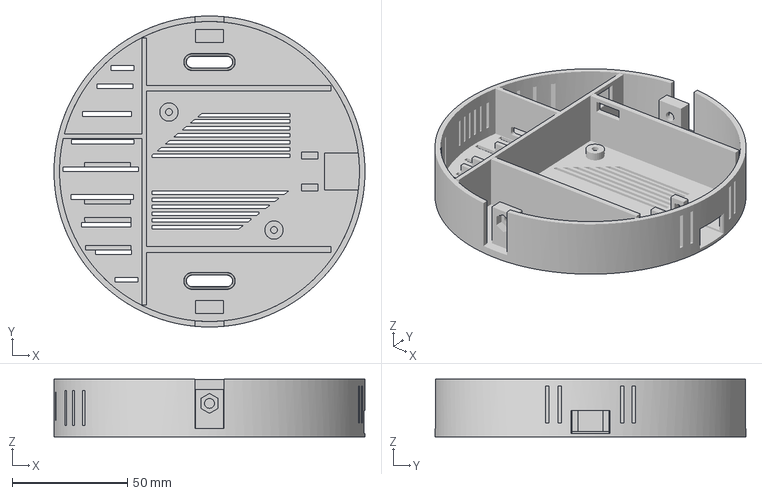
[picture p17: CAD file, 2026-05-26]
hardware/3d_models/net_erl/Basis.3mf
135.0 x 135.0 x 25.0 mm

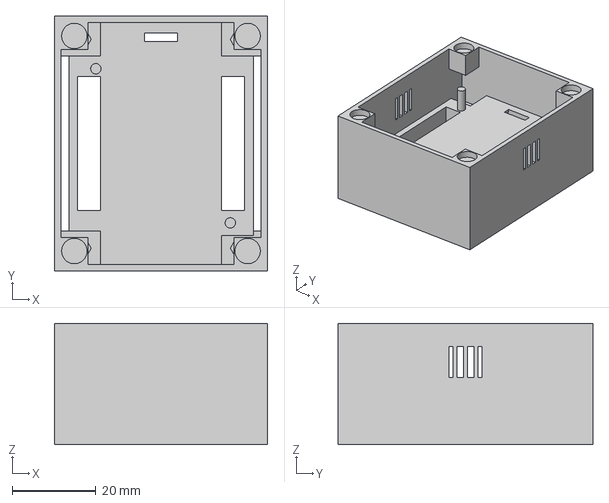
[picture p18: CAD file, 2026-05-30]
hardware/3d_models/bat_sen/V2/Hauptkörper_V2.3mf
51.0 x 61.0 x 29.0 mm

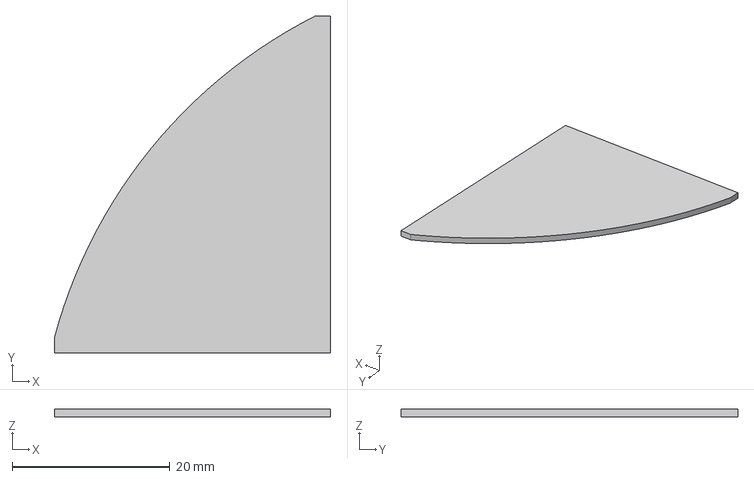
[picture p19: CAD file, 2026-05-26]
hardware/3d_models/net_erl/Abdeckung.3mf
35.0 x 42.8 x 1.00 mm

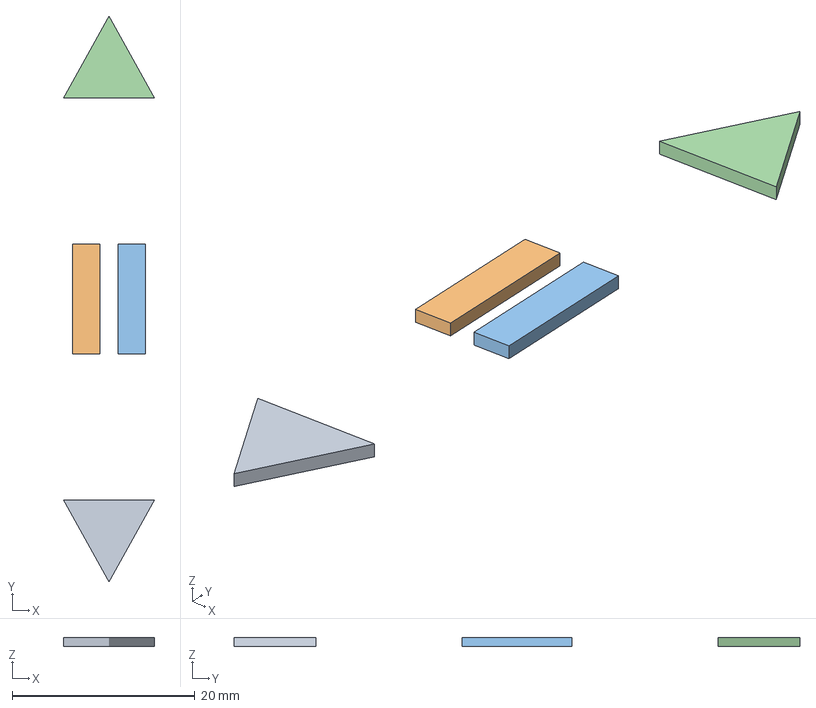
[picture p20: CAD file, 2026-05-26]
hardware/3d_models/net_zrl/zeichen.3mf
10.0 x 62.0 x 1.00 mm
Button_down2
Button_middle1
Button_middle2
Button_up2

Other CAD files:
hardware/3d_models/net_erl/Trennwand.3mf
hardware/3d_models/net_zrl/BODY_FRONT_CONTROL_BASE_V2.3mf
hardware/3d_models/net_erl/Deckel_PIR.3mf
hardware/3d_models/net_zrl/WALL_ADAPTER_COPY_V2.3mf
hardware/3d_models/bat_sen/V1/Alle_Teile.3mf
hardware/3d_models/net_zrl/PCB_Protection_old.3mf
hardware/3d_models/net_zrl/buttons.3mf

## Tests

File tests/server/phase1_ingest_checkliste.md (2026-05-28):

# Phase 1 Ingest Checkliste

## Ziel

Diese Checkliste prueft nur den Phase-1-Kern:

- MQTT-Ingest
- gemeinsames Geraeteobjekt
- separater Masterpfad
- zentrale SQLite-Writes
- partielle Updates ohne Feldzerstoerung
- minimalen `cover`-State ohne neue Command-Welt
- eine einzige fachliche Wahrheitsbasis in `server/nodered/lib/`

## Vorbereitung

1. aus dem Repo-Root arbeiten
2. fuer manuelle MQTT-Publishes in Windows PowerShell einmal den Container-Publish-Helfer setzen:

```powershell
function Publish-ServerMqtt {
    param(
        [string]$Topic,
        [string]$Payload,
        [switch]$Retain
    )

    $payloadBase64 = [Convert]::ToBase64String([System.Text.Encoding]::UTF8.GetBytes($Payload))
    $retainFlag = if ($Retain) { "1" } else { "" }
    $publishScript = 'if [ -n "$MQTT_RETAIN" ]; then printf "%s" "$MQTT_PAYLOAD_B64" | base64 -d | mosquitto_pub -h localhost -t "$MQTT_TOPIC" -r -s; else printf "%s" "$MQTT_PAYLOAD_B64" | base64 -d | mosquitto_pub -h localhost -t "$MQTT_TOPIC" -s; fi'

    docker compose -f server/docker-compose.yml exec -T `
        -e "MQTT_TOPIC=$Topic" `
        -e "MQTT_PAYLOAD_B64=$payloadBase64" `
        -e "MQTT_RETAIN=$retainFlag" `
        mosquitto sh -lc $publishScript
}
```

3. `docker compose -f server/docker-compose.yml up -d`
4. Node-RED unter `http://localhost:1880` oeffnen
5. Debug-Ansicht beobachten
6. warten, bis der SQLite-Node ohne Install-/Build-Fehler gestartet ist

## Enger Server-Vertrag-Smoke-Test unter PowerShell

Dieser Smoke-Test prueft gezielt den aktuellen Server-Vertrag fuer numerische `caps`, `button_flags`, ACK-`source` und SQL-/Migrationsfehler beim Stack-Start. Er braucht keine lokal installierten Mosquitto-Tools auf dem Host, weil die MQTT-Publishes ueber den laufenden Compose-Service `mosquitto` laufen.

Aus dem Repo-Root:

```powershell
.\tests\server\server_contract_smoke.ps1
```

Wenn der Stack bereits laeuft:

```powershell
.\tests\server\server_contract_smoke.ps1 -SkipStart
```

## Entdopplung vorab pruefen

Vor den MQTT-Tests kurz kontrollieren:

```powershell
rg -n "global.get\\(\"topicRouter\"\\)|global.get\\(\"topicHandlers\"\\)|global.get\\(\"deviceStore\"\\)|global.get\\(\"sqliteWrites\"\\)" server/nodered/flows/active
```

Erwartung:

- `10_mqtt_ingest.json` nutzt `topicRouter`
- `00_boot.json` nutzt `deviceStore`
- `20_device_store.json` und `90_master_diag.json` nutzen `topicHandlers`
- `30_sqlite_persist.json` enthaelt nur den SQLite-Ausfuehrungspfad

Zusatzcheck:

```powershell
rg -n "aliasMap|stateFields|configFields|coerceBoolean\\(|createDevice\\(|INSERT INTO devices|INSERT INTO device_state_latest" server/nodered/flows/active
```

Erwartung:

- keine Treffer in den aktiven Flow-Dateien
- Fachlogik liegt nur noch unter `server/nodered/lib/`

## SQLite-Datei pruefen

Nach dem Start muss die Datenbankdatei vorhanden sein:

```powershell
Test-Path .\server\sqlite\smarthome_phase1.db
```

## Testgerät anlegen

### Meta senden

```powershell
Publish-ServerMqtt -Topic "smarthome/device/net_erl_hall_module/meta" -Retain -Payload '{"device_id":"net_erl_hall_module","device_name":"Hall-Modul","device_class":"net_erl","power_type":"mains","caps":81,"fw_version":"0.1.0","meta_schema_version":1,"control_mode":"relay_light","config_profile":"hall_light","reporting_mode":"hybrid","sensor_mask":"TPL_______","input_mask":"B____"}'
```

Erwartung:

- Geraet wird auto-angelegt
- `identity.device_id` und `identity.device_name` sind gesetzt
- `meta.caps` enthaelt aus der numerischen Bitmaske mindestens `switchable`, `lux`, `motion`, `online_state`, `fault_state`, `ack_tracking`
- `devices` enthaelt oder aktualisiert eine Zeile fuer `net_erl_hall_module`

## Availability prüfen

```powershell
Publish-ServerMqtt -Topic "smarthome/device/net_erl_hall_module/availability" -Retain -Payload '{"device_id":"net_erl_hall_module","availability":"online","online":true}'
```

Erwartung:

- `availability.online = true`
- `availability.availability = online`
- `availability.last_seen_at` wird aktualisiert
- `device_state_latest.online = 1`

## State prüfen

### Erster State

```powershell
Publish-ServerMqtt -Topic "smarthome/device/net_erl_hall_module/state" -Retain -Payload '{"device_id":"net_erl_hall_module","relay_1":true,"motion":true,"lux":120,"fault":false,"report_interval_s":60}'
```

Erwartung:

- `state.relay_1 = true`
- `state.motion = true`
- `state.lux = 120`
- `config.report_interval_s = 60`
- `availability.online` bleibt oder wird `true`
- `device_state_latest` wird fuer dasselbe Geraet aktualisiert

## Minimalen Cover-Pfad pruefen

### Cover-Meta senden

```powershell
Publish-ServerMqtt -Topic "smarthome/device/net_zrl_demo/meta" -Retain -Payload '{"device_id":"net_zrl_demo","device_name":"Rolladen Demo","device_class":"net_zrl","power_type":"mains","caps":8195,"fw_version":"0.1.0","meta_schema_version":1,"control_mode":"cover","config_profile":"cover_basic","reporting_mode":"hybrid","sensor_mask":"__________","input_mask":"B____"}'
```

Erwartung:

- Geraet wird auto-angelegt
- `meta.device_class = NET-ZRL`
- `meta.caps` enthaelt mindestens `cover`, `online_state`, `fault_state`, `ack_tracking`

### Cover-State senden

```powershell
Publish-ServerMqtt -Topic "smarthome/device/net_zrl_demo/state" -Retain -Payload '{"device_id":"net_zrl_demo","cover_state":"closing","cover_position":35,"cover_calibrated":true}'
```

Erwartung:

- `state.cover_state = closing`
- `state.cover_position = 35`
- `state.cover_calibrated = true`
- `availability.online` bleibt oder wird `true`
- `device_state_latest.cover_state = closing`
- `device_state_latest.cover_position = 35`
- `device_state_latest.cover_calibrated = 1`

### Partiellen Cover-State pruefen

```powershell
Publish-ServerMqtt -Topic "smarthome/device/net_zrl_demo/state" -Retain -Payload '{"device_id":"net_zrl_demo","cover_state":"stopped"}'
```

Erwartung:

- `state.cover_state` wird auf `stopped` gesetzt
- `state.cover_position` bleibt `35`
- `state.cover_calibrated` bleibt `true`
- fehlende Cover-Felder loeschen nichts

### Partieller State

```powershell
Publish-ServerMqtt -Topic "smarthome/device/net_erl_hall_module/state" -Retain -Payload '{"device_id":"net_erl_hall_module","motion":false}'
```

Erwartung:

- `state.motion` wird auf `false` gesetzt
- `state.relay_1` bleibt `true`
- `state.lux` bleibt `120`
- fehlende Felder loeschen nichts
- SQLite loescht die vorherigen `device_state_latest`-Werte ebenfalls nicht

## Event prüfen

```powershell
Publish-ServerMqtt -Topic "smarthome/device/net_erl_hall_module/event" -Payload '{"device_id":"net_erl_hall_module","event":"motion_detected","event_type":2,"trigger":1,"param1":0,"param2":0}'
```

Erwartung:

- `last_event.event_type = 2`
- `last_event.event_label = motion_detected`
- `last_event.event_trigger = 1`
- normaler `state` bleibt unveraendert
- `device_event_log` bekommt einen neuen Eintrag
- `device_state_latest.last_event_*` wird mitgezogen

## ACK prüfen

```powershell
Publish-ServerMqtt -Topic "smarthome/device/net_erl_hall_module/ack" -Payload '{"device_id":"net_erl_hall_module","request_id":"req-1","channel":"command","status":"ok","status_code":0,"ack_msg_type":5,"ack_seq":17,"source":"node_ack"}'
```

Erwartung:

- `last_ack.request_id = req-1`
- `last_ack.channel = command`
- `last_ack.status = ok`
- `last_ack.source = node_ack`
- normaler `state` bleibt unveraendert
- `device_ack_log` bekommt einen neuen Eintrag
- `device_state_latest.last_ack_*` wird mitgezogen

## Minimalen Command-/ACK-Pfad pruefen

Fuer den echten Master-/Hardware-Roundtrip den vorhandenen realen Node `net_erl_01` verwenden.
Der Platzhalter `net_erl_hall_module` taugt fuer den serverseitigen Ingest-Aufbau, aber nicht als belastbarer Hardware-Nachweis.

In einem zweiten Terminal vor dem HTTP-Aufruf den offiziellen Command-Capture starten:

```powershell
docker compose -f server/docker-compose.yml exec -T mosquitto mosquitto_sub -h localhost -t smarthome/device/net_erl_01/command -C 1 -v
```

Dann den engen Server-Einstieg aufrufen:

```powershell
curl.exe -s -X POST http://localhost:1880/api/phase1/net-erl/relay-1 -H "Content-Type: application/json" -d "{\"device_id\":\"net_erl_01\",\"relay_1\":true}"
```

Erwartung:

- HTTP antwortet mit `202`
- die Antwort enthaelt `device_id`, `request_id`, `command = set_relay`, `relay_1 = true`
- MQTT zeigt genau einen Publish auf `smarthome/device/net_erl_01/command`
- der publizierte Payload enthaelt dieselbe `request_id`

Mit derselben `request_id` den ACK-Rueckweg pruefen:

```powershell
Publish-ServerMqtt -Topic "smarthome/device/net_erl_01/ack" -Payload '{"device_id":"net_erl_01","request_id":"<request_id_aus_http>","channel":"command","status":"ok","status_code":"0","ack_msg_type":"5","ack_seq":"1"}'
```

Optional den sichtbaren Zielzustand nachziehen:

```powershell
Publish-ServerMqtt -Topic "smarthome/device/net_erl_01/state" -Retain -Payload '{"device_id":"net_erl_01","relay_1":true}'
```

Erwartung:

- `device_ack_log` bekommt einen neuen Eintrag mit derselben `request_id`
- `device_state_latest.last_ack_request_id` entspricht der HTTP-Antwort
- `device_state_latest.last_ack_channel = command`
- `device_state_latest.relay_1 = true`, wenn der optionale State-Nachtrag gefahren wurde

## Minimalen Cover-Command-Pfad pruefen

Fuer den Cover-Command-Pfad einen bekannten Cover-Node verwenden, zum Beispiel `NET-ZRL-001`.

In einem zweiten Terminal vor dem HTTP-Aufruf den offiziellen Command-Capture starten:

```powershell
docker compose -f server/docker-compose.yml exec -T mosquitto mosquitto_sub -h localhost -t smarthome/device/NET-ZRL-001/command -C 1 -v
```

Dann den engen Cover-Einstieg aufrufen:

```powershell
curl.exe -s -X POST http://localhost:1880/api/phase1/cover/command -H "Content-Type: application/json" -d "{\"device_id\":\"NET-ZRL-001\",\"command\":\"open\"}"
```

Erwartung:

- HTTP antwortet mit `202`
- die Antwort enthaelt `device_id`, `request_id`, `command = open`
- MQTT zeigt genau einen Publish auf `smarthome/device/NET-ZRL-001/command`
- der publizierte Payload enthaelt dieselbe `request_id`

Fuer Prozentanfahrt:

```powershell
curl.exe -s -X POST http://localhost:1880/api/phase1/cover/command -H "Content-Type: application/json" -d "{\"device_id\":\"NET-ZRL-001\",\"command\":\"set_position\",\"position\":42}"
```

Erwartung:

- HTTP antwortet mit `202`, wenn der letzte bekannte State `cover_calibrated = true` ist
- HTTP antwortet mit `409`, wenn der letzte bekannte State `cover_calibrated = false` ist
- MQTT enthaelt bei Erfolg `{\"command\":\"set_position\",\"position\":42,...}`

## Master separat prüfen

### Masterstatus

```powershell
Publish-ServerMqtt -Topic "smarthome/master/master_1/status" -Retain -Payload '{"master_id":"master_1","online":true,"wifi":true,"mqtt":true,"espnow":true,"fw":"0.1.0"}'
```

### Masterevent

```powershell
Publish-ServerMqtt -Topic "smarthome/master/master_1/event" -Payload '{"master_id":"master_1","event":"mqtt_connected","message":"broker online","fw":"0.1.0"}'
```

Erwartung:

- Masterdaten landen nicht im normalen `devices`-Objekt
- `master_1` fuehrt einen separaten Statusblock
- `master_1` fuehrt einen separaten letzten Eventblock
- `master_status` enthaelt den letzten Status
- `master_event_log` bekommt einen neuen Eintrag

## SQLite-Inhalt stichprobenartig pruefen

Ein kurzer Spot-Check im `nodered`-Container reicht:

```powershell
$SqliteSpotCheck = @'
const sqlite3 = require('/data/node_modules/sqlite3');
const db = new sqlite3.Database('/config/sqlite/smarthome_phase1.db');
const queries = [
  "select device_id, device_name from devices order by device_id",
  "select device_id, online, relay_1, motion, lux, cover_state, cover_position, cover_calibrated, button_flags, last_ack_source from device_state_latest order by device_id",
  "select device_id, event_type, event_label, event_trigger from device_event_log order by id desc limit 3",
  "select device_id, request_id, status, source from device_ack_log order by id desc limit 3",
  "select master_id, online, wifi, mqtt, espnow from master_status order by master_id",
  "select master_id, event, message from master_event_log order by id desc limit 3"
];
function all(sql) {
  return new Promise((resolve, reject) => {
    db.all(sql, (error, rows) => error ? reject(error) : resolve(rows || []));
  });
}
(async () => {
  for (const sql of queries) {
    console.log("\nSQL>", sql);
    console.log(JSON.stringify(await all(sql), null, 2));
  }
})().finally(() => db.close());
'@
docker compose -f server/docker-compose.yml exec -T nodered node -e $SqliteSpotCheck
```

## Abschluss

Erfolgreich ist Phase 1 nur dann, wenn alle Punkte gleichzeitig stimmen:

- Geraete werden robust auto-angelegt
- `meta`, `availability`, `state`, `event` und `ack` landen in den richtigen Bloecken
- partielle State-Updates zerstoeren keine vorhandenen Werte
- der Master bleibt komplett getrennt
- die SQLite-Writes kommen aus derselben zentralen Handlerkette
- die aktiven Flows enthalten keine zweite fachliche Logikbasis mehr

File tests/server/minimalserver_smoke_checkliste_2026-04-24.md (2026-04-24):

# Minimalserver Smoke-Checkliste

## Ziel

Diese Checkliste dient zur lokalen Prüfung des aktuellen Minimalserver-Stands nach dem Rückbau auf Snapshot-Persistenz ohne InfluxDB, Zeitreihen und Verlaufslogik.

Der Test soll bestätigen, dass der reduzierte Server weiterhin die Kernfunktionen sauber erfüllt.

## Kernfragen

Der Lauf gilt nur dann als erfolgreich, wenn der Server weiterhin:

- sauber startet
- Geräte sauber anzeigt
- aktuelle Sensordaten sauber anzeigt
- Online-/Offline-Status sauber anzeigt
- Batterieanzeige sauber darstellt
- Aktoren schaltbar macht
- Rolladenfunktionen abhängig vom Kalibrierstatus korrekt behandelt
- den aktuellen Snapshot in SQLite sauber fortschreibt
- keine InfluxDB mehr benötigt

---

## 1. Stack-Start prüfen

### Schritte
1. In den Ordner `server/` wechseln
2. `docker compose up -d` ausführen
3. `docker compose ps` prüfen

### Soll
- Mosquitto läuft
- Node-RED läuft
- kein InfluxDB-Dienst mehr vorhanden
- keine offensichtlichen Compose- oder Startfehler

---

## 2. Node-RED-Start prüfen

### Schritte
1. Node-RED im Browser öffnen
2. auf erkennbare Startfehler achten
3. falls nötig Logs prüfen

### Soll
- Node-RED startet sauber
- aktive Flows sind geladen
- keine offensichtlichen Fehler durch entfernte Historien- oder Influx-Pfade

---

## 3. Server-Contract-Smoke-Test ausführen

### Schritte
1. Aus dem Repo-Root den vorhandenen Smoke-Test starten
2. falls der Stack bereits läuft, die passende Skip-Start-Variante nutzen

### Soll
- Test läuft ohne harte Fehler durch
- keine SQL-/Migrationsfehler
- kein Verweis auf Influx-Abhängigkeit
- Snapshot-/Vertragslogik bleibt intakt

---

## 4. Geräteübersicht prüfen

### Schritte
1. Dashboard-Übersicht öffnen
2. bekannte Geräte kontrollieren

### Soll
- Geräte erscheinen weiterhin
- Anzeigenamen sind vorhanden
- Online-/Offline-Zustand wirkt plausibel
- letzte Aktualisierung wirkt plausibel
- Sensorkacheln / Zustände wirken nicht leer oder beschädigt

---

## 5. Gerätedetailseite prüfen

### Schritte
1. mindestens ein Sensorgerät öffnen
2. mindestens ein Aktorgerät öffnen
3. wenn vorhanden, Rolladengerät öffnen

### Soll
- Detailseite lädt sauber
- relevante aktuelle Werte werden angezeigt
- Batterieanzeige ist sichtbar, falls Batteriegerät
- keine offensichtlichen UI-Reste aus alter Verlaufslogik

---

## 6. Snapshot in SQLite prüfen

### Schritte
1. SQLite-Datei prüfen
2. kontrollieren, ob aktuelle Zustände fortgeschrieben werden
3. prüfen, ob nur der aktuelle Snapshot relevant ist

### Soll
- `devices`, `device_state_latest`, `master_status` wirken plausibel
- keine Erwartung mehr an InfluxDB oder Zeitreihenhaltung
- aktuelle Werte und Zeitbezüge werden sauber aktualisiert

---

## 7. Aktorsteuerung prüfen

### Schritte
1. Relaisfunktion testweise schalten
2. ACK-/Statusrücklauf prüfen
3. UI-Verhalten prüfen

### Soll
- Command wird angenommen
- ACK/Status kommt sauber zurück
- UI zeigt den aktuellen Zustand plausibel
- keine offensichtliche Abhängigkeit von alter Verlaufsspeicherung

---

## 8. Rolladenlogik prüfen

### Schritte
1. Rolladengerät öffnen
2. Kalibrierstatus beachten
3. Bedienbarkeit gegen den Gerätezustand prüfen

### Soll
- unkalibrierte Geräte erlauben keine unpassenden Positionsfunktionen
- kalibrierte Geräte verhalten sich passend zum aktuellen Zustand
- keine unlogische Freigabe nur wegen alter UI-Reste

---

## 9. Neustartfestigkeit grob prüfen

### Schritte
1. Stack neu starten
2. Dashboard erneut prüfen

### Soll
- Geräte bleiben bekannt
- Anzeigenamen bleiben erhalten
- letzter Snapshot bleibt plausibel erhalten
- keine Influx-bezogene Wiederanlaufabhängigkeit

---

## Bewertung

Der Smoke-Test ist erfolgreich, wenn der reduzierte Server als Snapshot-, Anzeige- und Steuerkern stabil arbeitet, ohne für Kernfunktionen noch auf Historien- oder Influx-Pfade angewiesen zu sein.

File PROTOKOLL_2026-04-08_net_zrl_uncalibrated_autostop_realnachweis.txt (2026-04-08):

PROTOKOLL 2026-04-08 - NET-ZRL unkalibrierter Auto-Stopp Realnachweis

Datum: 2026-04-08
Ziel: den noch offenen echten Nachweis sauber erbringen, dass normale Fahrten des realen `NET-ZRL` im unkalibrierten Zustand nicht endlos laufen, sondern nach der wirksamen `default_estimated_travel_time_ms` selbststaendig stoppen

1. Ausgangslage
- Arbeitsrepo: aktueller Stand von `smarthome-technikerprojekt`
- reales Geraet:
  - `NET-ZRL` auf `COM6`
- der Firmware-Fix fuer unkalibrierten Auto-Stopp war bereits implementiert, gebaut und zuvor auf `COM6` geflasht
- offener Punkt war nur noch der echte reale Nachweis am Geraet

2. Relevante Soll-Logik im Code
Betroffen:
- `firmware/src/basetypes/net_zrl/main.cpp`

Relevante Stellen:
- `starteNormaleFahrtNachOben(...)`
- `starteNormaleFahrtNachUnten(...)`
- `verarbeiteBewegungsTimeouts()`

Fachlich wirksame Logik:
- wenn `runtime.isCalibrated == true`, wird die normale Fahrt ueber `travelTimeUpMs` bzw. `travelTimeDownMs` begrenzt
- wenn `runtime.isCalibrated == false`, wird die normale Fahrt ueber `runtime.defaultEstimatedTravelTimeMs` begrenzt
- bei Erreichen der Deadline wird `stoppeFahrt("fahrzeit erreicht")` ausgefuehrt

3. Vorgehen fuer den Realnachweis
Der Nachweis wurde ueber den echten seriellen Zugriff auf `COM6` mit hostseitig gestempeltem Log gefahren.

Warum so:
- der unkalibrierte Zustand laesst sich direkt am realen Geraet belegen
- Start und Ende der Fahrt sind ueber echte Geraetelogs sichtbar
- der Auto-Stopp wird direkt durch den echten Firmwarepfad belegt

Wichtig:
- fuer den Nachweis wurde die wirksame `default_estimated_travel_time_ms` im Setup-Modus temporaer von `100000` ms auf `5000` ms gesetzt
- das war kein Feature-Eingriff, sondern eine Testkonfiguration, damit der Realnachweis in kurzer Zeit sauber beobachtbar ist
- nach dem Nachweis wurde der Wert wieder auf `100000` ms zurueckgesetzt

4. Teil A - realen Ausgangszustand gesichert

4.1 Vor dem Test
Serieller Status vor der Testfahrt:
- `state=stopped`
- `is_calibrated=false`
- `travel_time_up_ms=0`
- `travel_time_down_ms=0`
- `default_estimated_travel_time_ms=100000`

Beleg aus dem echten Seriellog:
- `2026-04-08 20:23:52.328 state=stopped ... is_calibrated=false ... travel_time_up_ms=0 travel_time_down_ms=0 default_estimated_travel_time_ms=100000 ...`

Bewertung:
- das reale Geraet war vor dem Test nachweisbar unkalibriert
- die urspruenglich wirksame Default-Fahrzeit war real mit `100000` ms sichtbar

4.2 Testkonfiguration fuer beobachtbaren Realnachweis
Im Setup-Modus real ausgefuehrt:
- `setup reset_calibration`
- `setup set default_ms 5000`

Danach erneut real belegt:
- `is_calibrated=false`
- `travel_time_up_ms=0`
- `travel_time_down_ms=0`
- `default_estimated_travel_time_ms=5000`

Beleg aus dem echten Seriellog:
- `2026-04-08 20:24:00.040 state=stopped ... is_calibrated=false ... travel_time_up_ms=0 travel_time_down_ms=0 default_estimated_travel_time_ms=5000 ...`

Bewertung:
- der unkalibrierte Zustand blieb erhalten
- die fuer den Test wirksame Default-Fahrzeit war real auf `5000` ms gesetzt und im Geraetelog sichtbar

5. Teil B - echter Auto-Stopp-Nachweis

5.1 Richtung `up`
Realer Start:
- serieller Befehl: `up`
- Geraetelog: `2026-04-08 20:24:01.453 [INFO] Relais fuer up aktiv (serieller up)`

Realer Auto-Stopp:
- Geraetelog: `2026-04-08 20:24:06.299 [INFO] Relais neutral (fahrzeit erreicht)`

Realer Zustand danach:
- `2026-04-08 20:24:10.673 state=stopped ... is_calibrated=false ... default_estimated_travel_time_ms=5000 ...`

Bewertung:
- die normale Fahrt wurde real gestartet
- das Geraet blieb unkalibriert
- die Fahrt lief nicht endlos
- der Auto-Stopp griff selbststaendig nach der wirksamen Default-Fahrzeit von ca. 5 s

5.2 Richtung `down`
Realer Start:
- serieller Befehl: `down`
- Geraetelog: `2026-04-08 20:24:30.684 [INFO] Relais fuer down aktiv (serieller down)`

Realer Auto-Stopp:
- Geraetelog: `2026-04-08 20:24:35.536 [INFO] Relais neutral (fahrzeit erreicht)`

Realer Zustand danach:
- `2026-04-08 20:24:39.866 state=stopped ... is_calibrated=false ... default_estimated_travel_time_ms=5000 ...`

Bewertung:
- auch die Gegenrichtung wurde real gestartet
- auch hier blieb das Geraet unkalibriert
- auch hier lief die Fahrt nicht endlos
- auch hier griff der Auto-Stopp selbststaendig nach der wirksamen Default-Fahrzeit von ca. 5 s

6. Teil C - Fehlerregel
- in diesem Lauf trat kein Bruch mehr auf
- ein weiterer Fix war nicht noetig
- Build und Reflash waren fuer diesen Lauf nicht erneut noetig, weil der reale Test mit der bereits geflashten Fix-Firmware positiv war

7. Rueckbau der Testkonfiguration
Nach dem Nachweis real ausgefuehrt:
- `setup set default_ms 100000`

Danach real belegt:
- `2026-04-08 20:25:03.085 state=stopped ... is_calibrated=false ... travel_time_up_ms=0 travel_time_down_ms=0 default_estimated_travel_time_ms=100000 ...`

Bewertung:
- das reale Geraet wurde nach dem Test wieder auf die urspruengliche Default-Fahrzeit zurueckgesetzt
- der unkalibrierte Zustand blieb bewusst bestehen

8. Ergebnis
Der offene reale Nachweis ist jetzt erbracht.

Real belegt ist:
- `NET-ZRL` war waehrend des Tests unkalibriert
- normale Fahrten `up` und `down` wurden real gestartet
- die Fahrt lief in keiner Richtung endlos
- der Auto-Stopp griff in beiden Richtungen selbststaendig mit `fahrzeit erreicht`
- damit ist fachlich belegt, dass der Fix fuer den unkalibrierten Auto-Stopp auf dem realen Geraet wirksam ist

9. Dateien in diesem Lauf
- neu:
  - `PROTOKOLL_2026-04-08_net_zrl_uncalibrated_autostop_realnachweis.txt`

10. Commit-Status
- in diesem Protokollschritt noch kein Commit

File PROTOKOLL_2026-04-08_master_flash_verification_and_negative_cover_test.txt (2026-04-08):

PROTOKOLL 2026-04-08 – Master-Flashstand verifizieren und negativer Cover-Test

Datum: 2026-04-08
Bezug: echter Nachlauf nach dem Cover-Realtest mit Fokus auf Master-Flashstand und negativem set_position-Fall
Ziel: den realen Master-Flashstand belastbar verifizieren und den offenen Negativfall fuer Cover sauber ueber den offiziellen Serverpfad belegen

1. Ausgangslage
- Arbeitsrepo: aktueller `main`-Stand von `smarthome-technikerprojekt`
- reale Hardware vorhanden:
  - `master` auf `COM3`
  - `net_zrl` auf `COM6`
- Server-Stack aktiv:
  - Node-RED auf `http://localhost:1880`
  - Mosquitto auf `localhost:1883`

2. Reale Feststellung vor dem Reflash
- der laufende Master publizierte live auf `smarthome/master/MASTER-001/status`:
  - `fw="0.2.2"`
- gleichzeitig trugen mehrere Quelldateien im Master bereits interne Stand-Markierungen `0.4.0`

3. Wichtiger Befund zur Ursache
Der Widerspruch war nicht primaer ein Flashproblem, sondern ein Versionsquellenproblem im Repo:
- `firmware/src/basetypes/master/main.cpp` trug weiterhin `0.4.0` als Dateistand
- die zentrale Versionsquelle `firmware/include/ProjectVersion.h` stand aber noch auf:
  - `PROJECT_VERSION = "0.2.2"`
  - `PROJECT_VERSION_DATE = "2026-03-10"`

Damit war die bisherige Annahme "realer Master laeuft nicht auf aktuellem Stand" zu ungenau.
Der reale Master konnte durchaus frisch geflasht sein und trotzdem wegen der zentralen Projektversion weiter `0.2.2` publizieren.

4. Korrektur im Repo
Gezielt geaendert wurde:
- `firmware/include/ProjectVersion.h`

Korrektur:
- `PROJECT_VERSION` von `0.2.2` auf `0.4.0`
- `PROJECT_VERSION_DATE` von `2026-03-10` auf `2026-04-08`

Keine weiteren Architektur- oder Featureaenderungen in diesem Teil.

5. Rebuild und echter Reflash des Masters
Erfolgreich ausgefuehrt:
- `pio run -e master`
- `pio run -e master -t upload --upload-port COM3`

Ergebnis:
- Build erfolgreich
- Upload auf das reale Master-Board auf `COM3` erfolgreich
- USB-MAC des realen Masters waehrend des Flashs:
  - `20:6e:f1:6d:92:c0`

6. Reale Live-Verifikation nach dem Reflash
Nach dem Reflash und Reconnect publizierte der Master live:
- Topic: `smarthome/master/MASTER-001/status`
- Payload:
  - `{"master_id":"MASTER-001","online":true,"wifi":true,"mqtt":true,"espnow":true,"fw":"0.4.0"}`

Bewertung:
- der reale Master laeuft jetzt nachweisbar mit dem korrigiert gekennzeichneten aktuellen Source-Stand
- ein erneuter Flash war in diesem Lauf sinnvoll und wurde real ausgefuehrt

7. Vorbereitung des negativen Cover-Tests
Danach wurde auf den Live-State des realen `NET-ZRL-001` geprueft.

Realer State vor dem Test:
- Topic: `smarthome/device/NET-ZRL-001/state`
- Payload:
  - `{"device_id":"NET-ZRL-001","relay_1":false,"relay_2":false,"cover_mode":true,"cover_state":"stopped","cover_calibrated":false,"fault":false}`

Wichtig:
- `cover_calibrated=false` war live sichtbar
- `cover_position` wurde im unkalibrierten Zustand nicht publiziert

8. Negativer Realtest: set_position bei cover_calibrated=false
Offizieller Server-Einstieg:
- `POST /api/phase1/cover/command`

Gesendeter Request:
- `{"device_id":"NET-ZRL-001","command":"set_position","position":30}`

8.1 HTTP-Antwort
Der Server antwortete real mit:
- HTTP `409 Conflict`
- Body:
  - `{"error":"not_calibrated","message":"set_position requires a calibrated cover"}`

Bewertung:
- der offizielle Serverpfad blockiert den unkalibrierten Prozentbefehl bereits korrekt auf oberer Ebene

8.2 MQTT-Command
Parallel wurde auf `smarthome/device/NET-ZRL-001/command` mit Capture gewartet.

Ergebnis:
- kein MQTT-Command publiziert
- der Command-Capture lief in den Timeout

Bewertung:
- der ungueltige `set_position`-Befehl wurde nicht an den Master und nicht an den Node durchgereicht

8.3 ACK / Ablehnung
Parallel wurde auf `smarthome/device/NET-ZRL-001/ack` gewartet.

Ergebnis:
- kein ACK publiziert
- der ACK-Capture lief in den Timeout

Bewertung:
- die Ablehnung erfolgt in diesem Pfad serverseitig vor der MQTT-Weitergabe
- entsprechend entsteht kein geraeteseitiger ACK-Rueckweg

8.4 State-Verhalten
Nach dem Negativtest blieb der reale Geraetezustand fachlich unveraendert:
- `cover_state` blieb `stopped`
- `cover_calibrated` blieb `false`
- es wurde keine unpassende Fahrt ausgeloest

9. Ergebnis
Teil A:
- der reale Master-Flash wurde in diesem Lauf erneut ausgefuehrt
- die Live-Version ist jetzt korrekt als `0.4.0` verifiziert
- die eigentliche Fehlerursache war ein inkonsistentes zentrales Versionslabel im Repo

Teil B:
- der negative Realfall `set_position` bei `cover_calibrated=false` ist sauber belegt
- HTTP blockiert korrekt mit `409 not_calibrated`
- kein MQTT-Command
- kein ACK
- kein unpassender Statewechsel
- kein Fahrbefehl wurde durchgelassen

10. Dateien in diesem Lauf
- geaendert:
  - `firmware/include/ProjectVersion.h`
- neu angelegt:
  - `PROTOKOLL_2026-04-08_master_flash_verification_and_negative_cover_test.txt`

11. Commit-Status
- in diesem Teil des Laufs noch kein Commit erfolgt
- Commit soll spaeter gesammelt mit den weiteren direkt anschliessenden Arbeiten erfolgen

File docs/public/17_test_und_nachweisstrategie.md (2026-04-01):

# Test- und Nachweisstrategie

## Ziel

Das System soll nicht nur funktional aufgebaut, sondern auch nachvollziehbar getestet und dokumentiert werden.

## Testbereiche

### Hardware
- Spannungsversorgung prüfen
- Ein- und Ausgänge prüfen
- Bestückung und Verdrahtung kontrollieren

### Kommunikation
- ESP-NOW zwischen Geräten und Master prüfen
- MQTT zwischen Master und Server prüfen
- Befehle vom Dashboard zu Aktoren prüfen

### Funktion
- Sensorwerte plausibel auslesen
- lokale Gerätefunktionen prüfen
- Aktorik gezielt ansteuern

### Stabilität
- mehrstündiger Dauerbetrieb
- Prüfung auf Wiederverbindung bei Kommunikationsverlust
- Prüfung definierter Fehlerfälle

## Nachweise

Für die offizielle Projektlinie werden Testergebnisse, Beobachtungen und wichtige Änderungen im Protokoll und in der Dokumentation festgehalten.

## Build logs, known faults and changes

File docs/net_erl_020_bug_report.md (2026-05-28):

---

## Anforderungskatalog (vom Betreiber)

### Zeitkritikalitaet
- **Relais (Lampe):** einziges zeitkritisches Element. LD2410-Radar-Out muss so oft
  gelesen werden, dass das Relais **innerhalb 1 Sekunde** nach Bewegung schaltet.
- **Sensorwerte:** unkritisch, 1x pro Minute ausreichend.
- **MQTT-Publish:** 1x pro Minute ausreichend.
- **CPU-Last:** Chip darf und soll entlastet werden (Single-Core ESP32-C3).

### Sensor-Datenqualitaet
- **Mittelwertbildung:** gleitender Mittelwert/Median aus 3 Messungen pro Sensor.
- **Kaltstart:** bei nur 1-2 Messungen wird der verfuegbare Wert gesendet (kein Blockieren).
- **Ziel:** Messwerte sollen ueber Zeit "immer besser werden" (Rauschen reduziert).

### Lampenlogik
- Geraet haengt an der Decke.
- Schaltet bei Bewegung, **wenn es im Raum nicht zu hell ist**.
- **Solange die Lampe AN ist, darf kein Lux-Wert gemessen werden**, da sonst das
  Lampenlicht den echten Raum-Lichtwert verfaelscht.
- Auto-Off-Nachlauf: 15 s nach letzter Bewegung.

### LED-Ring
- Aktiv bei Bewegungserkennung, **auch wenn Lampe nicht schaltet** (weil zu hell).
- Zeigt AQI / Temperatur / Feuchte als Komfortfunktion.
- 45 s Anzeigedauer (15 s pro Phase), dann aus.

### I2C-Bus-Strategie
- Bus ist instabil (2kO Pull-ups, 3 Sensoren).
- Messungen muessen **zeitlich verteilt** werden, um Bus-Last zu minimieren.
- Kein gleichzeitiges Pollen von BME680 + VEML7700 + ENS160 im selben Zyklus.
- ENS160-Kompensation nur schreiben wenn BME680 frische Werte hat.
- **Post-OTA I2C-Lockup:** akzeptierter Workaround (Power-Cycle).

### Bekannte Bugs (geloest)
1. Boot-Crash (AddressableLightEffect auf ESP32-C3/2026.5.1)
2. LED-Ring Phasen-Modulo fehlte
3. ENS160 Kompensation fehlte
4. Auto-On ohne Lux-Wert (5s Timeout)
5. 20-Minuten-Fault (ENS160-Warmup-Burst -> BUG-001)

### Offene Optimierungen
- Sensor-Mittelwertbildung (3-Wert gleitend)
- I2C-Messungen staffeln (Staggering)
- Lux-Messung aussetzen waehrend Lampe AN
- Poll-Intervalle reduzieren (60s statt 10s fuer Sensoren)
- MQTT-Publish-Rate auf 60s reduzieren
- LD2410-Poll auf 50ms halten (fuer <1s Reaktion)

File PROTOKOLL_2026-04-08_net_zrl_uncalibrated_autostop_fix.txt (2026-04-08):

PROTOKOLL 2026-04-08 – NET-ZRL Fix fuer unkalibrierten Auto-Stopp

Datum: 2026-04-08
Bezug: Fehleranalyse nach Beobachtung einer endlosen Fahrt im unkalibrierten Zustand
Ziel: die lokale Fahrlogik des `NET-ZRL` so korrigieren, dass normale Fahrten auch ohne Kalibrierung nach der konfigurierten Default-Fahrzeit automatisch stoppen

1. Beobachteter Fehler
- im unkalibrierten Zustand wurde getestet, ob der Rolladen die konfigurierte `default_estimated_travel_time_ms` als Sicherheitsgrenze nutzt
- reales Verhalten:
  - der Rolladen stoppte nicht
  - die Fahrt lief endlos weiter

2. Ursache im Code
Die Ursache lag nicht im Master und nicht im neutralen Serverpfad, sondern direkt in der lokalen `NET-ZRL`-Firmware.

Betroffen:
- `firmware/src/basetypes/net_zrl/main.cpp`

Relevante Logik:
- `starteNormaleFahrtNachOben(...)`
- `starteNormaleFahrtNachUnten(...)`

Fehlerhafte alte Linie:
- `autoStopMs` wurde nur gesetzt, wenn `runtime.isCalibrated == true`
- im unkalibrierten Zustand blieb `autoStopMs = 0`
- dadurch blieb `runtime.movementDeadlineAtMs = 0`
- `verarbeiteBewegungsTimeouts()` hatte damit keine wirksame Deadline und stoppte die Fahrt nicht

3. Korrektur
Die normale Fahrlogik wurde so erweitert:
- wenn kalibriert:
  - weiter wie bisher auf Basis von `travelTimeUpMs` bzw. `travelTimeDownMs`
- wenn nicht kalibriert:
  - Nutzung von `defaultEstimatedTravelTimeMs` als Auto-Stopp-Deadline

Konkret:
- `starteNormaleFahrtNachOben(...)` nutzt jetzt bei unkalibriertem Zustand `runtime.defaultEstimatedTravelTimeMs`
- `starteNormaleFahrtNachUnten(...)` nutzt jetzt bei unkalibriertem Zustand `runtime.defaultEstimatedTravelTimeMs`

4. Technische Bewertung
Das ist die fachlich richtige Stelle fuer den Fix:
- die Verantwortung liegt in der lokalen Geraetefirmware
- der neutrale Cover-Vertrag bleibt unveraendert
- `set_position` bleibt weiterhin nur bei Kalibrierung erlaubt
- einfache Fahrten `open` / `close` bekommen aber wieder eine echte Sicherheitsgrenze

5. Build und Flash
Erfolgreich ausgefuehrt:
- `pio run -e net_zrl`
- `pio run -e net_zrl -t upload --upload-port COM6`

Flash-Ergebnis:
- Upload auf das reale `NET-ZRL`-Board an `COM6` erfolgreich
- erkannte MAC waehrend des Flashs:
  - `8c:d0:b2:a8:80:bb`

6. Dateien
- geaendert:
  - `firmware/src/basetypes/net_zrl/main.cpp`
- neu:
  - `PROTOKOLL_2026-04-08_net_zrl_uncalibrated_autostop_fix.txt`

7. Commit-Status
- in diesem Schritt noch kein Commit
- Commit erfolgt gesammelt mit den direkt zusammenhaengenden Aenderungen dieses Laufs

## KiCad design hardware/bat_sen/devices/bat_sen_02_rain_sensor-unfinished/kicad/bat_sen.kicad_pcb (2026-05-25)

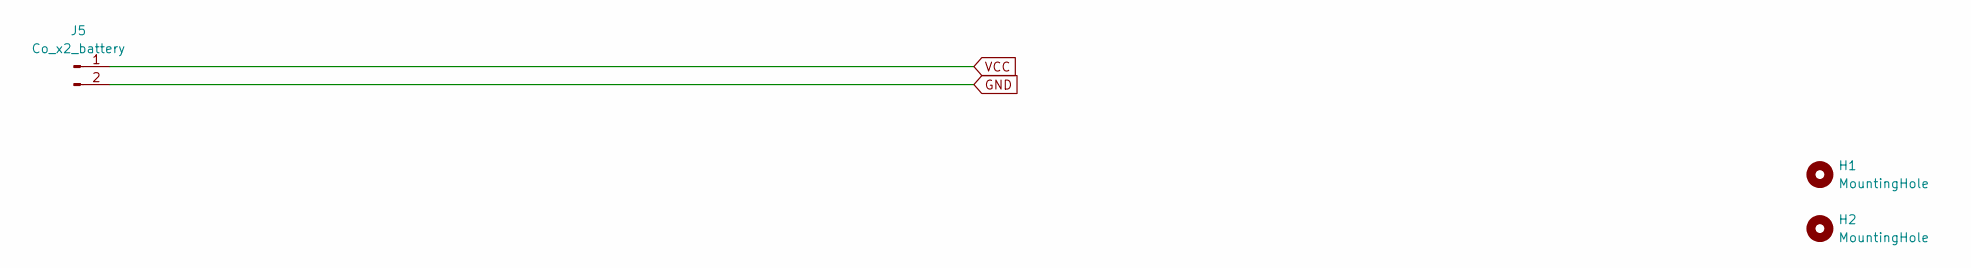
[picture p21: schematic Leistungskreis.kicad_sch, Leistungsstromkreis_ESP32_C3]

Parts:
H1, H2: MountingHole; MountingHole_3.2mm_M3_Pad
J5: Co_x2_battery; JST_PH_B2B-PH-K_1x02_P2.00mm_Vertical

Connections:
GND: J5.2; also elsewhere on the board
VCC: J5.1; also elsewhere on the board

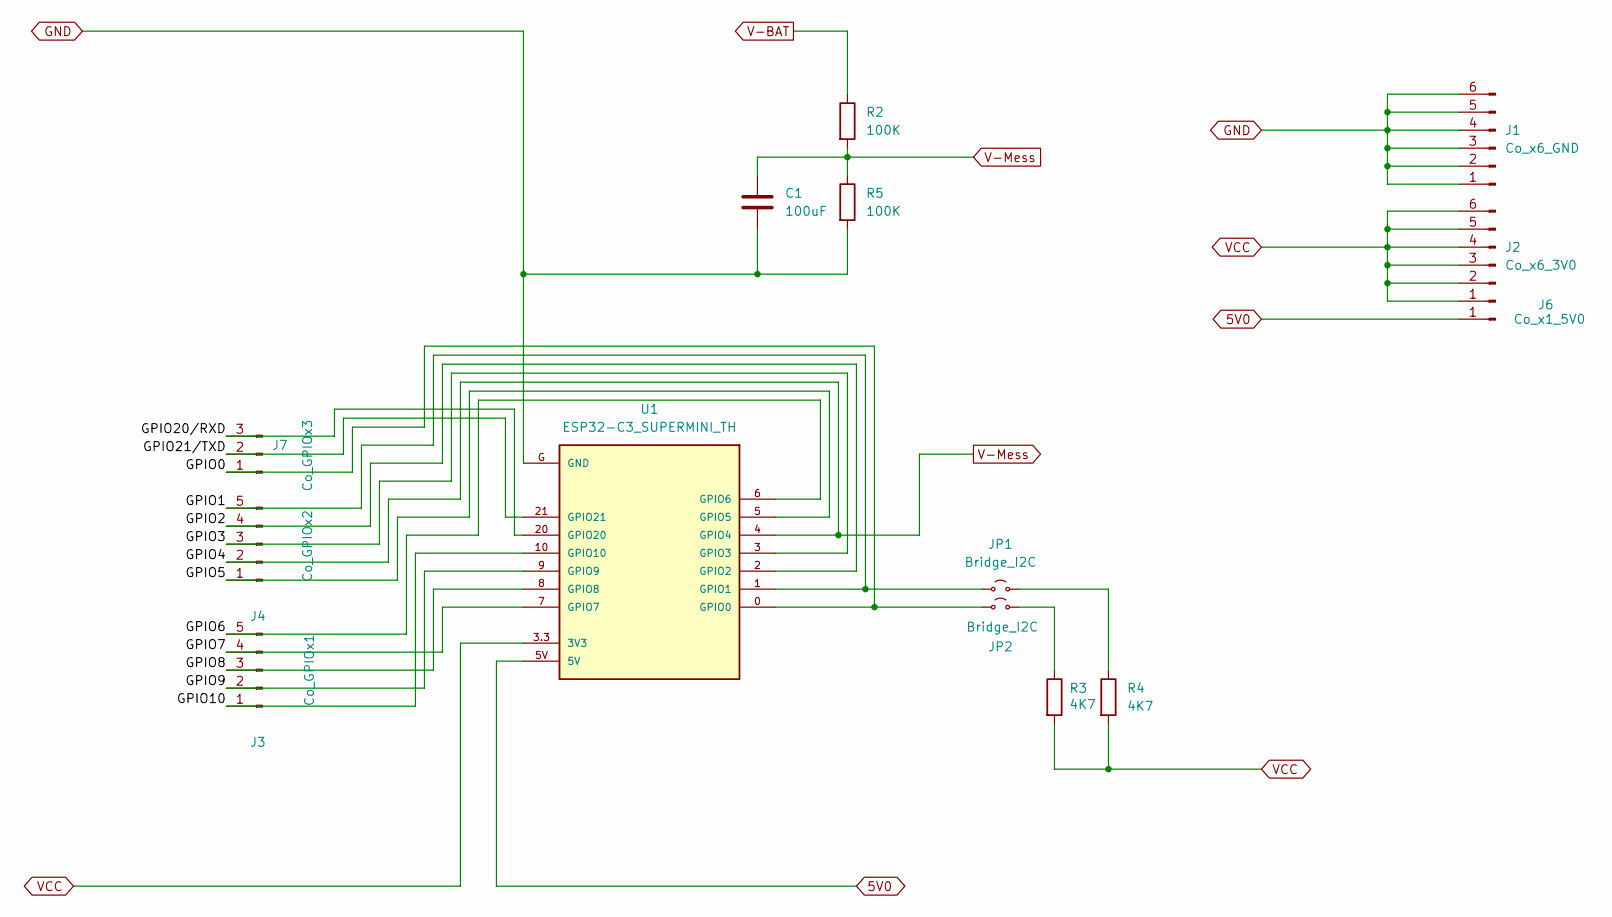
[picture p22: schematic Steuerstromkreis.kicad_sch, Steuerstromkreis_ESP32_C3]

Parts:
C1: 100uF; C_0603_1608Metric_Pad1.08x0.95mm_HandSolder
J1: Co_x6_GND; PinHeader_1x06_P2.54mm_Vertical
J2: Co_x6_3V0; PinHeader_1x06_P2.54mm_Vertical
J3: Co_GPIOx1; PinHeader_1x05_P2.54mm_Vertical
J4: Co_GPIOx2; PinHeader_1x05_P2.54mm_Vertical
J6: Co_x1_5V0; PinHeader_1x01_P2.54mm_Vertical
J7: Co_GPIOx3; PinHeader_1x03_P2.54mm_Vertical
JP1, JP2: Bridge_I2C; SolderJumper-2_P1.3mm_Open_Pad1.0x1.5mm
R2, R5: 100K; R_0603_1608Metric_Pad0.98x0.95mm_HandSolder
R3, R4: 4K7; R_0805_2012Metric_Pad1.20x1.40mm_HandSolder
U1: ESP32-C3_SUPERMINI_TH; MODULE_ESP32-C3_SUPERMINI_TH

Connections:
5V0: J6.1, U1.5V
/Steuerstromkreis/GPIO0: J7.1, JP2.1 (A), U1.0 (GPIO0)
/Steuerstromkreis/GPIO1: J4.5, JP1.1 (A), U1.1 (GPIO1)
/Steuerstromkreis/GPIO2: J4.4, U1.2 (GPIO2)
/Steuerstromkreis/GPIO3: J4.3, U1.3 (GPIO3)
/Steuerstromkreis/GPIO5: J4.1, U1.5 (GPIO5)
/Steuerstromkreis/GPIO6: J3.5, U1.6 (GPIO6)
/Steuerstromkreis/GPIO7: J3.4, U1.7 (GPIO7)
/Steuerstromkreis/GPIO8: J3.3, U1.8 (GPIO8)
/Steuerstromkreis/GPIO9: J3.2, U1.9 (GPIO9)
/Steuerstromkreis/GPIO10: J3.1, U1.10 (GPIO10)
/Steuerstromkreis/GPIO20/RXD: J7.3, U1.20 (GPIO20)
/Steuerstromkreis/GPIO21/TXD: J7.2, U1.21 (GPIO21)
GND: C1.1, J1.1, J1.2, J1.3, J1.4, J1.5, J1.6, R5.2, U1.G (GND); also elsewhere on the board
unnamed: JP1.2 (B), R4.1
unnamed: JP2.2 (B), R3.1
V-BAT: R2.1
V-Mess: C1.2, J4.2, R2.2, R5.1, U1.4 (GPIO4)
VCC: J2.1, J2.2, J2.3, J2.4, J2.5, J2.6, R3.2, R4.2, U1.3.3 (3V3); also elsewhere on the board

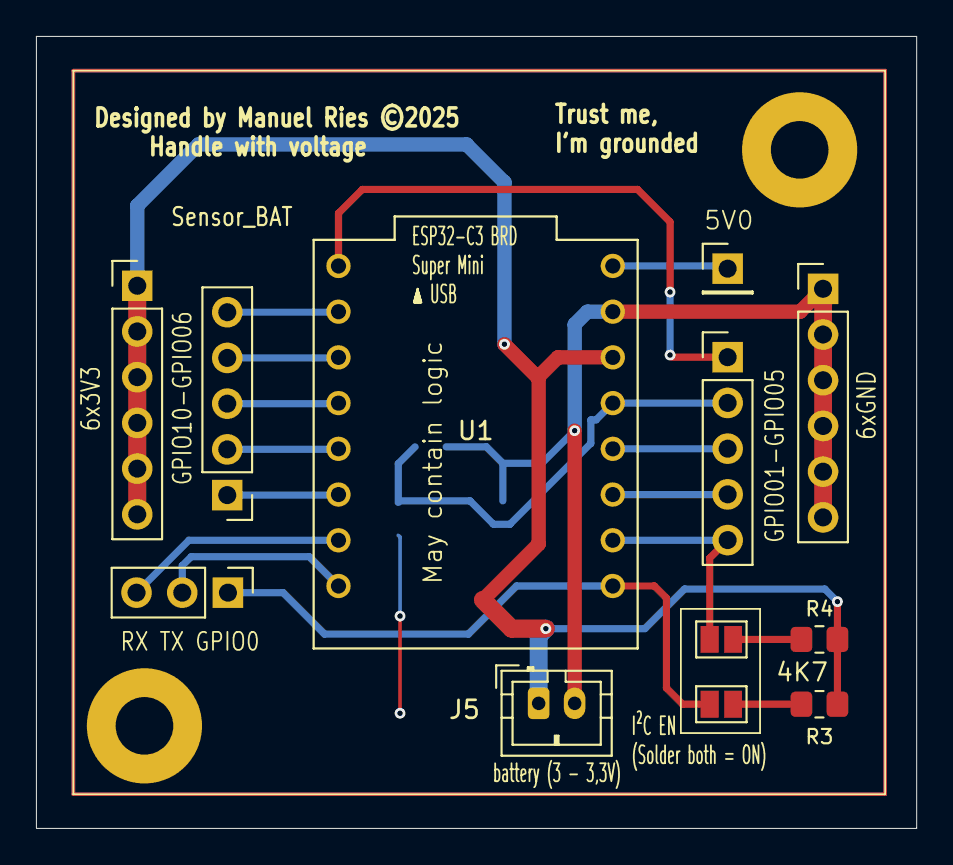
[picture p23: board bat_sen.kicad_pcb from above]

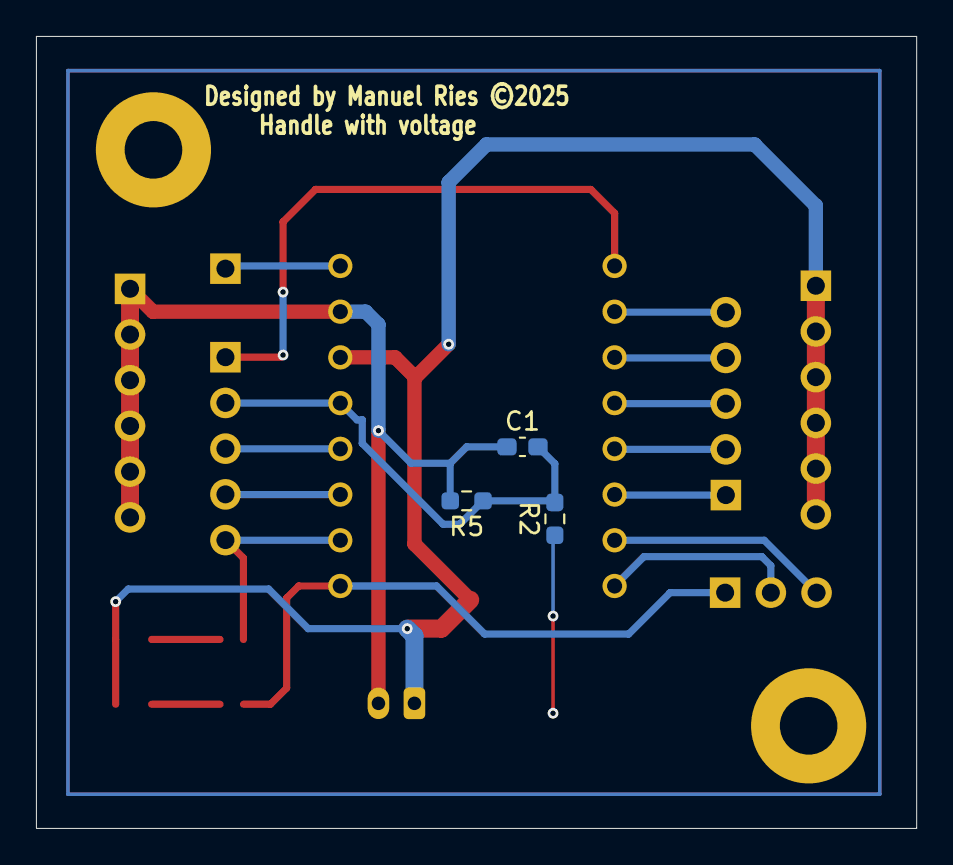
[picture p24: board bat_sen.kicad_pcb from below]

Board: 2 copper layers, 48.9 x 44.0 mm, 17 parts (3 on the bottom side), 18 nets.

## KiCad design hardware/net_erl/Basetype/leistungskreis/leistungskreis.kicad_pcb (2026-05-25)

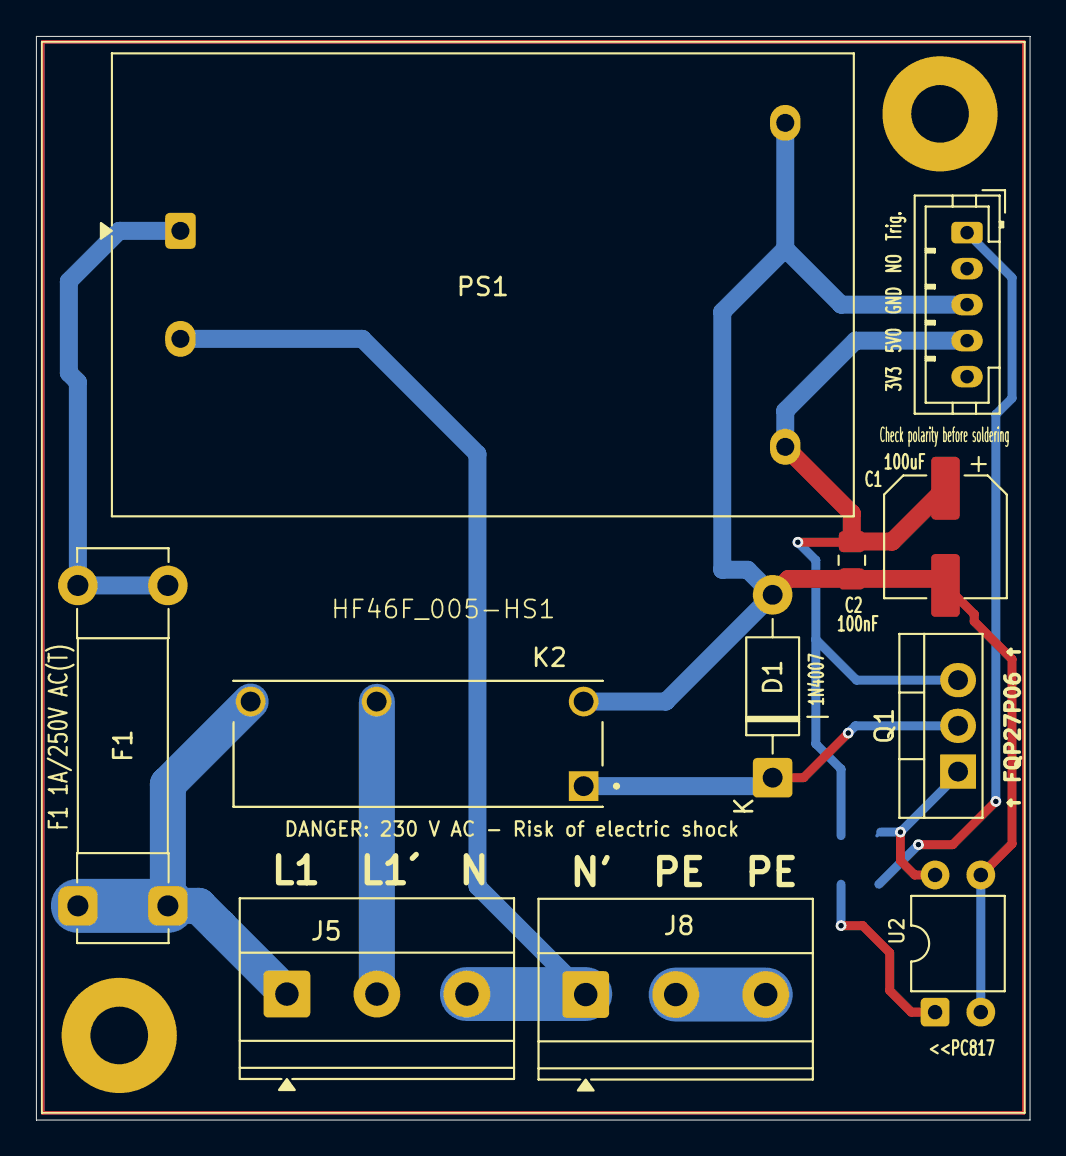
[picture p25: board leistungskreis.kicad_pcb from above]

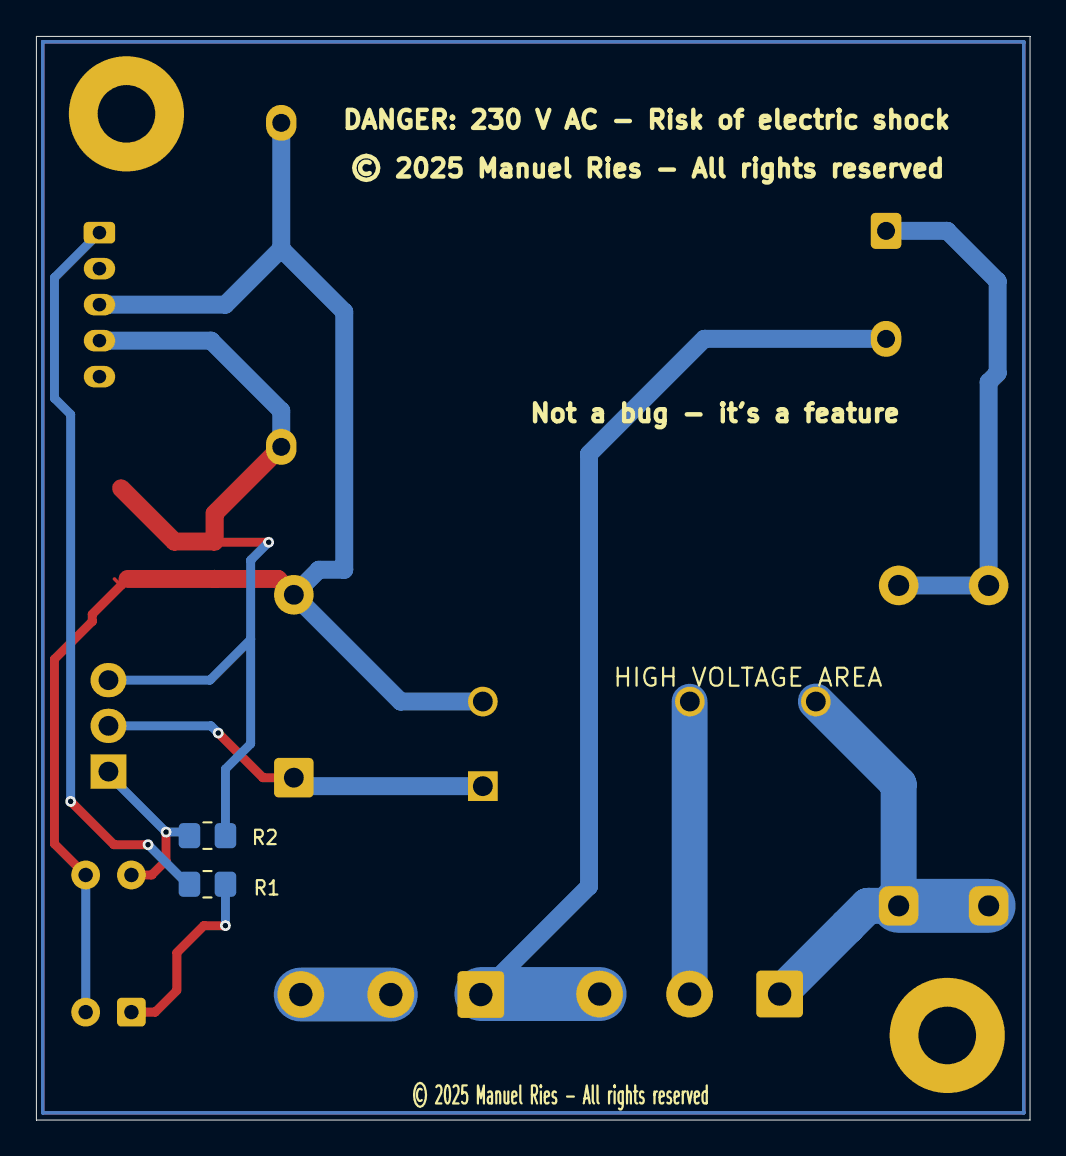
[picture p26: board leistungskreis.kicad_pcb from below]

Board: 2 copper layers, 55.2 x 60.2 mm, 15 parts (2 on the bottom side), 11 nets.

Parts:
C1: 100uF; CP_Elec_6.3x5.8
C2: 100nF; C_0805_2012Metric_Pad1.18x1.45mm_HandSolder
D1: 1N4007; D_DO-41_SOD81_P10.16mm_Horizontal
F1: Fuse; Fuseholder_Clip-5x20mm_Bel_FC-203-22_Lateral_P17.80x5.00mm_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
H1, H2: MountingHole; MountingHole_3.2mm_M3_Pad
J1: Co_5xV; JST_PH_B5B-PH-K_1x05_P2.00mm_Vertical
J5: Co_x3; TerminalBlock_Phoenix_MKDS-1,5-3_1x03_P5.00mm_Horizontal
J8: Co_x31; TerminalBlock_Phoenix_MKDS-1,5-3_1x03_P5.00mm_Horizontal
K2: HF46F_005-HS1; RELAY_HF46F_005-HS1
PS1: HLK-5M05; Converter_ACDC_Hi-Link_HLK-5Mxx
Q1: FQP27P06; TO-220-3_Vertical
R1: R330; R_0805_2012Metric_Pad1.20x1.40mm_HandSolder
R2: R100K; R_0805_2012Metric_Pad1.20x1.40mm_HandSolder
U2: PC817; DIP-4_W7.62mm

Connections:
5V0: C1.1, C2.1, J1.4, PS1.4 (+Vout), Q1.3 (S), R2.1
GND: C1.2, C2.2, D1.2 (A), J1.3, K2.2, PS1.3 (-Vout), U2.2, U2.3
GPIO10_Trigger_PIN1: J1.1, R1.1
L1 230VAC: F1.1, J5.1, K2.4
N: J5.3, J8.1, PS1.2 (AC/N)
unnamed: D1.1 (K), K2.1, Q1.2 (D)
unnamed: J5.2, K2.3
unnamed: F1.2, PS1.1 (AC/L)
unnamed: Q1.1 (G), R2.2, U2.4
unnamed: R1.2, U2.1
PE: J8.2, J8.3

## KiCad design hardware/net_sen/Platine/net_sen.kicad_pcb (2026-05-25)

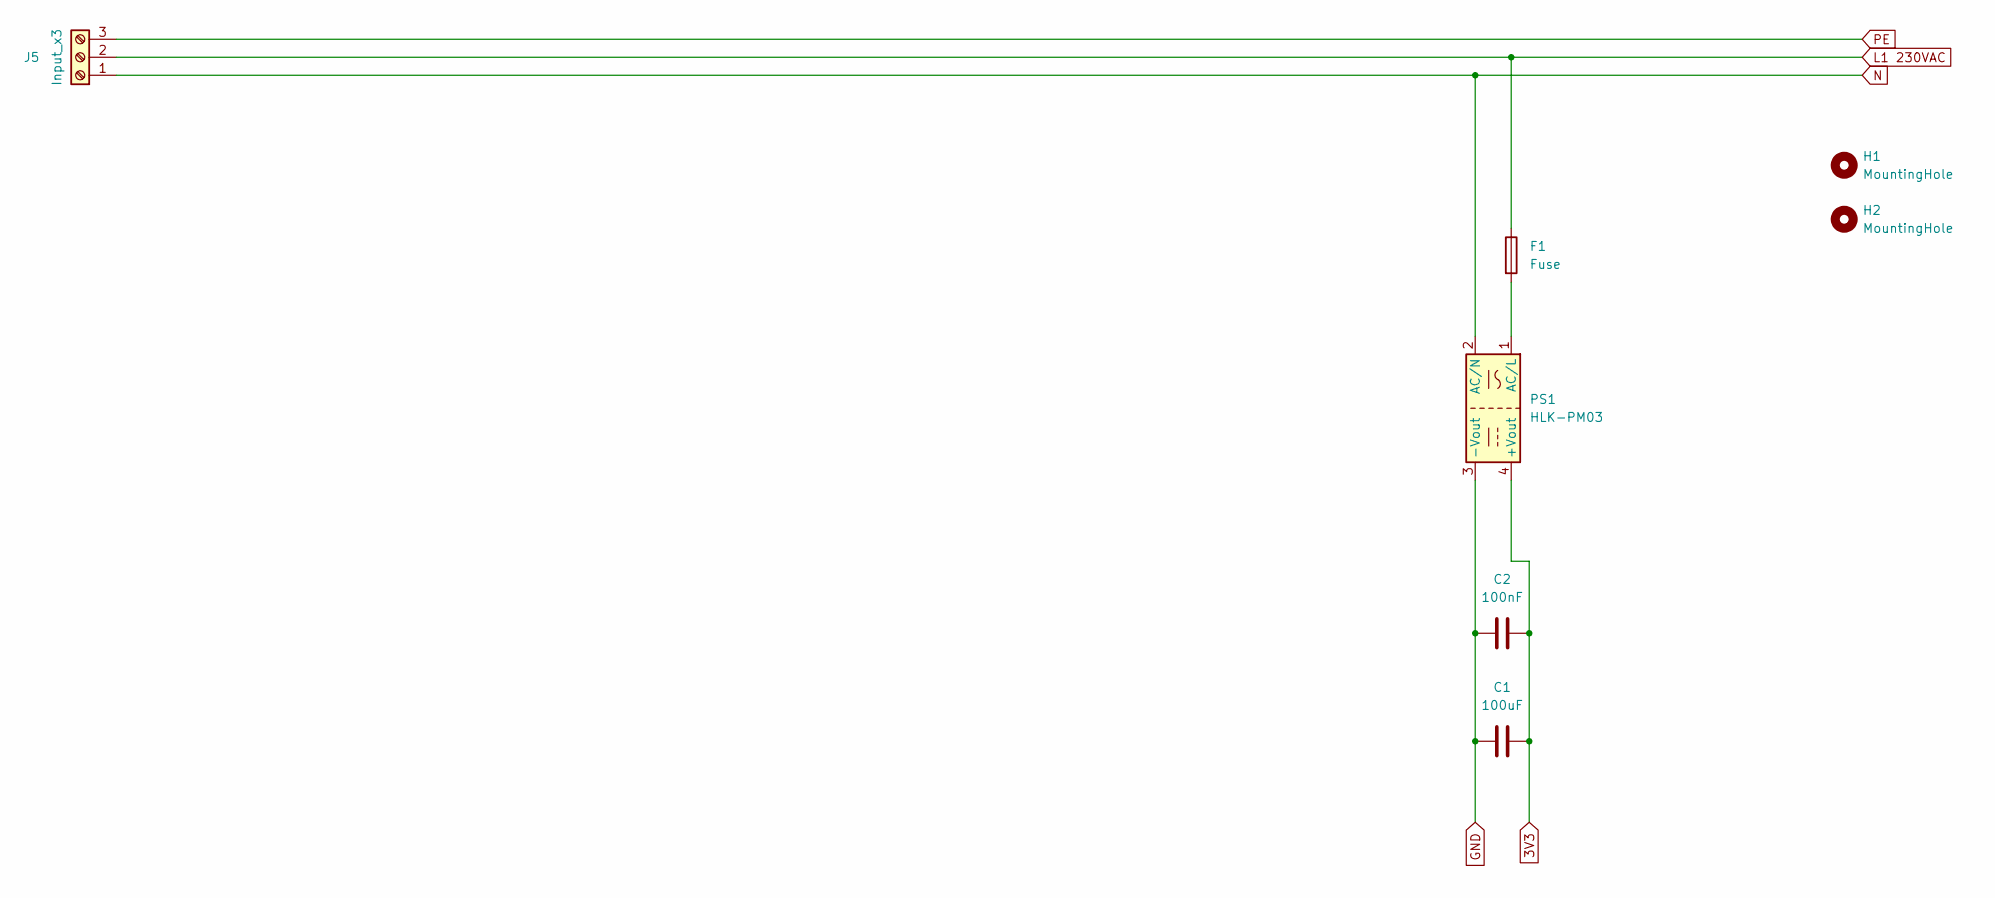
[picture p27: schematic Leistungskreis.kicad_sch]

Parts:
C1: 100uF; CP_Elec_6.3x5.8
C2: 100nF; C_0805_2012Metric_Pad1.18x1.45mm_HandSolder
F1: Fuse; Fuseholder_Clip-5x20mm_Bel_FC-203-22_Lateral_P17.80x5.00mm_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
H1, H2: MountingHole; Mounting_Hole_M3
J5: Input_x3; TerminalBlock_Phoenix_MKDS-1,5-3_1x03_P5.00mm_Horizontal
PS1: HLK-PM03; Converter_ACDC_Hi-Link_HLK-PMxx

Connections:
3V3: C1.1, C2.2, PS1.4 (+Vout); also elsewhere on the board
GND: C1.2, C2.1, PS1.3 (-Vout); also elsewhere on the board
L1 230VAC: F1.1, J5.2
N: J5.1, PS1.2 (AC/N)
unnamed: F1.2, PS1.1 (AC/L)
PE: J5.3

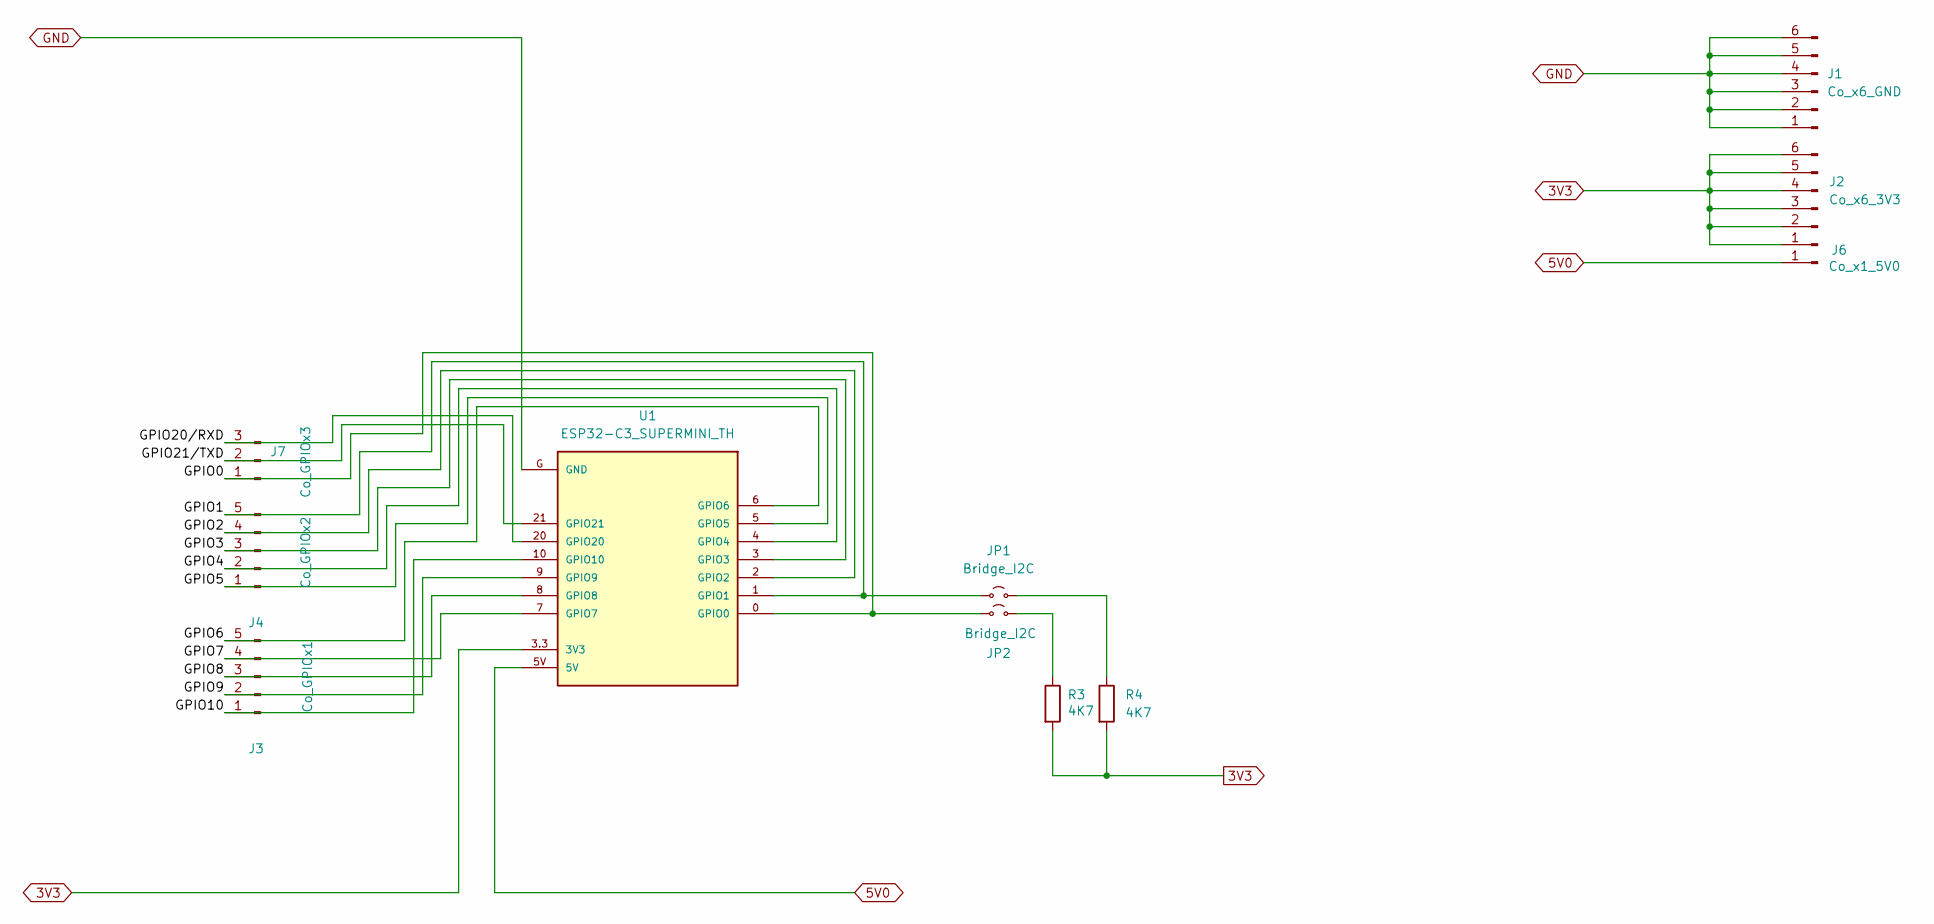
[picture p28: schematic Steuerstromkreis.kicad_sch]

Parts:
J1: Co_x6_GND; PinHeader_1x06_P2.54mm_Vertical
J2: Co_x6_3V3; PinHeader_1x06_P2.54mm_Vertical
J3: Co_GPIOx1; PinHeader_1x05_P2.54mm_Vertical
J4: Co_GPIOx2; PinHeader_1x05_P2.54mm_Vertical
J6: Co_x1_5V0; PinHeader_1x01_P2.54mm_Vertical
J7: Co_GPIOx3; PinHeader_1x03_P2.54mm_Vertical
JP1, JP2: Bridge_I2C; SolderJumper-2_P1.3mm_Open_Pad1.0x1.5mm
R3, R4: 4K7; R_0805_2012Metric_Pad1.20x1.40mm_HandSolder
U1: ESP32-C3_SUPERMINI_TH; MODULE_ESP32-C3_SUPERMINI_TH

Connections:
3V3: J2.1, J2.2, J2.3, J2.4, J2.5, J2.6, R3.2, R4.2, U1.3.3 (3V3); also elsewhere on the board
5V0: J6.1, U1.5V; also elsewhere on the board
/Steuerstromkreis/GPIO0: J7.1, JP2.1 (A), U1.0 (GPIO0); also elsewhere on the board
/Steuerstromkreis/GPIO1: J4.5, JP1.1 (A), U1.1 (GPIO1); also elsewhere on the board
/Steuerstromkreis/GPIO2: J4.4, U1.2 (GPIO2); also elsewhere on the board
/Steuerstromkreis/GPIO3: J4.3, U1.3 (GPIO3); also elsewhere on the board
/Steuerstromkreis/GPIO4: J4.2, U1.4 (GPIO4); also elsewhere on the board
/Steuerstromkreis/GPIO5: J4.1, U1.5 (GPIO5); also elsewhere on the board
/Steuerstromkreis/GPIO6: J3.5, U1.6 (GPIO6); also elsewhere on the board
/Steuerstromkreis/GPIO7: J3.4, U1.7 (GPIO7); also elsewhere on the board
/Steuerstromkreis/GPIO8: J3.3, U1.8 (GPIO8); also elsewhere on the board
/Steuerstromkreis/GPIO9: J3.2, U1.9 (GPIO9); also elsewhere on the board
/Steuerstromkreis/GPIO10: J3.1, U1.10 (GPIO10); also elsewhere on the board
/Steuerstromkreis/GPIO20/RXD: J7.3, U1.20 (GPIO20); also elsewhere on the board
/Steuerstromkreis/GPIO21/TXD: J7.2, U1.21 (GPIO21); also elsewhere on the board
GND: J1.1, J1.2, J1.3, J1.4, J1.5, J1.6, U1.G (GND); also elsewhere on the board
unnamed: JP1.2 (B), R4.1
unnamed: JP2.2 (B), R3.1

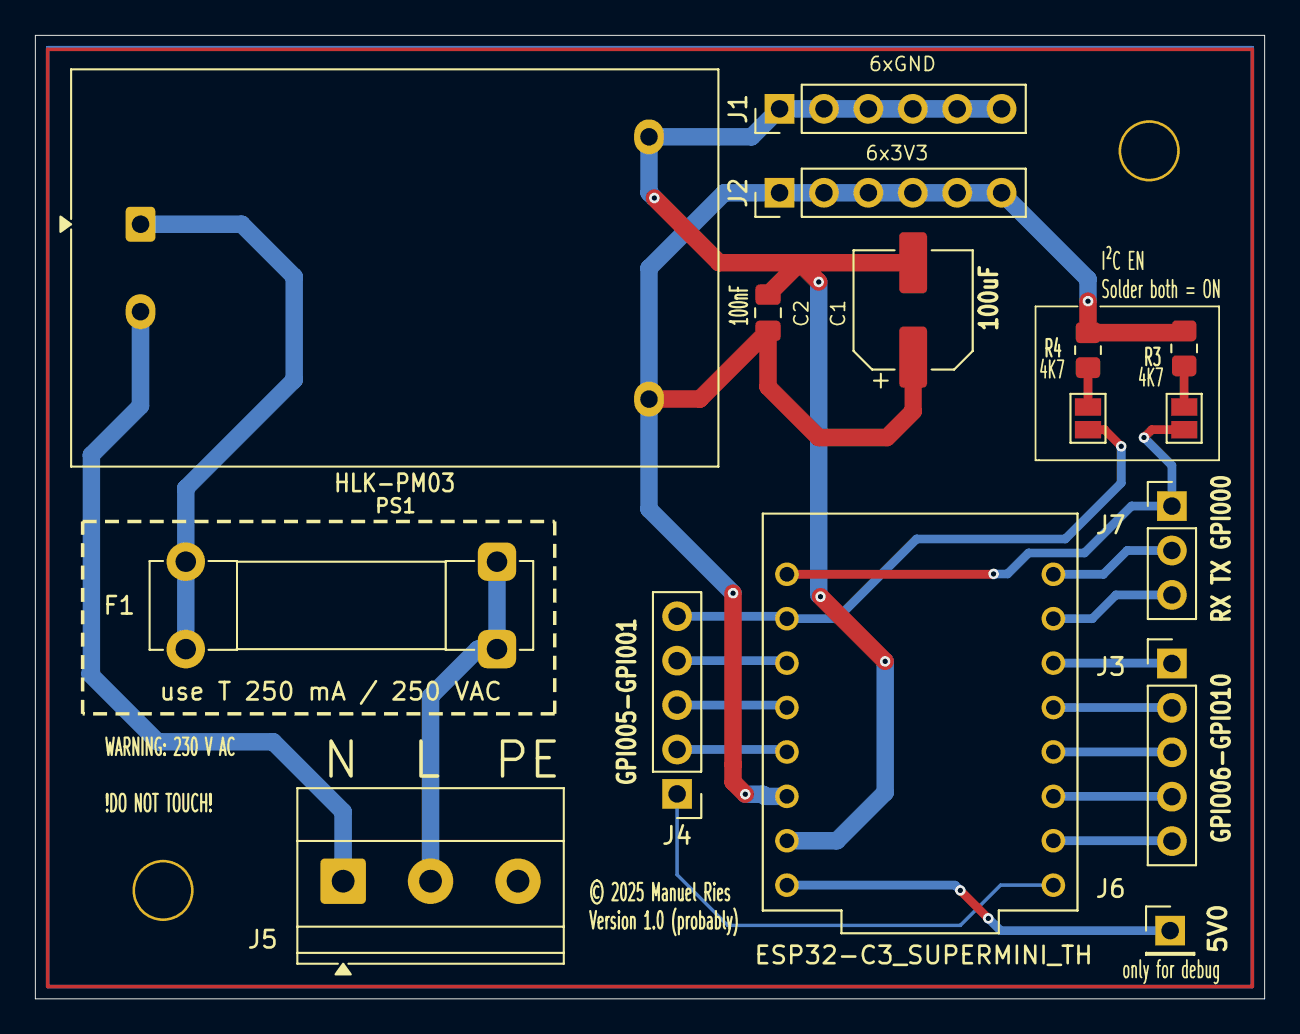
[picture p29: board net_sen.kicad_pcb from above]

Board: 2 copper layers, 70.3 x 55.1 mm, 18 parts (0 on the bottom side), 21 nets.

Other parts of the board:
ESP32-C3_SUPERMINI_TH: ESP32-C3_SUPERMINI_TH; MODULE_ESP32-C3_SUPERMINI_TH

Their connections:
3V3: ESP32-C3_SUPERMINI_TH.3.3 (3V3); also elsewhere on the board
5V0: ESP32-C3_SUPERMINI_TH.5V; also elsewhere on the board
/Steuerstromkreis/GPIO0: ESP32-C3_SUPERMINI_TH.0 (GPIO0); also elsewhere on the board
/Steuerstromkreis/GPIO1: ESP32-C3_SUPERMINI_TH.1 (GPIO1); also elsewhere on the board
/Steuerstromkreis/GPIO2: ESP32-C3_SUPERMINI_TH.2 (GPIO2); also elsewhere on the board
/Steuerstromkreis/GPIO3: ESP32-C3_SUPERMINI_TH.3 (GPIO3); also elsewhere on the board
/Steuerstromkreis/GPIO4: ESP32-C3_SUPERMINI_TH.4 (GPIO4); also elsewhere on the board
/Steuerstromkreis/GPIO5: ESP32-C3_SUPERMINI_TH.5 (GPIO5); also elsewhere on the board
/Steuerstromkreis/GPIO6: ESP32-C3_SUPERMINI_TH.6 (GPIO6); also elsewhere on the board
/Steuerstromkreis/GPIO7: ESP32-C3_SUPERMINI_TH.7 (GPIO7); also elsewhere on the board
/Steuerstromkreis/GPIO8: ESP32-C3_SUPERMINI_TH.8 (GPIO8); also elsewhere on the board
/Steuerstromkreis/GPIO9: ESP32-C3_SUPERMINI_TH.9 (GPIO9); also elsewhere on the board
/Steuerstromkreis/GPIO10: ESP32-C3_SUPERMINI_TH.10 (GPIO10); also elsewhere on the board
/Steuerstromkreis/GPIO20/RXD: ESP32-C3_SUPERMINI_TH.20 (GPIO20); also elsewhere on the board
/Steuerstromkreis/GPIO21/TXD: ESP32-C3_SUPERMINI_TH.21 (GPIO21); also elsewhere on the board
GND: ESP32-C3_SUPERMINI_TH.G (GND); also elsewhere on the board

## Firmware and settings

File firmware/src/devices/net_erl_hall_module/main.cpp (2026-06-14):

/*
===============================================================================
 Datei: main.cpp
 Code-Name: NET-ERL Hall Module
 Projekt: SmartHome Technikerprojekt
 Bereich: Firmware / Device-Code / Netzbetriebener Relais-Komfortaktor
 Ersteller: DevOpsOfChaos
 Datum: 2026-05-14
 Letzte Bearbeitung: 2026-05-18

 Zweck: Flurmodul mit PIR-Bewegung, Luxmessung, Klima-Messwerten und Relais
 Beschreibung: Dieser Device-Adapter ergaenzt den NET-ERL-Basistyp um konkrete
 Sensoren fuer den Flur. Der PIR meldet Anwesenheit, der VEML7700 liefert Lux
 fuer die Auto-Light-Entscheidung, der BME280 liefert Temperatur und Feuchte.
 Die Late-Lux-Logik wartet bei Bedarf auf den ersten gueltigen Lux-Wert, bevor
 das Relais automatisch eingeschaltet oder wegen zu hoher Helligkeit blockiert
 wird. Jede erneute PIR-Erkennung innerhalb der Nachlaufzeit startet den
 Auto-Off-Timer neu.

 Hardware:
 - ESP32-C3
 - BME280 fuer Temperatur und relative Feuchte
 - VEML7700 fuer Beleuchtungsstaerke in Lux
 - PIR-Bewegungssensor
 - Ein Relaisausgang

 Genutzte Bibliotheken:
 - Arduino.h: Arduino-Funktionen wie pinMode, digitalRead, digitalWrite und millis.
 - Wire.h: I2C-Bus fuer BME280 und VEML7700.
 - Adafruit_BME280.h: Fremdbibliothek fuer Temperatur- und Feuchtesensor BME280.
 - Adafruit_VEML7700.h: Fremdbibliothek fuer den Luxsensor VEML7700.
 - DeviceConfig.h: eigene Device-Konfiguration mit IDs, Intervallen und Schwellwerten.
 - PinConfig.h: eigene Pin-Zuordnung fuer Sensoren, Relais und Status-LED.
 - NetErlRuntime.h: eigener NET-ERL-Basistyp; liefert setup(), loop(), Funklogik,
   Auto-Light-Grundlogik und ruft die Device-Hooks aus dieser Datei auf.

 Aenderungsverlauf:
 - 2026-05-14: Device-Code fuer NET-ERL Hall Module angelegt.
 - 2026-05-18: Kommentarstil vereinheitlicht und Doxygen-Metakommentare entfernt.
===============================================================================
*/

// Arduino.h: GPIO, Zeitfunktionen, delay/delayMicroseconds und HIGH/LOW.
#include <Arduino.h>
// Wire.h: I2C-Busobjekt fuer BME280 und VEML7700. Die Busparameter werden
// spaeter in netErlDeviceInit() gesetzt, weil die Pins aus PinConfig.h kommen.
#include <Wire.h>
// Adafruit-Klassen kapseln die Registerzugriffe der Sensoren. Der Device-Code
// arbeitet dadurch mit readTemperature(), readHumidity() und readLux(), statt
// selbst I2C-Register zu parsen.
#include <Adafruit_BME280.h>
#include <Adafruit_VEML7700.h>
// math.h liefert isnan() und lroundf() fuer Plausibilitaet und Rundung.
#include <math.h>

// DeviceConfig.h beschreibt das logische Geraet, PinConfig.h die konkrete
// Verdrahtung. Beide Dateien werden vor NetErlRuntime.h geladen, damit alle
// Makros beim Runtime-Include bereits bekannt sind.
#include "DeviceConfig.h"
#include "PinConfig.h"

// Baukasten-Defines fuer den NET-ERL-Basistyp. Diese Werte muessen vor
// NetErlRuntime.h gesetzt sein, weil der Basistyp sie beim Einbinden auswertet.
// Sie bilden den "Vertrag" zwischen Device-Adapter und Basistyp:
// - STORAGE_NS/PERSISTED_* steuern NVS-Namespace und gespeichertes Layout.
// - SENSOR_MASK/INPUT_MASK gehen in die HELLO-Meta und damit bis zum Master/MQTT.
// - PAGE-/SECTION-Texte werden im Setup-Webformular des Basistyps angezeigt.
#define NET_ERL_STORAGE_NS              "net_erl_hl"
#define NET_ERL_SENSOR_MASK             "THLMXXXXXX"
#define NET_ERL_INPUT_MASK              "XXXXX"
#define NET_ERL_PERSISTED_MAGIC         0x484C4C31UL
#define NET_ERL_PERSISTED_KEY           "hall_setup_v1"
#define NET_ERL_DEVICE_PAGE_TITLE       "NET-ERL Hall Module"
#define NET_ERL_DEVICE_SECTION_TITLE    "Hall Module"
#define NET_ERL_DEVICE_SECTION_INTRO    "Lux-Schwelle und Nachlauf."

// Hall-Modul-spezifische Unterschiede zum LED-Ring-Modul.
#define NET_ERL_USE_ISR_CMD_QUEUE       1   // CMD-Queue darf aus Interrupt-Kontext genutzt werden.
#define NET_ERL_OFF_TIMER_EXTENDS_ON_MOTION 1  // Neue PIR-Erkennung setzt den Nachlauf-Timer zurueck.
#define NET_ERL_WDT_TIMEOUT_S           8UL // Watchdog-Zeit in Sekunden.

// Aktiviert die Device-Hooks in dieser Datei.
// Ohne diesen Schalter wuerde NetErlRuntime.h seine Default-Hooks nutzen und
// BME280/VEML7700/PIR dieses Adapters nie abfragen.
#define NET_ERL_DEVICE_HAS_CUSTOM_HOOKS 1

// =============================================================================
// RUNTIME - Basistyp liefert setup(), loop() und gemeinsame NET-ERL-Logik
// =============================================================================
#include "../../basetypes/net_erl/NetErlRuntime.h"

// =============================================================================
// DEVICE-SPEZIFISCHE OBJEKTE
// =============================================================================

// Globale Sensorobjekte bleiben bewusst ausserhalb des anonymen Namespace:
// Die Adafruit-Bibliotheken erwarten langlebige Objekte; lokale Stack-Objekte
// waeren nach initBme280()/initVeml7700() wieder zerstoert.
Adafruit_BME280 bme280;
Adafruit_VEML7700 veml7700 = Adafruit_VEML7700();

// =============================================================================
// DEVICE-SPEZIFISCHER ZUSTAND
// =============================================================================
namespace {
    // -- Sensor-Gesundheit ------------------------------------------------
    bool bme280_ok = false, veml7700_ok = false;
    uint8_t bme_fail_count = 0, veml_fail_count = 0;
    unsigned long bme_last_ok_ms = 0, veml_last_ok_ms = 0;
    unsigned long letzter_bme_recovery_ms = 0, letzter_veml_recovery_ms = 0;
    unsigned long letztes_env_sample_ms = 0;
    unsigned long veml7700_bereit_seit_ms = 0;

    // -- I2C-Bus-Zustand ---------------------------------------------------
    uint8_t  i2c_recovery_count = 0;
    unsigned long last_i2c_recovery_ms = 0;
    constexpr uint32_t I2C_RECOVERY_COOLDOWN_MS = 30000UL;               // constexpr liegt im Flash/Compile-Time-Kontext; spart RAM gegenueber veraenderbaren Variablen.
    constexpr uint8_t  SENSOR_MAX_FAIL_BEFORE_RECOVERY = 3;              // Nach 3 Fehlern I2C-Recovery, damit einzelne Messausreisser nicht sofort den Bus resetten.

    // Sensor-Messwerte
    int16_t temp_01c = INT16_MIN;                                       // INT16_MIN = Sentinel "kein gueltiger Messwert" (Temperatur).
    uint16_t hum_01pct = 0xFFFFU, lux = 0xFFFFU;                       // 0xFFFF = Sentinel "kein gueltiger Messwert" (Feuchte, Lux).
    bool pir_raw = false;

    // EMA-Filter fuer Temperatur und Feuchte (daempft Sensorrauschen).
    // alpha = 0.2 bedeutet: 20 % neuer Wert, 80 % alter Mittelwert.
    // Je kleiner alpha, desto staerker die Glaettung.
    constexpr float EMA_ALPHA = 0.2f;
    float temp_ema = NAN, hum_ema = NAN;
}

// =============================================================================
// SENSOR-HILFSFUNKTIONEN (device-spezifisch)
// =============================================================================
namespace {
    // Aufgabe: Initialisiert den BME280 an der konfigurierten I2C-Adresse.
    // Eingabewerte: keine; NET_ERL_BME280_ADDRESS kommt aus DeviceConfig.h.
    // Ausgabewert: true bedeutet, der Sensor wurde gefunden und ist nutzbar.
    bool initBme280() {
        const uint8_t addrs[] = {(uint8_t)NET_ERL_BME280_ADDRESS};
        for (uint8_t a : addrs) {
            if (!bme280.begin(a, &Wire)) continue; // begin() spricht den Sensor per I2C an; false bedeutet Adresse antwortet nicht.
            return true;
        }
        return false;
    }

    // Aufgabe: Konfiguriert den VEML7700 fuer die Luxmessung.
    // Eingabewerte: keine.
    // Ausgabewert: keiner; die Adafruit_VEML7700-Instanz wird intern konfiguriert.
    // 100 ms Integrationszeit bedeuten, dass eine einzelne Messung etwa 0,1 Sekunden Licht sammelt.
    void konfVeml7700() {
        veml7700.setGain(VEML7700_GAIN_1);              // Bibliotheksfunktion: Verstaerkung x1, damit helle Bereiche nicht so schnell saettigen.
        veml7700.setIntegrationTime(VEML7700_IT_100MS); // Laengere Integration = stabilerer Luxwert, aber langsamere Reaktion.
    }

    // Aufgabe: Initialisiert den VEML7700 und merkt den Bereit-Zeitpunkt.
    // Eingabewert: jetzt ist der aktuelle millis()-Zeitstempel in Millisekunden.
    // Ausgabewert: true bedeutet, der Sensor antwortet und wurde konfiguriert.
    bool initVeml7700(unsigned long jetzt) {
        if (!veml7700.begin()) return false;
        konfVeml7700();
        veml7700_bereit_seit_ms = jetzt;
        return true;
    }

    // Aufgabe: I2C-Bus-Recovery via SCL-Pulse (holt SDA aus stuck-LOW).
    void i2cBusRecoveryPulse() {
        pinMode(PIN_SENSOR_SCL, OUTPUT);
        pinMode(PIN_SENSOR_SDA, INPUT_PULLUP);
        for (int i = 0; i < 12; i++) {
            digitalWrite(PIN_SENSOR_SCL, LOW);
            delayMicroseconds(20);
            digitalWrite(PIN_SENSOR_SCL, HIGH);
            delayMicroseconds(20);
        }
        digitalWrite(PIN_SENSOR_SCL, HIGH);
        delayMicroseconds(10);
        pinMode(PIN_SENSOR_SDA, OUTPUT);
        digitalWrite(PIN_SENSOR_SDA, HIGH);
        delayMicroseconds(10);
        pinMode(PIN_SENSOR_SDA, INPUT_PULLUP);
    }

    // Aufgabe: I2C-Bus-Recovery mit Cooldown.
    // Beendet Wire, macht SCL-Pulse (Bus-Recovery), und initialisiert neu.
    // Nur ausfuehren, wenn die Cooldown-Zeit abgelaufen ist.
    bool recoverI2cBus(unsigned long nowMs, const char* reason) {
        if ((nowMs - last_i2c_recovery_ms) < I2C_RECOVERY_COOLDOWN_MS) {
            return false;
        }
        last_i2c_recovery_ms = nowMs;
        i2c_recovery_count++;
        logMsg("WARN", "I2C recovery #%u reason=%s", i2c_recovery_count, reason ? reason : "?");

        Wire.end(); // I2C-Treiber kurz abschalten, damit die folgenden GPIO-Pulse den Bus manuell freiziehen koennen.
        delay(50);
        i2cBusRecoveryPulse();
        delay(10);
        Wire.begin(PIN_SENSOR_SDA, PIN_SENSOR_SCL); // Wire neu starten, weil Wire.end() den I2C-Treiber beendet hat.
        Wire.setClock(NET_ERL_I2C_CLOCK_HZ);        // Niedriger Takt ist robuster bei langen Leitungen/stoeranfaelligem Bus.
        Wire.setTimeOut(NET_ERL_I2C_TIMEOUT_MS);    // Timeout verhindert, dass ein blockierter Sensor die Firmware dauerhaft festhaelt.
        delay(10);
        return true;
    }

    // Aufgabe: Markiert einen Sensor als ausgefallen und loggt den Grund.
    void markSensorFailed(bool& okFlag, uint8_t& failCount, const char* name, const char* reason) {
        okFlag = false;
        if (failCount < 255) failCount++;
        logMsg("WARN", "%s fail (#%u): %s", name, failCount, reason);
    }

    // Aufgabe: Markiert einen Sensor als erfolgreich gelesen.
    void markSensorOk(bool& okFlag, uint8_t& failCount, unsigned long& lastOkMs,
                      unsigned long nowMs, const char* name) {
        if (!okFlag) {
            logMsg("INFO", "%s recovered after %u failures", name, failCount);
        }
        okFlag = true;
        failCount = 0;
        lastOkMs = nowMs;
    }

    // Aufgabe: Prueft, ob ein Sensor-Retry (nach Init-Failure) faellig ist.
    bool sensorRetryDue(unsigned long lastRecoveryMs, unsigned long nowMs) {
        return SmartHome::recoveryIsDue(lastRecoveryMs, nowMs, NET_ERL_SENSOR_RECOVERY_RETRY_INTERVAL_MS);
    }
}

// =============================================================================
// CUSTOM HOOKS (von NetErlRuntime.h aufgerufen)
// =============================================================================

// Aufgabe: Initialisiert I2C-Bus, BME280, VEML7700 und PIR-Pin.
// Eingabewerte: keine; Pins und Adressen kommen aus DeviceConfig.h und PinConfig.h.
// Ausgabewert: keiner; die lokalen Sensor-OK-Flags werden gesetzt.
// Aufrufer: NetErlRuntime ruft diesen Hook einmal beim Boot auf.
void netErlDeviceInit() {
    Wire.begin(PIN_SENSOR_SDA, PIN_SENSOR_SCL); // Startet I2C auf den Pins aus PinConfig.h statt auf Arduino-Defaultpins.
    Wire.setClock(NET_ERL_I2C_CLOCK_HZ);        // 5 kHz ist langsam, aber robuster bei langen oder gestoerten Leitungen.
    Wire.setTimeOut(NET_ERL_I2C_TIMEOUT_MS);    // Timeout verhindert, dass ein defekter I2C-Sensor die loop() dauerhaft blockiert.

    bme280_ok = initBme280();
    if (!bme280_ok) markSensorFailed(bme280_ok, bme_fail_count, "BME280", "init");
    else markSensorOk(bme280_ok, bme_fail_count, bme_last_ok_ms, millis(), "BME280");

    veml7700_ok = initVeml7700(millis());
    if (!veml7700_ok) markSensorFailed(veml7700_ok, veml_fail_count, "VEML7700", "init");
    else markSensorOk(veml7700_ok, veml_fail_count, veml_last_ok_ms, millis(), "VEML7700");

    pinMode(PIN_PIR, INPUT);
// Status-LED nur initialisieren, wenn sie wirklich bestueckt ist.
#if PIN_STATUS_LED >= 0
    pinMode(PIN_STATUS_LED, OUTPUT);
    digitalWrite(PIN_STATUS_LED, LOW);
#endif
    
#if SETUP_INDICATOR_LED_PIN >= 0
    pinMode(SETUP_INDICATOR_LED_PIN, OUTPUT);
    digitalWrite(SETUP_INDICATOR_LED_PIN, SETUP_INDICATOR_LED_ACTIVE_HIGH ? LOW : HIGH); // LED aus, aber mit richtiger active-HIGH/LOW-Polung.
#endif
}

// Aufgabe: Setzt alle Sensorwerte auf die ungueltigen Startwerte zurueck.
// Eingabewerte: keine.
// Ausgabewert: keiner; INT16_MIN und 0xFFFFU markieren ungueltige Messwerte.
void netErlDeviceResetSensorDefaults() {
    temp_01c = INT16_MIN; hum_01pct = 0xFFFFU; lux = 0xFFFFU;
    temp_ema = NAN; hum_ema = NAN;
}

// Aufgabe: Liest den PIR-Bewegungssensor und speichert den Rohstatus.
// Eingabewerte: keine; PIN_PIR kommt aus PinConfig.h.
// Ausgabewert: true bedeutet, der PIR-Pin steht auf HIGH und Bewegung wurde erkannt.
bool netErlDeviceReadPresence() {
    pir_raw = (digitalRead(PIN_PIR) == HIGH); // PIR-Module liefern hier HIGH bei Bewegung; keine Entprellung noetig wie bei Tastern.
    return pir_raw;
}

// Aufgabe: Schaltet den Relaisausgang und optional die Status-LED.
// Eingabewert: on=true bedeutet Relais soll aktiv sein.
// Ausgabewert: keiner; digitalWrite setzt die GPIO-Pegel.
// RELAY_1_ACTIVE_HIGH legt fest, ob HIGH oder LOW den aktiven Relaiszustand bedeutet.
void netErlDeviceSetRelayOutput(bool on) {
    digitalWrite(PIN_RELAY_1, on == RELAY_1_ACTIVE_HIGH ? HIGH : LOW); // Ternary bildet fachliches "an" auf elektrische Relais-Polung ab.
#if PIN_STATUS_LED >= 0
    digitalWrite(PIN_STATUS_LED, on ? HIGH : LOW);
#endif
}

// Aufgabe: Pollt die Sensoren, versucht Recovery und fuehrt die Late-Lux-Entscheidung aus.
// Eingabewert: nowMs ist der aktuelle millis()-Zeitstempel in Millisekunden.
// Ausgabewert: keiner; Messwerte, runtime.fault und runtime.state_report_offen werden aktualisiert.
//
// Ablauf:
// 1. NET_ERL_ENV_SAMPLE_INTERVAL_MS begrenzt die Messrate. Der Wert ist in Millisekunden.
// 2. I2C-Bus-Recovery wenn mehrere Sensoren wiederholt ausfallen.
// 3. BME280 liefert Temperatur in Grad Celsius und relative Feuchte in Prozent.
// 4. VEML7700 liefert Lux; negative oder NaN-Werte gelten als Fehler.
// 5. Late-Lux entscheidet ein wartendes Auto-On erst, wenn ein gueltiger Lux-Wert vorliegt.
// 6. Delta-Detection setzt nur bei relevanten Messwertaenderungen einen STATE-Report.
//
// Master-Kommandos duerfen Auto-Light spaeter uebersteuern. Die urspruengliche
// Auto-On-Entscheidung bleibt trotzdem sauber getrennt.
void netErlDevicePollSensors(unsigned long nowMs) {
    if ((nowMs - letztes_env_sample_ms) < NET_ERL_ENV_SAMPLE_INTERVAL_MS) return;
    letztes_env_sample_ms = nowMs;

    // WDT zuruecksetzen vor potenziell blockierenden I2C-Operationen
    esp_task_wdt_reset(); // Watchdog fuettern: Sensor-I2C kann kurz blockieren, soll aber keinen Reset ausloesen.

    // --- Hilfs-Lambda fuer Recovery-Pruefungen ---
    auto recoveryNeeded = [&](bool ok, uint8_t failCount) -> bool {
        return !ok || failCount >= SENSOR_MAX_FAIL_BEFORE_RECOVERY;
    };

    // --- I2C-Bus-Recovery wenn noetig (nach wiederholten Sensorfehlern) ---
    bool needI2cRecovery = recoveryNeeded(bme280_ok, bme_fail_count)
                        || recoveryNeeded(veml7700_ok, veml_fail_count);

    if (needI2cRecovery) {
        if (recoverI2cBus(nowMs, "multi_sensor_fail")) {
            // Nach I2C-Recovery alle ausgefallenen Sensoren neu initialisieren.
            if (!bme280_ok && sensorRetryDue(letzter_bme_recovery_ms, nowMs)) {
                letzter_bme_recovery_ms = nowMs;
                bme280_ok = initBme280();
                if (bme280_ok) markSensorOk(bme280_ok, bme_fail_count, bme_last_ok_ms, nowMs, "BME280");
                else markSensorFailed(bme280_ok, bme_fail_count, "BME280", "recovery");
            }
            if (!veml7700_ok && sensorRetryDue(letzter_veml_recovery_ms, nowMs)) {
                letzter_veml_recovery_ms = nowMs;
                veml7700_ok = initVeml7700(nowMs);
                if (veml7700_ok) markSensorOk(veml7700_ok, veml_fail_count, veml_last_ok_ms, nowMs, "VEML7700");
                else markSensorFailed(veml7700_ok, veml_fail_count, "VEML7700", "recovery");
            }
        }
    }

    // --- Einzelsensor-Recovery (wenn nur ein Sensor ausgefallen, ohne I2C-Reset) ---
    if (!bme280_ok && sensorRetryDue(letzter_bme_recovery_ms, nowMs)) {
        letzter_bme_recovery_ms = nowMs;
        bme280_ok = initBme280();
        if (bme280_ok) markSensorOk(bme280_ok, bme_fail_count, bme_last_ok_ms, nowMs, "BME280");
        else markSensorFailed(bme280_ok, bme_fail_count, "BME280", "retry");
    }
    if (!veml7700_ok && sensorRetryDue(letzter_veml_recovery_ms, nowMs)) {
        letzter_veml_recovery_ms = nowMs;
        veml7700_ok = initVeml7700(nowMs);
        if (veml7700_ok) markSensorOk(veml7700_ok, veml_fail_count, veml_last_ok_ms, nowMs, "VEML7700");
        else markSensorFailed(veml7700_ok, veml_fail_count, "VEML7700", "retry");
    }

    // BME280 lesen: Temperatur wird spaeter als Zehntelgrad, Feuchte als 0,1 Prozent gemeldet.
    if (bme280_ok) {
        float t = bme280.readTemperature(); // Adafruit-Bibliothek liest intern I2C-Register und gibt Grad Celsius als float zurueck.
        float h = bme280.readHumidity();    // Float wird spaeter in Zehntelprozent umgerechnet, weil das Funkprotokoll Integer nutzt.
        if (!isnan(t) && !isnan(h) && h >= 0 && h <= 100) {
            temp_01c = (int16_t)lroundf(t * 10.0f); // 23.4 Grad C wird zu 234; Integer spart Payload-Speicher und vermeidet float im Protokoll.
            hum_01pct = SmartHome::clampHum01pct((long)lroundf(h * 10.0f)); // clamp schuetzt vor Werten ausserhalb 0..1000.

            // Exponentiell gleitender Mittelwert (EMA) zur Rauschunterdrueckung.
            // Erste Messung initialisiert den Filter ohne Glaettung.
            if (isnan(temp_ema)) { temp_ema = (float)temp_01c; hum_ema = (float)hum_01pct; }
            else {
                temp_ema = EMA_ALPHA * (float)temp_01c + (1.0f - EMA_ALPHA) * temp_ema;
                hum_ema  = EMA_ALPHA * (float)hum_01pct + (1.0f - EMA_ALPHA) * hum_ema;
            }
            temp_01c = (int16_t)(lroundf(temp_ema) + NET_ERL_TEMP_OFFSET_01C);
            hum_01pct = SmartHome::clampHum01pct((long)(lroundf(hum_ema) + NET_ERL_HUM_OFFSET_01PCT));
            markSensorOk(bme280_ok, bme_fail_count, bme_last_ok_ms, nowMs, "BME280");
        } else {
            markSensorFailed(bme280_ok, bme_fail_count, "BME280", "unplausibel");
            temp_01c = INT16_MIN; hum_01pct = 0xFFFFU;
        }
    }

    esp_task_wdt_reset(); // nach BME280-Read

    // VEML7700 lesen: Lux wird auf uint16_t begrenzt, damit der Protokoll-Payload passt.
    if (veml7700_ok) {
        float l = veml7700.readLux(); // Bibliotheksfunktion rechnet Rohdaten bereits in Lux um.
        if (!isnan(l) && l >= 0) {
            lux = SmartHome::clampToU16((long)lroundf(l));
            markSensorOk(veml7700_ok, veml_fail_count, veml_last_ok_ms, nowMs, "VEML7700");
        } else {
            markSensorFailed(veml7700_ok, veml_fail_count, "VEML7700", "read");
            lux = 0xFFFFU;
        }
    }

    // Status aktualisieren: fault=true sobald einer der beiden Sensoren nicht verfuegbar ist.
    runtime.fault = !(bme280_ok && veml7700_ok);

    // Late-Lux: Auto-On-Entscheidung erst ausfuehren, wenn ein Lux-Wert verfuegbar ist.
    if (runtime.motion_aktiv && runtime.pending_auto_on_decision && !runtime.relay_1 && lux != 0xFFFFU) {
        runtime.pending_auto_on_decision = false;
        if (lux <= runtime.auto_on_lux_threshold) {
            runtime.relay_auto_owned = true; runtime.blocked_by_lux = false;
            setRelay(true, "auto_on_late_lux");
            sendRelayEvent(SH_TRIGGER_AUTO);
            runtime.state_report_offen = true;
        } else {
            runtime.blocked_by_lux = true;
            runtime.state_report_offen = true;
        }
    }

    // Delta-Detection: STATE-Trigger nur bei signifikanter Sensorwert-Aenderung.
    {
        static int16_t  last_temp = INT16_MIN; // static merkt den letzten Wert zwischen Funktionsaufrufen, ohne globale Variable.
        static uint16_t last_hum = 0xFFFFU, last_lux = 0xFFFFU; // 0xFFFF ist Sentinel "ungueltig"; echte Messwerte bleiben darunter.

        bool changed = false;
        if (temp_01c != last_temp) { last_temp = temp_01c; changed = true; }
        if (SmartHome::absDiffU16(hum_01pct, last_hum) >= 5U) { last_hum = hum_01pct; changed = true; }
        if (SmartHome::absDiffU16(lux, last_lux) >= 5U) { last_lux = lux; changed = true; }

        if (changed) runtime.state_report_offen = true;
    }
}
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

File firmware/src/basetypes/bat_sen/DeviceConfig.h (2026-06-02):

// =============================================================================
// DeviceConfig.h – Geraetekonfiguration fuer BAT-SEN Basistyp
// =============================================================================
// Projekt:    Smarthome Technikerprojekt
// Pfad:       firmware/src/basetypes/bat_sen/DeviceConfig.h
//
// Datei-Funktion:
//   Default-Konfiguration fuer BAT-SEN-Batteriesensoren. Definiert
//   Geraete-Identitaet, Battery-Profile (Spannungsbereiche fuer
//   CR2032, AA, AAA, LiIon), Wake-Intervalle, RX-Fenster und
//   ADC-Konfiguration. Enthaelt static_asserts zur Compilezeit-
//   Validierung aller Grenzen.
//
// Autor:           DevOpsOfChaos
// Erstelldatum:    2026-05-14
// Letzte Aenderung: 2026-05-14
//
// Aenderungshistorie:
//   [2026-05-14] DevOpsOfChaos – Kommentierung (Deutsch)
// =============================================================================

#pragma once

#include <stdint.h>

#include "../../../lib/sh_protocol/src/DeviceTypes.h"

// =============================================================================
// GERAETE-IDENTITAET – ID, Name, Variante (pro Device ueberschreibbar)
// =============================================================================

#ifndef BAT_SEN_DEVICE_ID
#define BAT_SEN_DEVICE_ID "BAT-SEN-001"
#endif

#ifndef BAT_SEN_DEVICE_NAME
#define BAT_SEN_DEVICE_NAME "BAT-SEN Base"
#endif

#ifndef BAT_SEN_FW_VARIANT
#define BAT_SEN_FW_VARIANT "bat_sen_base"
#endif

#ifndef BAT_SEN_DEVICE_CAPS
#define BAT_SEN_DEVICE_CAPS SH_CAP_BATTERY
#endif

// =============================================================================
// REPORTING – Reporting-Modus (Batterie: sleep_event)
// =============================================================================

#ifndef BAT_SEN_REPORTING_MODE
#define BAT_SEN_REPORTING_MODE SH_REPORTING_SLEEP_EVENT
#endif

// =============================================================================
// FUNK – WLAN-Kanal
// =============================================================================

#ifndef BAT_SEN_WLAN_CHANNEL
#define BAT_SEN_WLAN_CHANNEL 6
#endif

// =============================================================================
// DEBUG – Serielle Ausgaben
// =============================================================================

#ifndef BAT_SEN_DEBUG_ENABLED
#define BAT_SEN_DEBUG_ENABLED 1
#endif

// =============================================================================
// TIMING – Intervalle fuer HELLO, Discovery, Wake, RX, Loop
// =============================================================================

// HELLO-Wiederholung bei Master-Suche (ms)
#ifndef BAT_SEN_HELLO_RETRY_INTERVAL_MS
#define BAT_SEN_HELLO_RETRY_INTERVAL_MS 5000UL
#endif

// Discovery-Fenster: Zeit nach Boot in der auf HELLO_ACK gewartet wird (ms)
#ifndef BAT_SEN_DISCOVERY_WINDOW_MS
#define BAT_SEN_DISCOVERY_WINDOW_MS 25000UL
#endif

// Wake-Intervall: Wie oft das Geraet aufwacht (Sekunden, Default: 15min)
#ifndef BAT_SEN_DEFAULT_WAKE_INTERVAL_S
#define BAT_SEN_DEFAULT_WAKE_INTERVAL_S 900U
#endif

// RX-Fenster: Wie lange nach Wake auf eingehende Nachrichten gewartet wird (ms)
#ifndef BAT_SEN_DEFAULT_RX_WINDOW_MS
#define BAT_SEN_DEFAULT_RX_WINDOW_MS 800U
#endif

// Wake-Intervall-Grenzen
#ifndef BAT_SEN_MIN_WAKE_INTERVAL_S
#define BAT_SEN_MIN_WAKE_INTERVAL_S 30U
#endif

#ifndef BAT_SEN_MAX_WAKE_INTERVAL_S
#define BAT_SEN_MAX_WAKE_INTERVAL_S 65535U
#endif

// RX-Fenster-Grenzen
#ifndef BAT_SEN_MIN_RX_WINDOW_MS
#define BAT_SEN_MIN_RX_WINDOW_MS 500U
#endif

#ifndef BAT_SEN_MAX_RX_WINDOW_MS
#define BAT_SEN_MAX_RX_WINDOW_MS 60000U
#endif

// Loop-Ausfuehrungsintervall (ms)
#ifndef BAT_SEN_LOOP_INTERVAL_MS
#define BAT_SEN_LOOP_INTERVAL_MS 25UL
#endif

// =============================================================================
// BATTERIE – Sampling und Hysterese
// =============================================================================

// Abstand zwischen Batterie-Messungen (ms)
#ifndef BAT_SEN_BATTERY_SAMPLE_INTERVAL_MS
#define BAT_SEN_BATTERY_SAMPLE_INTERVAL_MS 5000UL
#endif

// Hysterese: Mindestaenderung in mV um neuen STATE auszuloesen
#ifndef BAT_SEN_BATTERY_STATE_DELTA_MV
#define BAT_SEN_BATTERY_STATE_DELTA_MV 10U
#endif

// Hysterese: Mindestaenderung in Prozent um neuen STATE auszuloesen
#ifndef BAT_SEN_BATTERY_STATE_DELTA_PCT
#define BAT_SEN_BATTERY_STATE_DELTA_PCT 1U
#endif

// =============================================================================
// BATTERY-PROFILE – Spannungsbereiche fuer verschiedene Batterietypen
// =============================================================================

#define BAT_PROFILE_CR2032 1U   // CR2032 Knopfzelle (2.2V-3.0V)
#define BAT_PROFILE_2X_AA   2U  // 2x AA in Reihe (2.0V-3.2V)
#define BAT_PROFILE_3X_AA   3U  // 3x AA in Reihe (3.0V-4.8V)
#define BAT_PROFILE_2X_AAA  4U  // 2x AAA in Reihe (2.0V-3.2V)
#define BAT_PROFILE_3X_AAA  5U  // 3x AAA in Reihe (3.0V-4.8V)
#define BAT_PROFILE_LIION_1S 6U // 1S LiIon/LiPo (3.0V-4.2V)
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

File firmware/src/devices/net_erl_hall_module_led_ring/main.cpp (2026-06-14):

/*
===============================================================================
 Datei: main.cpp
 Code-Name: NET-ERL Hall Module LED Ring
 Projekt: SmartHome Technikerprojekt
 Bereich: Firmware / Device-Code / Netzbetriebener Relais-Komfortaktor
 Ersteller: DevOpsOfChaos
 Datum: 2026-05-14
 Letzte Bearbeitung: 2026-05-19

 Zweck: Flurmodul mit Radar-Praesenz, Luftqualitaet, Luxmessung, Relais und LED-Ring
 Beschreibung: Dieser Device-Adapter ist die umfangreichste NET-ERL-Variante.
 Er verbindet den NET-ERL-Basistyp mit LD2410-Radar, BME680, VEML7700, ENS160
 und NeoPixel-LED-Ring. Der BME680 liefert Temperatur, Feuchte, Luftdruck und
 Gaswiderstand. Der ENS160 nutzt Temperatur und Feuchte als Kompensation und
 liefert AQI, TVOC und eCO2. Der VEML7700 liefert Lux fuer die Auto-Light-
 Entscheidung. Der LED-Ring zeigt als Bestandteil der Technikerarbeit die
 Luftqualitaet an. Weitere Ringanzeigen fuer Temperatur, Feuchte und lokale
 Hinweise sind reine Komfort-Erweiterungen und getrennt kommentiert.

 Wichtige Zeitwerte:
 - 400 ms VEML7700-Integrationszeit: laengere Lichtmessung fuer stabilere Luxwerte.
 - 150 ms BME680-Heizprofil: Heizdauer fuer eine Gas-Messung.
 - 180 s BME680-Gaswarmup: 180 Sekunden, also 3 Minuten, bis Gaswerte gemeldet werden.
 - SENSOR_RECOVERY_RETRY_INTERVAL_MS: Millisekunden-Abstand fuer Sensor-Recovery.

 Hardware:
 - ESP32-C3
 - BME680 fuer Temperatur, relative Feuchte, Luftdruck und Gaswiderstand
 - VEML7700 fuer Beleuchtungsstaerke in Lux
 - ENS160 fuer AQI, TVOC und eCO2
 - LD2410-Radar fuer Praesenz
 - NeoPixel-LED-Ring
 - Ein Relaisausgang
 - Ein lokaler Button

 Genutzte Bibliotheken:
 - Arduino.h: Arduino-Funktionen wie pinMode, digitalRead und digitalWrite.
 - Wire.h: I2C-Bus fuer BME680, VEML7700 und ENS160.
 - Adafruit_BME680.h: Fremdbibliothek fuer den BME680.
 - Adafruit_VEML7700.h: Fremdbibliothek fuer den VEML7700.
 - Adafruit_NeoPixel.h: Fremdbibliothek fuer den LED-Ring.
 - ScioSense_ENS160.h: Fremdbibliothek fuer den ENS160-Luftqualitaetssensor.
 - DeviceConfig.h: eigene Device-Konfiguration mit IDs, Adressen, Intervallen und Schwellwerten.
 - PinConfig.h: eigene Pin-Zuordnung fuer Sensoren, Relais, Button und LED-Ring.
 - NetErlRuntime.h: eigener NET-ERL-Basistyp; liefert setup(), loop(), Funklogik,
   Auto-Light-Grundlogik und ruft die Device-Hooks aus dieser Datei auf.

 Aenderungsverlauf:
 - 2026-05-14: Device-Code fuer NET-ERL Hall Module LED Ring angelegt.
 - 2026-05-18: Kommentarstil vereinheitlicht und Doxygen-Metakommentare entfernt.
 - 2026-05-19: Sensor-Ausfallpfade, ENS160-Warmup und Auto-Flags bereinigt.
 - 2026-05-21: LED-Ring-Anzeige fuer AQI ergaenzt; weitere Ring-Komfortphasen abgegrenzt.
===============================================================================
*/

// Arduino.h stellt GPIO, Zeitfunktionen, delay(), Serial-nahe Typen und HIGH/LOW bereit.
#include <Arduino.h>
// Wire.h ist der gemeinsame I2C-Bus fuer BME680, VEML7700 und ENS160.
#include <Wire.h>
// Externe Sensor-/LED-Klassen: Sie kapseln Registerzugriffe und Timingdetails,
// sodass dieser Device-Adapter nur Messwerte und Anzeigezustand verarbeitet.
#include <Adafruit_BME680.h>
#include <Adafruit_VEML7700.h>
#include <Adafruit_NeoPixel.h>
#include <ScioSense_ENS160.h>

#ifndef ENS160_REG_TEMP_IN
// Einige ENS160-Bibliotheksversionen exportieren das Temperatur-Register nicht.
// Der Fallback haelt die Firmware gegen diese Versionsabweichung kompilierbar.
#define ENS160_REG_TEMP_IN 0x13
#endif

// DeviceConfig.h liefert Identitaet, Capabilities, Sensoradressen und Timer.
// PinConfig.h liefert die konkrete GPIO-Belegung fuer dieses LED-Ring-Board.
#include "DeviceConfig.h"
#include "PinConfig.h"

// Baukasten-Defines fuer den NET-ERL-Basistyp. Diese Werte muessen vor
// NetErlRuntime.h gesetzt sein, weil der Basistyp sie beim Einbinden auswertet.
// Diese Makros konfigurieren den generischen Basistyp fuer genau diese Variante:
// HELLO-Meta, NVS-Speicher, Setup-Webtexte, Button-Support und Indicator-Hook.
#define NET_ERL_STORAGE_NS              "net_erl_hlr"
#define NET_ERL_SENSOR_MASK             "THLPGAMXXX"
#define NET_ERL_INPUT_MASK              "BXXXX"
#define NET_ERL_PERSISTED_MAGIC         0x4B544331UL
#define NET_ERL_PERSISTED_KEY           "hall_led_cfg_v1"
#define NET_ERL_DEVICE_PAGE_TITLE       "NET-ERL Hall Module LED Ring"
#define NET_ERL_DEVICE_SECTION_TITLE    "Hall Module LED Ring"
#define NET_ERL_DEVICE_SECTION_INTRO    "Lux-Schwelle und Nachlauf."
#define NET_ERL_HAS_BUTTON
#define NET_ERL_HAS_INDICATOR_UPDATE

// Aktiviert die Device-Hooks in dieser Datei.
// Der Basistyp ruft dadurch netErlDeviceInit(), netErlDevicePollSensors(),
// netErlDeviceFillStatePayload() und weitere Hook-Funktionen aus diesem Adapter.
#define NET_ERL_DEVICE_HAS_CUSTOM_HOOKS 1

// =============================================================================
// RUNTIME - Basistyp liefert setup(), loop() und gemeinsame NET-ERL-Logik
// =============================================================================
#include "../../basetypes/net_erl/NetErlRuntime.h"

// =============================================================================
// DEVICE-SPEZIFISCHE OBJEKTE
// =============================================================================
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

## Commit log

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2026-04-01 firmware: clean up bat_sen device binding structure
    [BatSenRuntime.h, main.cpp]
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2026-04-01 firmware: clean up net_sen binding structure and path status
    [DeviceConfig.h, NetSenRuntime.h, main.cpp]
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2026-04-04 fix: preserve state values when master meta is missing
    [main.cpp]
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2026-04-06 firmware: prepare net_zrl for fixed hardware test setup
    [main.cpp]
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2026-04-07 firmware: avoid half-active setup mode on AP failure
    [main.cpp]
2026-04-07 firmware: align web calibration reset semantics with serial maintenance path
    [main.cpp]
2026-04-07 firmware: fix net_zrl serial setup command dispatch
    [main.cpp]
2026-04-07 firmware: streamline provisioning ui and avoid redundant setup writes
    [main.cpp]
2026-04-08 firmware: stabilize dynamic master registry and cover command wave01
    [AppConfig.h, main.cpp]
2026-04-08 fix: re-announce net_zrl after master recovery
    [main.cpp]
2026-04-08 feat: add simple net_zrl time automation
    Fix the central project version so the flashed master reports the current firmware label over MQTT.
    Add a small NET-ZRL cover detail page in Node-RED with exactly two daily time/value slots and fixed position choices 0/25/50/75/100, persisted locally outside the neutral device contract.
    Keep the official cover command path narrow by reusing the existing set_position command builder instead of adding schedule semantics to the MQTT contract or the shared device model.
    Fix NET-ZRL local motion safety so uncalibrated open/close runs stop after default_estimated_travel_time_ms instead of running indefinitely.
    Document the master flash verification, the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
    [main.cpp]
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2026-04-09 fix: align device store with sqlite schema
2026-04-09 fix: tighten server v1 runtime validation issues
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2026-04-10 fix: allow net_zrl end positions without calibration in dashboard ui
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2026-04-10 refactor: tighten dashboard card and detail layouts
2026-04-10 fix: keep dashboard detail in sync with live device state
2026-04-10 fix: harden net_zrl stop leds and millis timeouts
    [main.cpp]
2026-04-10 fix: map uncalibrated net_zrl end positions to full travel commands
    [main.cpp]
2026-04-10 fix: keep coarse end position state for uncalibrated net_zrl
    [main.cpp]
2026-04-10 fix: publish unknown uncalibrated cover position explicitly
    [main.cpp]
2026-04-10 fix: keep calibrated net_zrl dashboard state consistent
2026-04-10 fix: restore net_erl firmware baseline on main
    [AppConfig.h, PinConfig.h, main.cpp]
2026-04-10 fix: migrate net_erl hall light from dht22 to bme280
    [DeviceConfig.h, PinConfig.h, main.cpp]
2026-04-10 fix: integrate provisioning into net_erl hall light
    [main.cpp]
2026-04-10 fix: align hall light device id with master contract
    [DeviceConfig.h]
2026-04-11 fix: add hall light sensor recovery for bme280 and veml7700
    [DeviceConfig.h, main.cpp]
2026-04-11 chore: tighten hall light teacher-facing config clarity
    [DeviceConfig.h, main.cpp]
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2026-04-12 fix: wire concrete setup pins and bat_sen wake
    [BatSenRuntime.h, PinConfig.h, main.cpp]
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2026-04-13 fix: Device id mistake
    [DeviceConfig.h]
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2026-04-13 docs: tighten public entry points around current proven paths
2026-04-16 firmware: fix kitchen setup storage key
    [main.cpp]
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2026-04-24 firmware: fix esp32 arduino 3 build compatibility
    [main.cpp]
2026-04-25 ci: tighten public hygiene marker check
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2026-05-13 firmware: stabilize net_erl_kitchen i2c realtest path
    [DeviceConfig.h, PinConfig.h, main.cpp]
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2026-05-14 esphome: Zweitlinie vervollstaendigt - Cover-Kalibrierung, Sensorvarianten, Batterie-Geraete
    - Cover: Kalibrierung mit manueller Fahrzeitmessung, Positionssteuerung (set_position), persistente Fahrzeiten
    - Sensoren: BME280, BME680, BME280+VEML7700 Varianten (Temp/Hum/Druck/Gas/Lux)
    - Batterie: bat_sen Fensterkontakt (GPIO-Wake) und Regensensor (periodischer ADC-Wake)
    - Fixes: deep_sleep.enter aus on_boot entfernt, ADC attenuation auf 12db (C3), lux uint16->uint32
    - Docs: README mit Kalibrierungsanleitung, Status-Tabelle, master_compat-Hinweis
2026-05-14 esphome: vollstaendige deutsche Kommentierung aller 12 Firmware-Dateien
    - Ausfuehrliche File-Header mit Projekt, Zweck, Autor (DevOpsOfChaos),
    Datum, Aenderungshistorie und Abhaengigkeiten
    - Section-Kommentare vor jedem Hauptblock (substitutions, globals, script, mqtt)
    - Inline-Kommentare bei substitutions-Variablen (caps-Bitmaske, sensor_mask, etc.)
    - Globale Variablen mit Beschreibung und zulaessigen Werten
    - Skripte mit Funktionsbeschreibung, Parametern und Rueckgabe
    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
2026-05-14 esphome: zweiter Durchlauf - alle if-Bedingungen in Lambda-Code kommentiert
    - smarthome_cover_contract.yaml: 28 if/else + 5 condition:lambda: in
    Kalibrierungs-State-Machine, Kommando-Handler und set_position-Logik
    - esp_net_zrl_cover_example.yaml: 18 if/else + 2 Ternarys + 2 condition:lambda:
    in open_duration/close_duration, on_open/on_close, Teil-Positionierung
    - smarthome_relay_contract.yaml: 8 if/else in set_relay-Type-Coercion
    - bat_sen_rain_example.yaml: 2 Hysterese-Schwellwertpruefungen
    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
2026-05-14 firmware: net_erl-Basistyp vollstaendig deutsch kommentiert
    - main.cpp: 30+ Funktionen mit Doxygen-Headern, 15+ if/else kommentiert,
    NodeState-Struct komplett dokumentiert, Section-Kommentare
    - DeviceConfig.h: alle 22 #defines einzeln kommentiert
    - PinConfig.h: alle GPIO-Pins und Polaritaeten dokumentiert
    - NetErlProvisioning.h: Factory-Funktionen mit Parametern dokumentiert
2026-05-14 firmware: net_zrl-Basistyp deutsch kommentiert (Struktur- und Funktionsdoku)
    - main.cpp: Komplexer File-Header, Section-Header fuer alle 16 Bloecke,
    Enum-Dokumentation (CoverState, CalibrationPhase mit allen Phasen),
    RuntimeState-Struct mit ~70 Feldern einzeln dokumentiert,
    Schluesselfunktionen mit Doxygen-Headern
    - DeviceConfig.h: Header und Zweckbeschreibung (Platzhalter-Datei)
    - NetZrlProvisioning.h: Header und Factory-Funktion dokumentiert
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2026-05-15 fix(net_zrl): 5 fehlende Funktions-Signaturen ergaenzt + MathUtils.h includiert
    [main.cpp]
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2026-05-15 fix: alle Kompilerfehler behoben – ESP-IDF 5.x API, Namespace, Include-Order, setup/loop-Scope
    [BatSenRuntime.h, DeviceConfig.h, NetErlRuntime.h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]
2026-05-15 fix: kritische Firmware-Stabilitaetsprobleme beheben
    - C1: Relais-Dead-Time 300ms in net_zrl (verhindert Motor-Kurzschluss)
    - C2: Watchdog 10s in net_zrl (esp_task_wdt)
    - C3: Button-Pins INPUT_PULLUP in net_zrl (keine Floating Inputs)
    - C4: Watchdog 15s in BatSenRuntime.h (verhindert Batterie-Entleerung)
    - C5: Watchdog 10s in master_firmware (Systemausfall-Schutz)
    - I9: WiFi.reconnect() statt disconnect (erhaelt Credentials)
    - I5: MQTT-Buffer 768→1024 Bytes (verhindert Payload-Truncation)
    - Bonus: net_erl ESP-NOW Callback-Signatur ESP-IDF 5.x kompatibel
    [AppConfig.h, BatSenRuntime.h, main.cpp]
2026-05-15 fix: firmware-zuveraessigkeit verbessern (Review I1-I10)
    - I1: ESP-NOW-Retry (2x, 50ms) fuer HELLO/HEARTBEAT/STATE/EVENT auf allen Nodes
    - I3: Race-Condition Auto-Light vs. Master-CMD (kitchen + hall_light)
    - I4: Sensor-Polling-Timeout-Schutz 2s mit I2C-Recovery (net_sen)
    - I6: SH_ACK_REJECTED_FULL fuer volle Node-Registry (master)
    - I7: BatSen RX-Window 5000→800ms (power-effizienz)
    - I10: ESP-NOW-Stack-Recovery mit Auto-Restart nach 5 Fehlern (alle Runtimes)
    [BatSenRuntime.h, DeviceConfig.h, NetErlRuntime.h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]
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2026-05-15 Stabilize kitchen I2C realtest
    [DeviceConfig.h, PinConfig.h]
2026-05-15 Phase 1 Cleanup: Deutsche Kommentare, Bugfixes, Dedup
    22 Dateien bereinigt und dokumentiert (+1421/-593 Zeilen). .gitignore um sensible Dateien erweitert. Bug B1: toter meta.source-Check entfernt. Bug B2: fehlende Module in settings.js ergaenzt. Duplikate isPlainObject/isCoverDevice bereinigt. Deutsche Header in allen lib/*.js, settings.js, docker-compose.yml, sqlite-Schema. Flow-JSON info-Felder vereinheitlicht. Validierung: node --check 10/10, JSON-Parse 12/12 OK.
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2026-05-16 Stabilize NET-SEN rain station reporting
    [NetSenRuntime.h, main.cpp]
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2026-05-18 net_erl_hall_module: init setup LED pin; fix PinConfig; ensure pinMode for LEDs
    [PinConfig.h, main.cpp]
2026-05-19 Fix hall module motion timer reset
    [BatSenRuntime.h, NetErlRuntime.h, NetSenRuntime.h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]
2026-05-19 Fix net sen weather station reliability
    [NetSenRuntime.h, main.cpp]
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2026-05-19 Fix LED ring hall module sensor recovery
    [main.cpp]
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2026-05-20 Fix master firmware state parsing and retries
    [main.cpp]
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2026-05-24 Fix MQTT commands and ESPHome OTA path
    [DeviceConfig.h, main.cpp, net_erl_hall_module.yaml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]
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2026-05-24 fix: ESPHome und Firmware an MQTT-Vertrag angleichen
    ESPHome Angleichungen an Firmware/Master-MQTT-Vertrag:
    - Neues shared package smarthome_device_event.yaml fuer standardisierte Event-Publizierung
    - Alle ESPHome-Geraete: boot_event und device_event package import
    - net_erl_hall_module: sensor_mask THLM, State-Felder auto_flags/report_interval_s/auto_on_lux_threshold, request_id-Validierung und Relay-/Motion-Events korrigiert
    - net_erl_hall_module_led_ring: State-Felder und Motion/Relay/Auto-Light-Events vereinheitlicht
    - net_sen_weather_station: rain_raw im State, rain_detected Event und einheitliche request_id-Validierung
    - net_zrl_shutter_module: Cover-Events und ESPHome-select API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
    [main.cpp, net_erl_hall_module.yaml, net_erl_hall_module_led_ring.yaml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]
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2026-05-24 refactor: Echte Deduplizierung, Dead-Code-Sweep, Namensfixes, Bugfix I2C-Takt
    - smarthome_command_dispatch.h: neues C++ Shared-Header mit gemeinsam genutzten Funktionen
    (smarthome_extract_request_id, smarthome_validate_master_mac, smarthome_is_hex)
    - contract_base: smarthome_command_dispatch.h in includes, setup_master_mac nutzt Shared-Funktion
    - Alle 6 Device-YAMLs + cover_contract: request_id-Extraktion und master_mac-Validierung
    auf Shared-Funktionen umgestellt (~200 Zeilen Duplikation eliminiert)
    Firmware Basetypes:
    - NetErlRuntime.h: 5 ungenutzte using-Declarations entfernt, dead #ifndef-Block (10 no-op Stubs)
    entfernt, Kommentar fuer NET_ERL_USE_ISR_CMD_QUEUE ergaenzt
    -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
    [BatSenRuntime.h, DeviceConfig.h, NetErlRuntime.h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]
2026-05-24 refactor: Strukturelle Fixes - Dedup, Seq-Num, Monolith-Split, Caps-Bugfix
    NetSenRuntime:
    - sendeState(): Standard/Extended-Code-Duplizierung per fillCommonSensorFields-Lambda eliminiert
    - fillCommonSensorFields() extrahiert 4 gemeinsame Felder (node_id, temp_01c, hum_01pct, lux)
    NetErlRuntime + BatSenRuntime:
    - sendePaketMitRetry(): fragile Pre-Decrement-Sequenznummer-Logik durch savedSeq-Pattern ersetzt
    (Retries verwenden jetzt garantiert dieselbe Sequenznummer, kein Off-by-One-Risiko)
    BatSenRuntime:
    - setup() von 96 auf 33 Zeilen reduziert durch Extraktion in 4 static Hilfsfunktionen:
    setupBootUndStatus(), setupWatchdog(), setupProvisioning(), setupBootLog()
    - aktiviereWakeQuellen()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
    [BatSenRuntime.h, DeviceConfig.h, NetErlRuntime.h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]
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2026-05-25 Fix master device ID validation
    [main.cpp]
2026-05-25 docs: Vollständige Firmware- + ESPHome-Dokumentation, letzte Code-Fixes
    Dokumentation:
    - docs/firmware/ (12 Dateien): ESP-NOW-Protokoll, DeviceTypes/Capabilities,
    MQTT-Contract, 7 Geräte-Docs inkl. Master-Firmware
    - docs/esphome/ (7 Dateien): Architektur-Übersicht, 6 Geräte-Docs
    - docs/public/04_mqtt_topics.md: aktualisiert (Events, Statuscodes, Geräte-IDs)
    Code-Fixes (letzte Runde):
    - DeviceTypes.h: SH_CAP_GAS (0x4000) definiert
    - Protocol.h: Totes TlvEntry + SH_TLV_* + SH_MSG_TIME entfernt
    - Alle ESPHome YAMLs: hardware_fault von contract_fault getrennt
    - LED-Ring YAML: "Technikerarbeit"-Kommentare neutralisiert
    - master_firmware: auto_flags-Extraktion + State-JSON
    - net_zrl: COVER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
    [net_erl_hall_module_led_ring.yaml]
2026-05-25 fix: ESPHome + Firmware Angleichungen – Events, State, Fault, Caps, Refactoring
    ESPHome (11 Dateien):
    - smarthome_device_event.yaml: Events für alle Geräte (18 Typen, 5 Trigger)
    - smarthome_command_dispatch.h: Shared C++ Header (MAC-Validierung, request_id)
    - smarthome_cover_contract.yaml: cover_mode, open/closed States, hardware_fault
    - smarthome_contract_base.yaml: on_connect, command_dispatch include
    - smarthome_command_ack.yaml: ACK-System
    - setup_portal.h: strncpy-Nullterminierung, Magic-Number-Kommentare
    - Alle 6 Device-YAMLs: Events, hardware_fault, on_connect, caps-Fixes,
    sensor_mask-Fixes, auto_flags, report_interval_s, auto_on_lux_threshold,
    LED-Null-Sentinel, contract_faul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
    [main.cpp, net_erl_hall_module.yaml, net_erl_hall_module_led_ring.yaml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]
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2026-05-25 hardware: add KiCAD project files for all basetypes
    Copy original KiCAD project files from private design repo:
    - shared/modularer_steuerkreis/ (shared control board for all relays)
    - shared/esp32-c3-supermini/ (THT adapter for ESP32-C3 module)
    - net_erl/leistungskreis/ (1-relay power board)
    - net_zrl/leistungskreis/ (2-relay power board, cover/shutter)
    - net_sen/kicad/ (mains-powered sensor board)
    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
    [ESP32-C3_SUPERMINI_TH.step, Leistungskreis.kicad_sch, Leistungskreis_1Relai_Steuerung.step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]
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2026-05-25 refactor: rename all KiCAD files to clean basetype names
    - shared/modularer_steuerkreis: mod_Steuerkreis_ESP32.* → steuerkreis.*
    - net_erl/leistungskreis: Leistungskreis_1Relai_korrektur.* → leistungskreis.*
    - net_zrl/leistungskreis: Leistungskreis_korrektur.* → leistungskreis.*
    - net_sen/kicad: Sensor_all_Netz_ESP32.* → net_sen.*
    - bat_sen/kicad: Sensor_all_ESP32.* → bat_sen.*
    - SVG schematics renamed to match
    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
    [bat_sen.kicad_pcb, bat_sen.kicad_sch, leistungskreis.csv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]
2026-05-25 hardware: remove outdated production files from net_erl/net_zrl leistungskreis
    Remove pre-correction generated files:
    - leistungskreis.csv (old BOM exports)
    - fp-info-cache (outdated footprint cache, 3.8MB each)
    - fabrication-toolkit-options.json (old plugin config)
    These will be regenerated from the corrected KiCAD designs.
    [leistungskreis.csv]
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2026-05-25 hardware: add per-device KiCAD project copies for customization
    Each device now has its own copy of the basetype KiCAD files:
    - NET-ERL-001/002: leistungskreis (1-relay) + steuerkreis (shared)
    - NET-ZRL-002: leistungskreis (2-relay) + steuerkreis (shared)
    - NET-SEN-002: net_sen board + Bilder
    - bat_sen_01/02: bat_sen board + Pinbelegung + Code
    Includes README with per-device customization checklist.
    [Leistungskreis.kicad_sch, Steuerstromkreis.kicad_sch, bat_sen.kicad_pcb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]
2026-05-25 hardware: add 2nd schematic sheet (Beschaltung) for device-specific circuitry
    Shared steuerkreis and both NET-ERL device copies:
    - New beschaltung.kicad_sch (page 2) with global labels for all 13 GPIOs,
    3V3, 5V0, GND -- ready for sensor/actuator placement
    - Root sheet extended with matching global labels for cross-page
    net connection
    - .kicad_pro updated to register the new sheet
    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
    [beschaltung.kicad_sch, steuerkreis.csv, steuerkreis.kicad_sch]
2026-05-25 Revert "hardware: add 2nd schematic sheet (Beschaltung) for device-specific circuitry"
    This reverts commit 001a2784620b539354ebf772e483699f9b3c3a2f.
    [beschaltung.kicad_sch, steuerkreis.csv, steuerkreis.kicad_sch]
2026-05-25 hardware: fix NET-ERL device steuerkreis copies, remove stray generated files
    - Replace NET-ERL-001/002 steuerkreis files with clean copies from shared/
    - Remove stale beschaltung remnants from failed schematic edit
    - Remove stray steuerkreis.csv from NET-ZRL-002
    [01_Controllerplatine.kicad_sch, 02_Externe_Module_und_Verdrahtung .kicad_sch, schaltplan.kicad_sch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]
2026-05-25 chore: remove generated fp-info-cache and backup dirs from device kicad copies
    [02_Externe_Module_und_Verdrahtung .kicad_sch]
2026-05-25 fix: align ESPHome setup and device behavior
    [AppConfig.h, DeviceConfig.h, PinConfig.h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]
2026-05-25 docs: README neu geschrieben - Projektübersicht, Architektur, Quick Start
    [leistungskreis.kicad_sch]
2026-05-26 hardware: 3D-Modelle aus Desktop importiert (14 .3mf-Dateien)
    - net_erl: 9 Dateien (Hall-Module + LED-Ring-Variante)
    - net_zrl: 5 Dateien (Shutter-Module)
    - README mit Übersicht
    [Abdeckung.3mf, BODY_FRONT_CONTROL_BASE_V2.3mf, Basis.3mf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]
2026-05-27 Fix hall module sensor startup diagnostics
    [DeviceConfig.h, NetErlRuntime.h, main.cpp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]
2026-05-27 fix: extend ENS160 warmup for hall LED ring
    [DeviceConfig.h, net_erl_hall_module_led_ring.yaml]
2026-05-27 fix: I2C bus robustness for both hall module devices
    Root causes fixed in LED ring variant: ENS160 begin() corrupts Wire,
    no WDT reset during I2C ops, no bus recovery, no stuck-SDA handling.
    Ported relevant fixes to hall module (BME280/VEML7700): Wire clock
    5 kHz, Wire timeout 50 ms, SCL pulse recovery, sensor health
    tracking, WDT reset in poll loop, graceful degradation.
    [DeviceConfig.h, main.cpp]
2026-05-27 fix(esphome): I2C sensor health tracking with stale detection for LED ring
    Replace one-way latch env_has_* flags with runtime health tracking:
    - last_*_update_ms timestamps set in every sensor on_value handler
    - 30s monitor interval detects stale sensors (no update in timeout)
    - Fail counters distinguish transient from permanent failures
    - Relative warmup timers (bme680_init_ms, ens160_init_ms) for
    correct warmup restart after sensor recovery
    - sensor_fault events (event_type=15) emitted on stale detection
    - hardware_fault now properly reflects runtime sensor state
    [net_erl_hall_module_led_ring.yaml]
2026-05-28 NET-ERL-020: Crash-Fix + LED-Ring + I2C + ENS160 + Server-Dashboard
    - Crash-Fix: esp32_rmt_led_strip -> fastled_clockless, effects:-Block entfernt
    (AddressableLightEffect::start_internal() crashte auf ESP32-C3/2026.5.1)
    - api:/debug:-Bloecke entfernt (wiederhergestellt nach Crash-Analyse)
    - ota: wiederhergestellt
    - LED-Ring: 30% Helligkeit, Animation per interval+get_output() statt effects
    (ringScale/ringColor/ringDimColor an Firmware main.cpp angeglichen)
    - I2C: 10kHz stabilisiert (optimale Frequenz fuer 2kO Pull-ups)
    - ENS160: Temperatur/Feuchte-Kompensation hinzugefuegt
    - Auto-On: 5s Lux-Timeout-Fallback bei VEML7700-Ausfall
    - Boot-Test: RGB-Sweep analog Firmware ensureRingInitialized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
    [net_erl_hall_module_led_ring.yaml, smarthome_contract_base.yaml]
2026-05-28 fix: server_contract_smoke.ps1 - process.argv.slice(1)->slice(2)
    - Bug: node -e schiebt das eval-Skript als argv[1], Argumente starten erst bei argv[2]
    - slice(1) inkludierte das Skript als deviceId → DB-Check schlug immer fehl
    - Fix: slice(2) korrekt
    [01_Controllerplatine.kicad_sch, Externe_Beschaltung.kicad_sch, Leistungskreis.kicad_sch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]
2026-05-28 Server: SQLite-Migration fuer gas_ohm/aqi/tvoc_ppb/eco2_ppm
    Die Spalten waren im Schema (00_schema_phase1.sql) definiert, aber die
    ensurePhase1Migrations() in docker-compose.yml hatte keine ALTER TABLE-
    Aufrufe dafuer. Existierende Datenbanken hatten die Spalten daher nicht.
    Dashboard assignIfPresent() ueberspringt null-Werte -> keine Anzeige.
    Fix: ensureColumn() fuer alle vier Spalten in docker-compose.yml ergaenzt.
    Nach docker compose down && up laeuft die Migration automatisch.
2026-05-28 NET-ERL-020: LED-Phasen-Modulo-Fix (Animation hing nach 45s)
    phase_ms hatte kein % total_ms, wodurch die Animation nach einem
    Zyklus dauerhaft in der Feuchte-Phase stecken blieb. Die Firmware
    (updateRingComfortDisplay) nutzt Modulo, ESPHome-Code hatte es nicht.
    Phase zykliert jetzt korrekt: AQI -> Temp -> Feuchte -> AQI ...
    [net_erl_hall_module_led_ring.yaml]
2026-05-28 NET-ERL-020: Deep-Sleep-Recovery entfernt (Endlos-Reboot)
    Deep Sleep setzt I2C-Bus nicht zurueck, weil Sensoren weiterhin Strom
    haben und SCL auf LOW halten. Recovery fuehrte zu Endlos-Reboot-Loop.
    Stattdessen: Geraet laeuft nach OTA mit Fault weiter, Stromlos-Schalten
    nach OTA wird als Workaround akzeptiert.
    [net_erl_hall_module_led_ring.yaml]
2026-05-28 NET-ERL-020: Code-Review-Fixes BUG-001 bis BUG-010
    BUG-001 (KRITISCH): refresh_led_ring aus ENS160-Handlern entfernt
    -> Root Cause des 20-Minuten-Faults: ENS160-Warmup-Ende loeste
    Aktivitaetsburst aus (3x MQTT + 3x Light State Machine),
    ueberlastete Single-Core ESP32-C3 -> I2C-Timeout -> Fault.
    BUG-002 (KRITISCH): hardware_fault aus mqtt.publish_json-Payload
    in separates lambda-Step ausgelagert (Seiteneffekt-Bug).
    BUG-003 (KRITISCH): setup_portal.h esp_wifi_start() mit
    esp_wifi_get_mode()-Guard abgesichert.
    BUG-004: set_config Validate-First Apply-Second Pattern
    BUG-005: env_lux Sentinel von env_has_lux entkoppelt
    BUG-006: AQI x>0 Guard + Range-Check 1-5 korrigiert
    BUG-007: atoi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
    [net_erl_hall_module_led_ring.yaml, setup_portal.h]
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2026-05-28 NET-ERL-020: Source-Validierung + Auto-On-Fix + I2C 10kHz
    - BME680 on_value: Garbage-Werte abgefangen (temp -40..85, hum 0-100, press 300-1100)
    - evaluate_auto_on_from_lux jetzt periodisch im 50ms presence_poll
    - I2C 10kHz (einziger stabiler Takt fuer 2kO/Multisensor-Bus)
    - hardware_fault im LED-Interval alle 120ms neu berechnet
    - Ring-Fault nur bei BME680-Ausfall (nicht VEML7700)
    - MQTT: contract_online-Guard, Wert-Validierung
    - LED-Debug-Logging alle 10s
    [net_erl_hall_module_led_ring.yaml]
2026-05-28 NET-ERL-020: ChatGPT/Claude Repair Drop-in
    - contract_online nur via MQTT connect/disconnect (nicht on_boot)
    - LED-Interval: defekter rn-Kommentar repariert, hw_fault 120ms Recalc
    - LED-Ring: Re-Trigger alle 30s bei dauerhaft HIGH PIR
    - AQI-Farbschwellen an ENS160-Skala 100-500 angepasst
    - BME680/VEML7700/ENS160: update_interval never + 53s/59s/61s Staggering
    - lux_dark_valid Reset bei VEML7700-Stale
    - api: aus contract_base entfernt (MQTT-only)
    - smarthome_device_event: event_seq im Payload
    [net_erl_hall_module_led_ring.yaml, smarthome_contract_base.yaml]
2026-05-28 fix: GitHub Actions workflow - false positives behoben
    - protocol-paths: PROTOKOLL/ subdirectory vom ls-files ausgeschlossen
    - internal-markers: KiCad fp-info-cache von grep ausgeschlossen (ai/ in URLs)
    [Alle_Teile.3mf]
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2026-05-30 öffentliche Präsentation bereinigt: KI-Referenzen entfernt, READMEs optimiert, Firmware als Hauptlinie, ESPHome als Alternative mit Disclaimer
    [Abdeckung_oben_V2.3mf, Abdeckung_unten_V2.3mf, Abstandshalter.3mf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]
2026-06-02 Fix BAT-SEN dashboard state handling
    [AppConfig.h, BatSenRuntime.h, DeviceConfig.h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]
2026-06-02 docs: correct NET-ZRL touch button logic
2026-06-02 fix: stabilize bat sensor wake handling
    [BatSenRuntime.h]
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

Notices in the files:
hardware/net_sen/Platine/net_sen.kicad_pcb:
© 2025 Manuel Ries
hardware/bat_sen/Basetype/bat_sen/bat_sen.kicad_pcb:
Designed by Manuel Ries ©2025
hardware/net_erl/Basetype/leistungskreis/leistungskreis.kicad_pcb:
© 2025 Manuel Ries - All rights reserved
